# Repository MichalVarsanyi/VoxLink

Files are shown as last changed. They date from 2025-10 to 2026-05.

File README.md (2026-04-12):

# Protocol Parameters
> [!WARNING]  
> Parameters are still subject to change!

- During programming, exceeding internal clocking speeds of 100MHz on the iCE40UL1K-CM36AI FPGA proved to be virtually impossible. In the future, instantiating the hard IP I2C blocks in the FPGA silicon may increase the speed. Realistically, however, switching to a higher speed grade of FPGAs will probably be the best option.

### **Speed**: 50-100 MHz
$$
f_{\mathrm{bandwidth}} = 2 \cdot f_{\mathrm{sensor}} \cdot N_{\mathrm{devices}} \cdot (L_{\mathrm{header}} + L_{\mathrm{data}}) 
$$
$$
9.6 \mathrm{ MHz} = 2 \cdot 1000 \mathrm{ Hz} \cdot 100 \cdot (16 + 32) 
$$

It may seem that 50-100 MHz is unreasonably fast; however, just 40 sensors at 9 kHz get very close to this ballpark. It is difficult to determine what may increase the bandwidth in the future, so it's better to have an excess than to have too little bandwidth. (Resulting bandwidth is double the calculated value to keep a reasonable margin of safety)

$$
34.56 \mathrm{ MHz} = 2 \cdot 9000 \mathrm{ Hz} \cdot 40 \cdot (12 + 32) 
$$

### **Communication**: Full-Duplex 
   - Support for discovery
   - Configuration
### **Host**: 1
### **Sensor Branches from Host**: 10
### **Sensor Branch Length**: To be specified (20? 100?)

<!-- check something like profibus -->
<!-- zdielana zbernica vs serial -->
<!-- master can direct the communication -->
<!-- token approach -->

<!-- daisy chain: -->
<!-- what will be the worst case delay -->

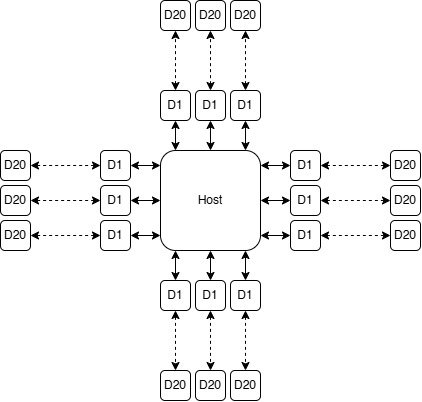
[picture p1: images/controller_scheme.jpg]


# Communication Protocol
### Circular Master-Slave (Daisy Chain)
The Circular Master-Slave protocol offers unprecedented **advantages** when it comes to **timing** and **synchronization**. The Master sends out a packet containing the RX message to the sensor. When the sensor receives the data frame, it reads the content and rewrites it with TX. Each node has a place assigned where it reads and writes data. The discovery would also be easy, as the algorithm would look at the first position, where there are all zeros, and would write its address there. The next sensor would see this as talking and would use the next packet.

The main reason why this protocol **has not been chosen** is the inefficiency when it comes to **different clock domains**. Let's say we have a fast IMU, which sends data at 1 kHz, and the rest of the sensors are tensometers sending data at 10 Hz. Because of the fast link, the tensometers would have to send 99 **empty packets for each data packet**, as the communication would have to happen at the frequency of the fastest link. This wastes the bandwidth, which is of great value when a large number of devices are connected.

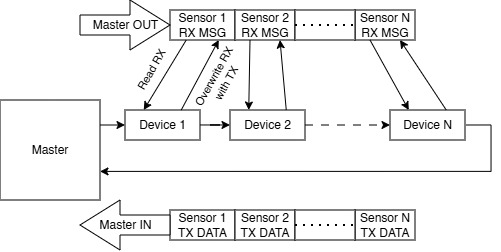
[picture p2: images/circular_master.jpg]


### Direct Master-Slave
The Direct Master-Slave is very **versatile to sampling frequency and packet size variance** between individual nodes. Furthermore, it is easier to negotiate a custom packet size with the slave device. Having the freedom to implement changes like these is invaluable in the prototyping stage. This is why **we will implement this protocol!** Moreover, we are **not wasting bandwidth**, as we are directly talking to the host device with no middleman.

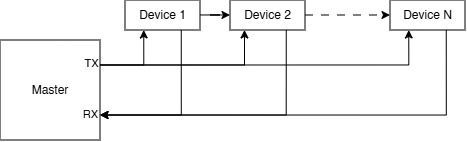
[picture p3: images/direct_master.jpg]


# Protocol Sections
 - Instance ID - Number assigned after self-discovery
 - Board ID - Unique board identifier (can be requested but is not in the header)
 - Timestamp - Identification number of the packet
 - Data

| 12 Bits | 12 Bits | 8 Bits | 64 Bits | 16 Bits |
|:---:|:---:|:---:|:---:|:---:|
| Address | Timestamp | Command | Data | CRC |

# Physical Layer
### Ethernet
Ethernet cables offer great **plug-and-play** connectivity while retaining **excellent signal integrity**. They come in a variety of sizes, however, the older cables do not feature a twisted pair configuration. Furthermore the modern CAT-5 cable is **bulky and difficult to route** inside the Voxel.

### FFC
FFC (Flexible Flat Cable) cables offer **good signal integrity** and can facilitate fast transmission speeds. Their flat profile allows for **easy integration** it the Voxel cells. A disadvantage is **difficult removal/insertion**, which is important for prototype devices. Furthermore, special, shielded cables are rather **expensive**.
## Wire Connections
### 8P8C
- 1-2 - TX
- 3-4 - RX
- 5-6 - CLK
- 7-8 - PWR

### 4P4C (Manchester Encoding)
- 1-2 - TX + Power
- 3-4 - RX

# Microcontroller options
## **Lattice FPGA (iCE40) - (Chosen Platform)**
- **Cost**: 2.22$ to 3$
- **Speed**: 185 MHz
- **Flash Memory**: Used but not needed in the final design

After careful consideration, the **Lattice FPGA** was chosen as the final platform for the sensor board over traditional MCUs. To achieve the target speed in the ballpark of 50 MHz, the microcontrollers would have to be programmed in assembler. In this regard, **Verilog**, in which the FPGA chips will be programmed, is much **easier to read**, understand, and modify. A nice feature is the **integrated NVCM** (Non-Volatile Configuration Memory) inside the FPGA, thus no external SPI Flash NVCM is needed!

Part number: **ICE40UL1K-CM36AI**

##  Rasperry Pi Pico (RP2350)
- **Cost**: 0.90$
- **Speed**: 150 MHz (Neil said 250 MHz overlocking is OK)
- **Flash Memory**: Needed
##  STM32H5
- **Cost**: 2.84$
- **Speed**: 250 MHz
- **Flash Memory**: Not needed

# Hardware Design

## High Level Overview
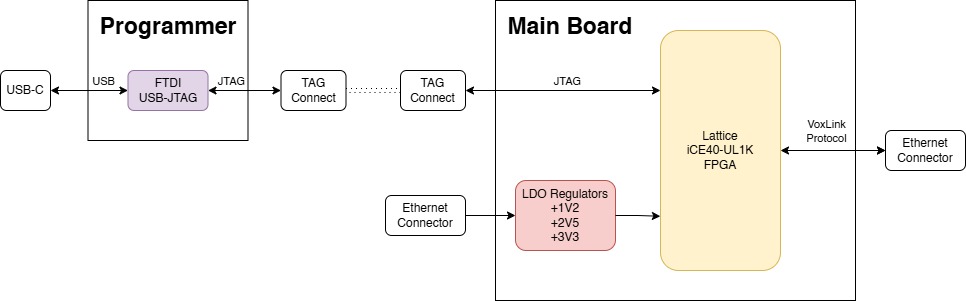
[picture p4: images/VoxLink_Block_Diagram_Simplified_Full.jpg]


### Connector selection
**Rule of thumb: $l_{\mathrm{crit}}$** is $\frac{1}{12}^{\mathrm{th}}$ of a signal wavelength in the dielectric material $\varepsilon$. The effective dielectric constant $\varepsilon$ for an outer-layer trace is approximately 3.3

$$
l_{\mathrm{crit}} \mathrm{ [m]} = \frac{c\mathrm{ [m/s]}}{f_{\mathrm{max}}\mathrm{ [Hz]}} \cdot \frac{1}{\sqrt{\varepsilon}} \cdot \frac{1}{12}
$$

**Rise & fall times rule of thumb:**

$$
f_{\mathrm{max}} \mathrm{ [GHz]} \approx \frac{0.5}{t_{r/f} \mathrm{ [ns]}}
$$

**Clock-to-rise-time rule of thumb:**

$$
t_{r/f} \mathrm{ [ns]}\approx \frac{1}{10\cdot f_{\mathrm{clk}}\mathrm{ [GHz]}}
$$

**Calculation for the maximum protocol clock:**

$$
1 \mathrm{ [ns]}\approx \frac{1}{10\cdot 0.1\mathrm{ [GHz]}}
$$

$$
500 \mathrm{ [MHz]} \approx \frac{0.5}{1 \mathrm{ [ns]}}
$$

$$
27.5 \mathrm{ [mm]} \doteq \frac{3\cdot 10^{8}}{1\cdot 10^{6} \mathrm{ Hz}} \cdot \frac{1}{\sqrt{3.3}} \cdot \frac{1}{12}
$$

This means the transmission line will appear as a **lumped element** (no impedance matching needed as the reflections are negligible) only for **traces shorter than 27.5mm**. Anything **above** this length needs to be treated as a **distributed element** and requires **impedance matching**.

> [!IMPORTANT]
> Impedance control is required for both the cable and the connector assembly!

| Ethernet | USB |
|:---:|:---:|
| 100 Ω ± 15 Ω | 90 Ω ± 5 Ω |

Differential Impedance $Z_{\mathrm{diff}}$ Comparison

$$
Z_{\mathrm{diff}} = 2\cdot (Z_{0}-Z_{\mathrm{coupling}})
$$

## Schematic Diagram - Sensor Board

### eFuse

The eFuse circuit protects the onboard LDOs from excessive overvoltages. The overvoltage protection (OVP) threshold has been set to 5.4V. This gives enough headroom for the absolute maximum voltage of the LDO at 6.5V. The undervoltage lockout (UVLO) threshold has been set to 4V.

**It is crucial for C101 and R101 to be rated at 100V!** Long enough cables can cause surges at the capacitor of over double the input voltage. The limiting resistor will aid in this issue. For further details, refer to the AN88F application note from Analog Devices.

### Power Section

FPGAs require a **specific voltage** to enable their operation. In this design, we are working with 4 different voltage levels:

| 5V | 3.3V | 2.5V | 1.2V |
|:---:|:---:|:---:|:---:|
| Supply voltage from the power cables | The I/O voltages (used by GPIO pins) | The Non-Volatile Configuratio Memory (NVCM) voltage | The FPGA core voltage | 

This version of the board features a 2.5V voltage regulator, which is usually omitted in many designs. The absolute maximum rating of the $V_{\mathrm{PP\_2V5}}$ supplying the NVCM voltage is 2.3V to 3.46V. This enables the pin to be directly connected to the 3.3V voltage regulator. To get the voltage closer to 2.5V, a diode is placed from the 3.3V to the NVCM supply, which facilitates a drop of roughly 0.7V.

There are three I/O banks on the FPGA. The Bank 0, Bank 1, and Bank 2; they all can have different voltage levels connected to them. In this board, all of the I/O banks are running at 3.3V; however, the power is sectioned into VCCIO0, VCCIO1, and VCCIO2. This is to indicate the exact I/O bank that the voltage is tied to, should any future changes be made.

Furthermore, the power supplies are brought up in the order specified in the datasheet. However, I have seen FPGA boards such as the TinyFPGA-BX not follow the correct follow-up sequence. I have also heard that an incorrect power-up sequence will trigger a protection diode on the inside of the FPGA, which can become a problem during prolonged power-up, which is a rather unusual case. Nonetheless, the correct power sequence was programmed using the enable chips. The $\mathrm{V}_{\mathrm{EN(LOW)}} = 0.3 \mathrm{V}$ and $\mathrm{V}_{\mathrm{EN(HIGH)}} = 0.9 \mathrm{V}$, so the 1.2V FPGA core voltage can be used as an enable signal of the next regulator. Below is the datasheet recommendation:

> It is recommended to bring up the power supplies in the following order. Note that there is no specified timing delay
between the power supplies; however, there is a requirement for each supply to reach a level of 0.5 V or higher.
before any subsequent power supplies in the sequence are applied.

- $\mathrm{V} _{\mathrm{CC}}$ and $\mathrm{V} _{\mathrm{CC\_PLL}}$
- $\mathrm{V_{CCIO1\_SPI}}$
- $\mathrm{V} _{\mathrm{PP\_2V5}}$
- Other Supplies

A delay block is introduced to delay the startup of the FPGA chip. This is necessary as the FPGA suggests the memory needs to be ready to accept commands after 10us of the FPGA power-up. Since the NOR flash chip is powered from 3V3, which is the same voltage powering the $\mathrm{SPI-V} _{\mathrm{CCIO1}}$, we need to consider the $t_{VTR} = 150 \mu \mathrm{S}$ which is the time from($\mathrm{V_{CC(MIN)}}$ to Read). The delay value was chosen as 20ms, as the capacitor selection for such a time is 32pF. Having a shorter time means selecting a smaller capacitor, which may become unreliable due to parasitic board capacitances.

### System

In this section, the majority of the FPGA chip is routed. One of the most important parts is the SPI Flash memory. As the Lattice iCE40 UltraLite is a low-cost device, the flash memory peripheral is not programmed by the chip directly. In order to program the FPGA, the $\overline{\mathrm{CRESET}}$ needs to be pulled LOW. This puts the FPGA in reset, and the FLASH_... signals can be used to program the memory. When done, the FPGA reset is de-asserted, and the FPGA loads the configuration from the memory upon power-up.

An external oscillator is used to provide a more stable clock than the integrated FPGA reference clocks. An oscillator needs to be used as the FPGA does not have support for crystal oscillators. The G (GBUF) marking on the pins indicates an internal G-Buf FPGA fabric connection for high-speed routing. This is a special routing layer inside the FPGA that can carry signals up to 185 MHz. The internal system clock, as well as the external clock for the PLL, needs to be connected via this layer.

The VoxLink Ethernet Connection is the physical interface of the sensor board. Currently, the board is configured to utilize the internal differential comparators of the FPGA (A and B pins). Note that the IOB_6A and IOB_7B_G5 form a one differential comparator pair. Ideally, a differential pair will be used to carry the signal to minimize interference. A no-placement (NOP) resistors are used to give the option of a single-ended signal, where the inverted rail can be connected to ground to improve the return path.

### Sensor

The sensor page is the connection of the BNO086 IMU to the FPGA. A reference design from the Adafruit breakout board was chosen.

> CEVA recommends using a crystal with tolerance
50ppm with 12.5pF capacitor loading.

A crystal with a specified load capacitance of 12.5pF and a PPM of 20 was chosen to satisfy the datasheet value. The crystal load capacitors are then calculated based on the following equation:

$$
(12.5p \mathrm{F Load Capacitance} - 5p \mathrm{F Stray Capacitance}) * 2 = 15p \mathrm{F Load Capacitors}
$$

### Connectivity

Two possible architectures were discussed in the earlier sections: the BUS topology and the DAISY chain approach. The sensor evaluation board has an integrated PCIe-Gen4 switch IC, which can rewire the connection from one architecture to another. The images below show the different connections facilitating each approach. Within both architectures, both TX and CLK differential pairs are always connected from the input to the output. This allows us to change the architecture with just one DPDT switch. Having used a dedicated IC, this will ensure better impedance control than using a mechanical switch.

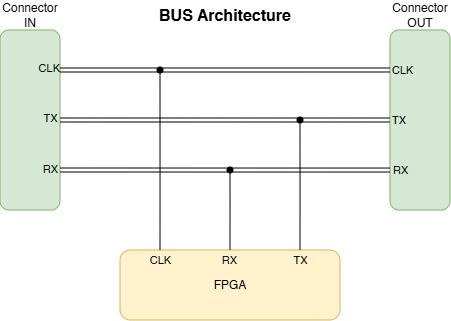
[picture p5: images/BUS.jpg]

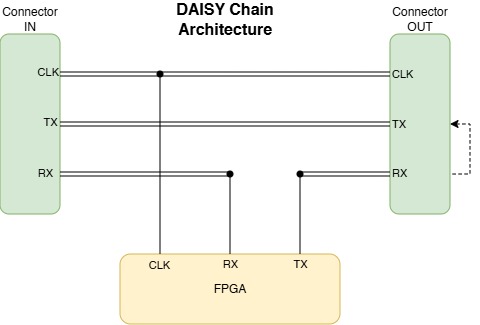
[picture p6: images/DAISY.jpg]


## Schematic Diagram - Programmer Board
An FTDI223HQ IC was used as the serial-to-USB converter. To reduce the overall cost of each sensor board, an external programmer was designed. An EEPROM is attached to the FTDI chip, which can store basic configuration such as the device name and version. This information can be configured using the [FT_Prog](https://ftdichip.com/utilities/#ft_prog) software. A 93LC56B EEPROM IC was selected based on datasheet recommendations, and the chip is merely optional. The FTDI chip does not appear to store any critical information within.

A Tag Connect TC2030-IDC programming cable will be used to program the SPI Flash memory. The pinout of the IDC connector was taken from the datasheet, and the correct pin assignment has to be tested on the hardware implementation, as its correctness is not yet confirmed. An additional 8-pin PicoBlade connector was used to have access to the $\mathrm{CDONE}$ and $\overline{\mathrm{CRESET}}$ signals (the Tag Connect only offers 6 pins), as well as try out different programming interfaces. The manufacturer's evaluation board uses all 8 signals; however, it may be possible to use only 6.

## PCB Layout

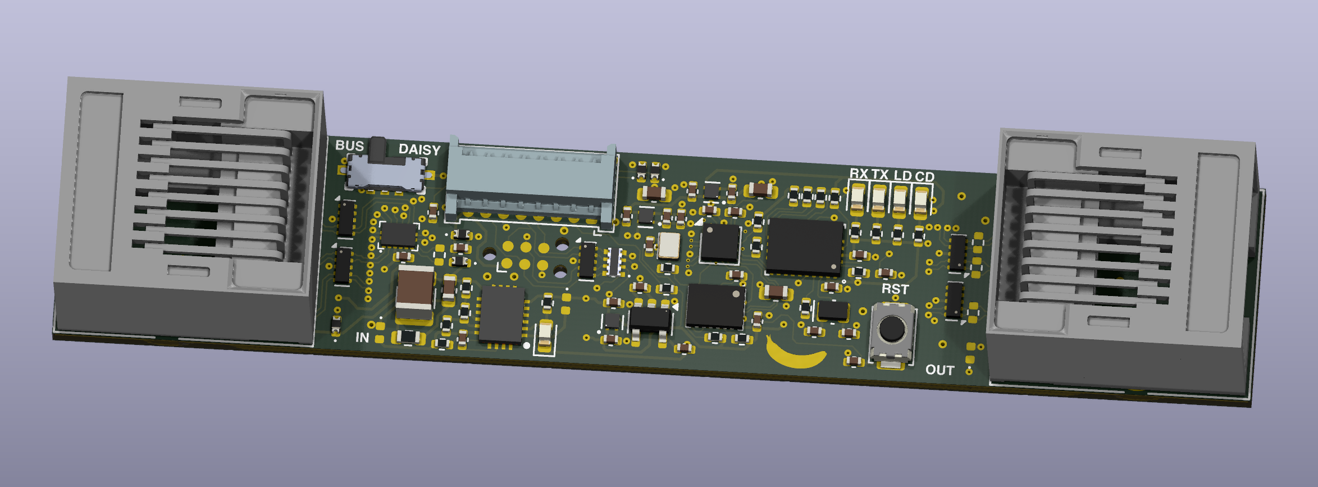
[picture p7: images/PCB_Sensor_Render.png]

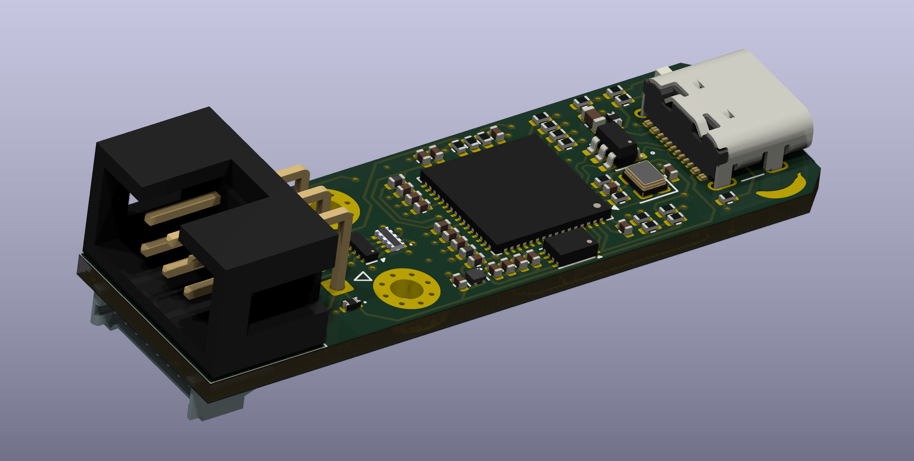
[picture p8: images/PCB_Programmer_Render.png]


### Controlled Impedance

Since Ethernet connectors were used in the design, the differential pairs were routed with a controlled differential impedance of $100 \Omega$. The stackup for both the programmer and the sensor boards can be seen below. An impedance calculator from the PCB manufacturer was used to determine the correct trace parameters. The differential pair trace width used in the design was 0.1mm, and the gap was 0.2mm. 

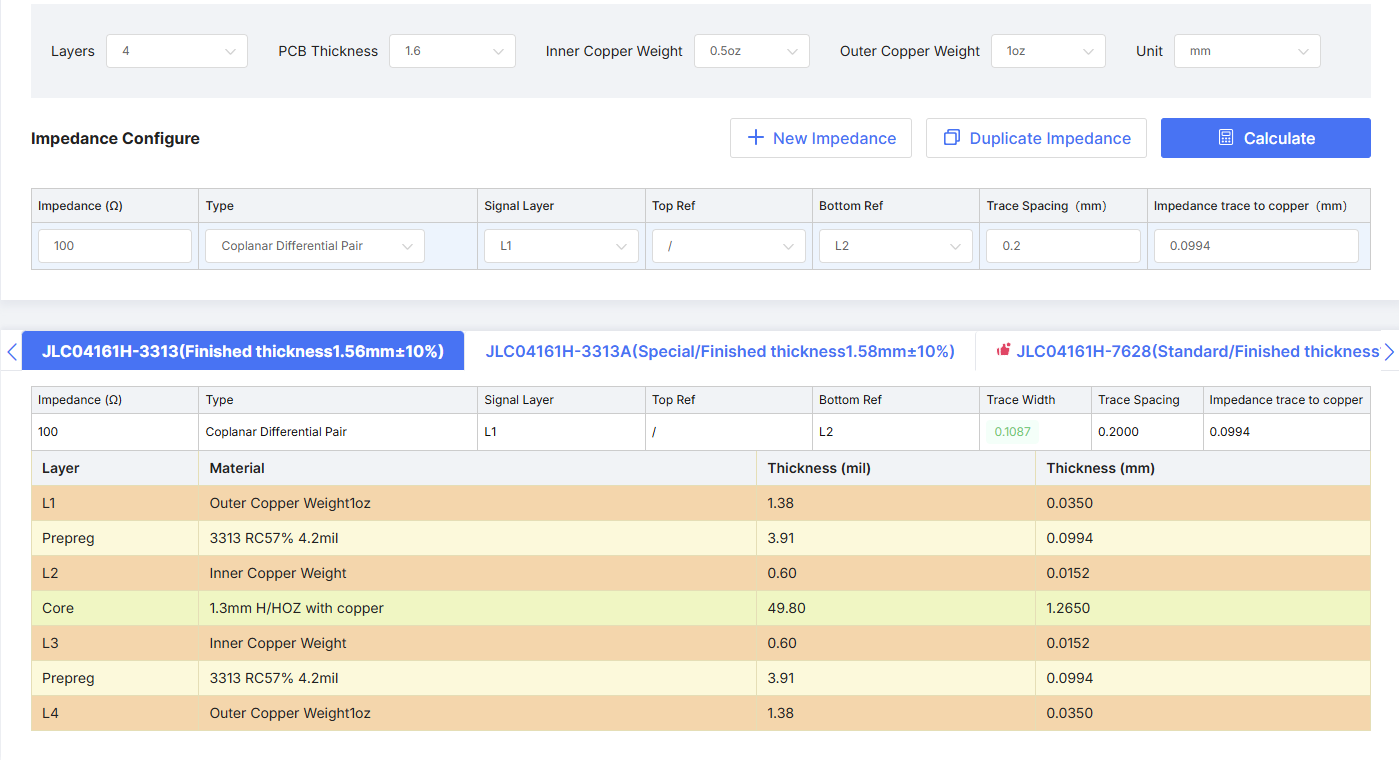
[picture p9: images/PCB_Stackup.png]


### Constraints

The constraints were taken from the manufacturer's capabilities page and copied into KiCad. The exact values can be seen below. In the further section of **PCB Rework** I had to use plugged vias. Even though the annular ring was 0.05mm, the design was still manufacturable, I believe due to the via-in-pad (VIP) being 0.25mm.

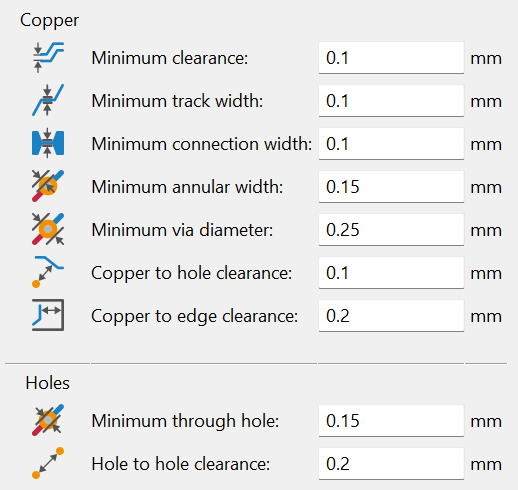
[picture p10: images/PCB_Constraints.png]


### PCB Rework

After talking to the manufacturer, I was informed that the custom BGA footprint I have designed was **not manufacturable**. The pad size I used for the fanout was 0.1mm, and the minimum was 0.25mm, which meant I had to rework my PCB design. Unfortunately, **I had to use capped in-pad vias with 0.15mm drill size** to get around this issue. This is right at the manufacturer's limits, which increases the cost by a few euros; however, I do not see this as a problem with the evaluation design I am ordering. Below is an image provided by JLCPCB engineers of my flawed footprint design.

After submitting the new design, I received another email from the manufacturer asking about the plugged vias. My requirements were **tented epoxy-filled and capped vias** (applied to all via sizes). I also decided to **keep the solder mask opening for all pads and vias**. Removing the solder mask from underneath the BGA would create a more uniform solder layer, as the minimum guaranteed solder bridge is 0.1mm, and I had areas with 0.06mm under the pad. However, I believe the residual solder mask would prevent accidental solder bridges. Nonetheless, for an experimental board, this does not pose a critical problem.

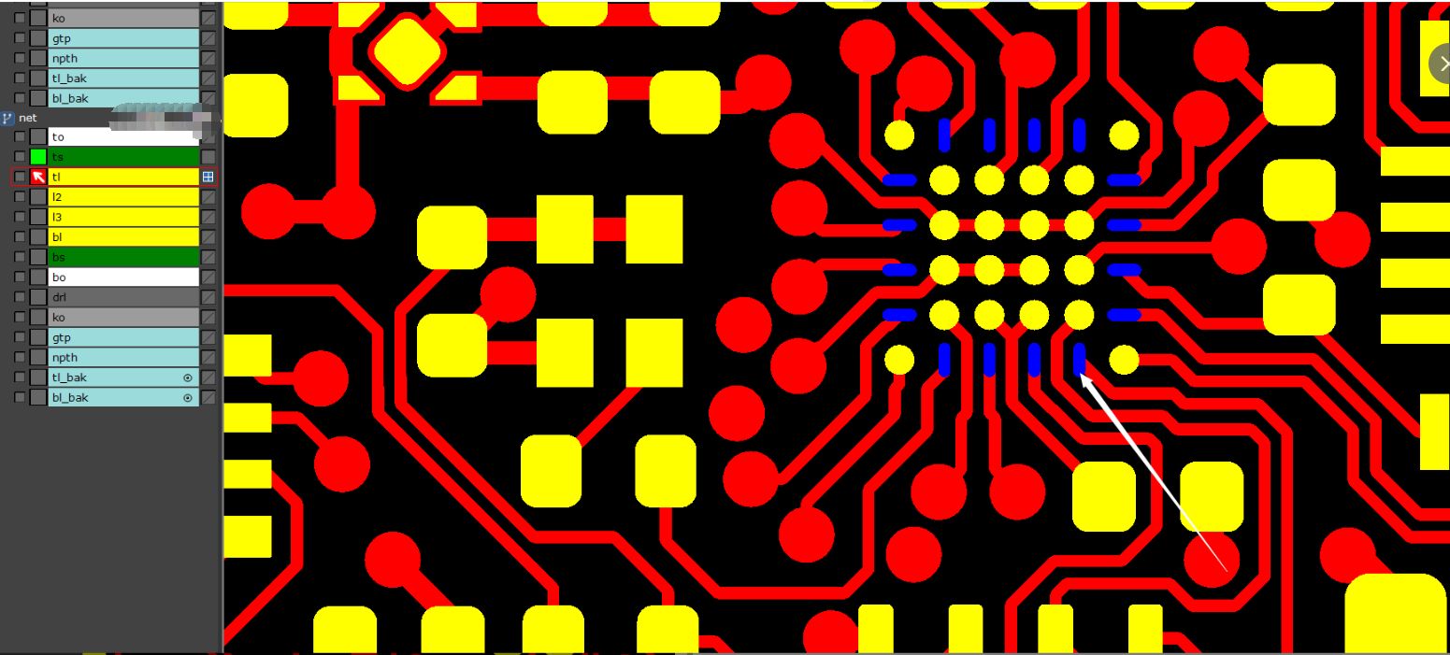
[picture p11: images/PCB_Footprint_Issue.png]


## PCB Review
### Programmer Board
During the PCB assembly, I have found minor issues with the boards. Due to the complexity of the design, this is expected, and the issues will be discussed below. In the programmer board, there is an error in the FT2232H chip connection, where the **REF (Pin 6) pin needs to be connected to GND via a 12k resistor**. Consequently, the **$\overline{\mathrm{RESET}}$ (Pin 14) needs to be connected via a 1k resistor to 3V3**. A minor touch-up would be to add more vias to the exposed pad of the FT2232H chip. Lastly, the IDC connector is a bit difficult to assemble straight, as the pins of the PicoBlade are sticking from the bottom. The final schematic can be seen [here](https://github.com/MichalVarsanyi/VoxLink/blob/main/Hardware/Programmer_Board/schematic.pdf).

### Sensor Board
The sensor board also required minor modifications. First, the D302 Schottky diode was removed, as powering the board via the USB programmer did not cause it to turn on fully. I suspect this stems from the reverse polarity protection on the board, where two Schottky diodes were used. As the ground of the TPS25942 IC is connected through the diodes to the real ground, the added voltage drop (I measured around 0.4V) may have tripped the UVLO protection. **Removing the D302 diode fixed this issue**.

Second, after powering up the board, the FPGA seemed to be in a constant state of reset. This was also indicated by the D308 (CD) LED being turned off. **After removing the U204 time delay block, the FPGA could boot properly**. Currently, the schematic uses a TLV840MADL, which is an open-drain, active-low variant of the TLV840 chip. One possible fix could be to use the TLV840MADH open-drain, active-high variant.

Furthermore, during procurement, the wrong footprint for the following components was ordered:
- C102 - wrong footprint ordered
- C103 - wrong footprint ordered
- R101 - wrong footprint ordered

To see the final schematic, click [here](https://github.com/MichalVarsanyi/VoxLink/blob/main/Hardware/Sensor_Board/schematic.pdf) (Please note that not all the pages are loaded right away. To see the complete schematic, please click the **'More Pages'** button at the bottom of the page)

## Bringup
### Programmer Board
The [FT_Prog](https://ftdichip.com/utilities/#ft_prog) software from FTDI was used to program the name of the programmer shown in the operating system. **It is very important to not to change the Vendor ID (VID) and the Product ID (PID) in the software!** Doing so will make the FTDI drivers not see the programmer, meaning even the FT_Prog software will not be able to detect the device and thus change the values back. **Only change the values in the field shown in the image!**

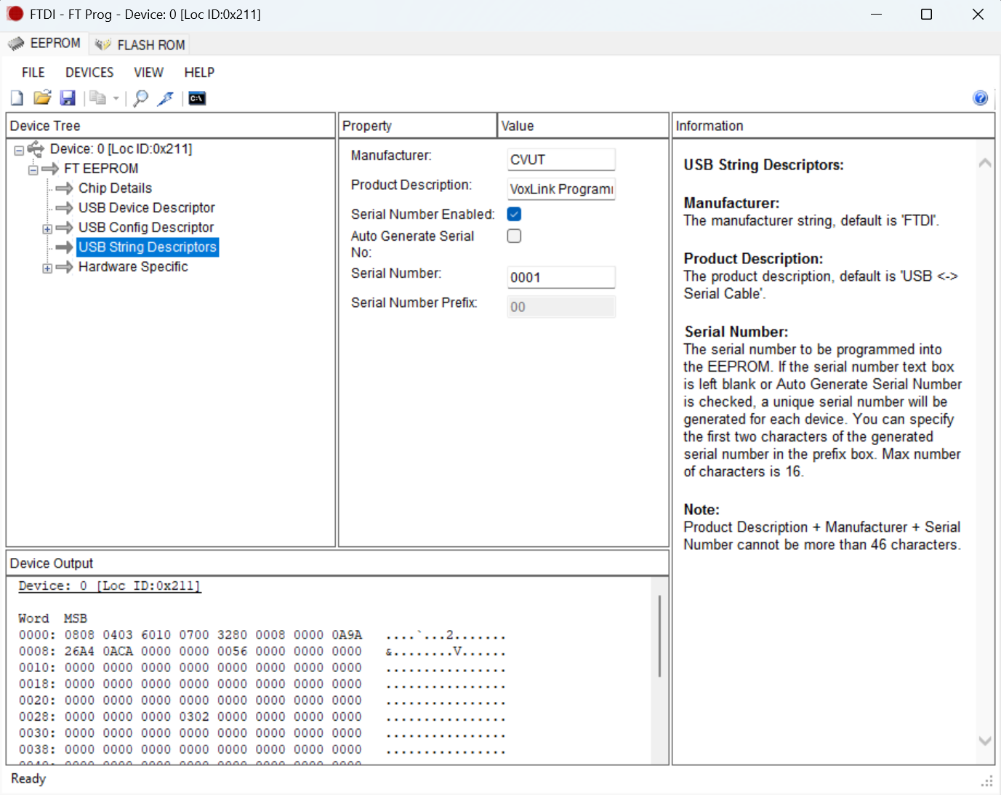
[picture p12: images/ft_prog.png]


### Rolling Back Changes
If this were to happen, there are three possible fixes:
1. Remove the EEPROM, which stores the configuration, and solder in a new one.
2. If you are using Windows, it is possible to download the D2XX drivers from FTDI and add the modified VID and PID in the ftdiport.inf and ftdibus.inf files. Navigate to the device manager and click Update Driver on the programmer device. Choose 'Browse my computer for drivers' and then 'Let me pick from a list of available drivers on my computer', last click on 'Have Disk' and navigate to the folder with the modified drivers. Modifying the files, however, will change the hash, and Windows will refuse to program the device with new drivers. To bypass this, change 'disable driver signature enforcement' during PC restart.
3. This is the option I went with. A colleague of mine using Linux could erase the EEPROM with a simple terminal command.
>sudo apt ftdi-eeprom

>lsusb

The lusb will list the connected devices with their VID and PID numbers. Then erase the EEPROM with the following command. Replace XXXX correcponds with the VID and YYYY with the PID.

>sudo ftdi_eeprom --device i:0xXXXX:0xYYYY --erase-eeprom vars_dev.conf

In the vars_dev.conf, you will set the variables of the EEPROM:

```
vendor_id=0x0403
product_id=0x6010
manufacturer="CVUT"
product="VoxLink Programmer"
serial="0001"
use_serial=true
max_power=250
self_powered=false
remote_wakeup=false
```

### Sensor Board
After creating the project in the iCEcube2 software, create a new project and set the Device Options to the following values.

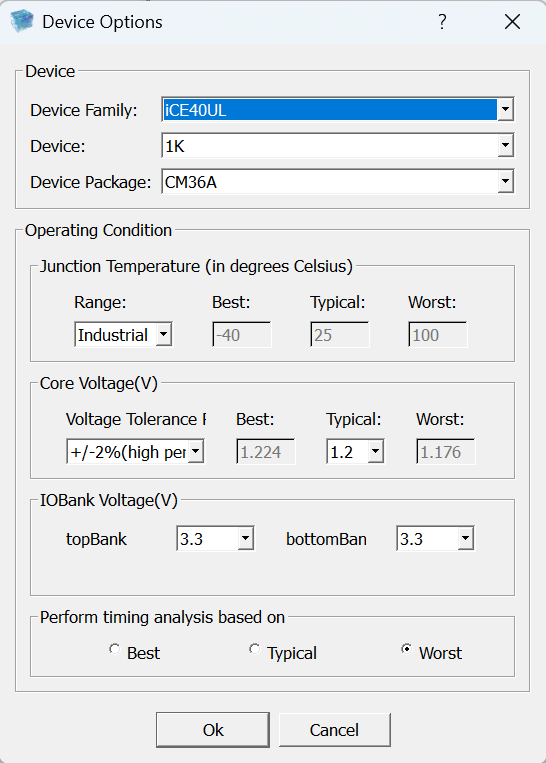
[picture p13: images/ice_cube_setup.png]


Then right-click on the 'Design Files' and then the 'Add Files' button, and add all the Verilog code. Similarly, repeat the same step for the 'Constraint Files' and add the .pfc file.

To run the synthesis, double-click the 'Run Synplify Pro Synthesis' and after it is completed, double-click on the 'Run P&R', which will run the place and router. The generated bitmap file is in the following destination:

>\VoxLink_Protocol_Implmnt\sbt\outputs\bitmap

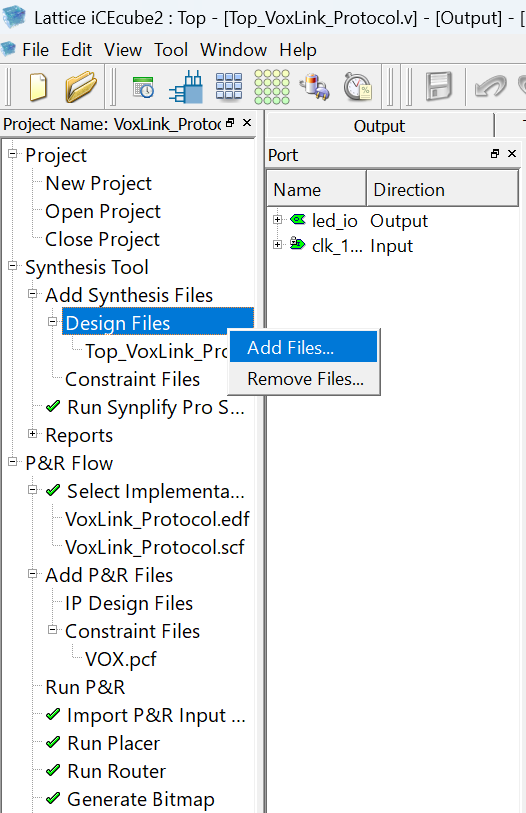
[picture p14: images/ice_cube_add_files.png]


To program the device, download the Diamond Programmer from Lattice and set the Device Family, Device, Operation, and File Name according to the image below. If using the PicoBlade programming port, set the I/O settings on the right as follows. When using the Tag Connect programming cable, the reset button on the sensor board must be held during the programming operation.

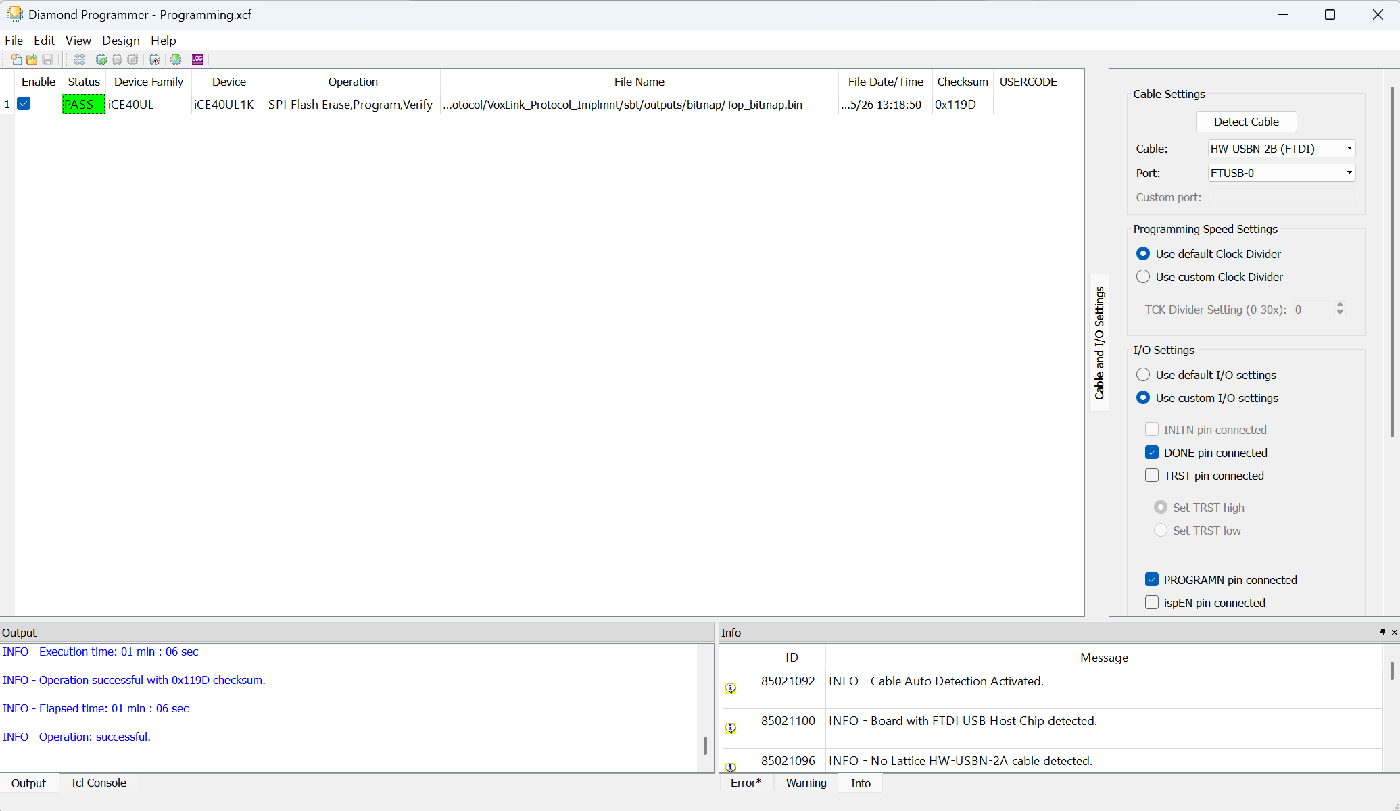
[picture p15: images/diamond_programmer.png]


Here is a video fo a blink sketch I programmed in Verilog to verify the functionality :))



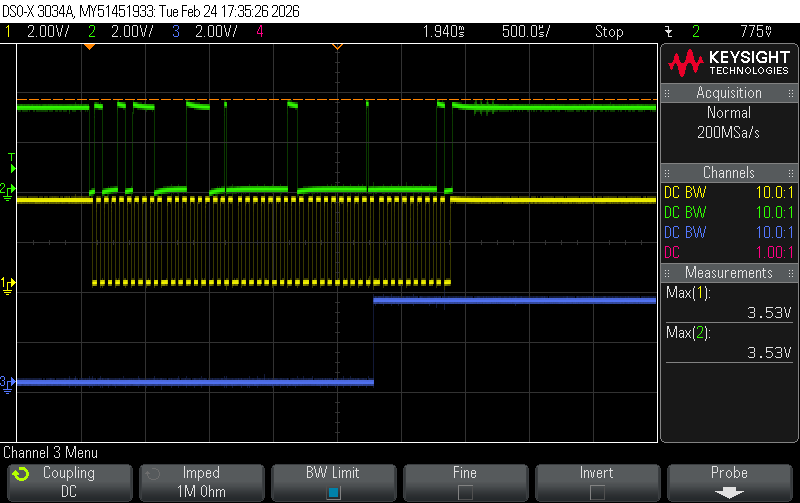
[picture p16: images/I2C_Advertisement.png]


Image of the BNO086 sensor advertisement packet. SDA line is in green, SCL in yelow, and blue indicates the last byte of interest.

## Schematic Diagram - Controller Board

The controller board consists of the following 7 schematic pages: Power, FPGA_Power, FPGA_Config, JTAG, Serial, USB, and Connectivity. In the following sections, the purpose of each page will be outlined.

To see the final schematic, click [here](https://github.com/MichalVarsanyi/VoxLink/blob/main/Hardware/Controller_Board/schematic.pdf) (Please note that not all the pages are loaded right away. To see the complete schematic, please click the **'More Pages'** button at the bottom of the page)

### Power
This section contains switching regulators generating all the necessary voltage levels for the Xilinx FPGA onboard, as well as the sensor board chains. The power can be supplied via an XT30 connector for normal operation or the USB-C for limited-programming tasks. Please note the following restrictions:
> [!CAUTION]
> The **maximum** input voltage is **48V**! The **maximum** input current is **3A**!

> [!WARNING]
> The USB-C power should not be used for operation with multiple sensor boards connected!

The snubber network is designed to handle 100V; however, the 5V switching regulator can handle only 65V. Implementing the snubber greatly reduces the inductive voltage spikes from connecting long cables; however, implementing a 53V working and 63V clamping voltage ESD diode will eliminate ESD events or possible voltage spikes in case the snubber fails to address them.

### FPGA_Power

This section houses decoupling capacitors for the Xilinx FPGA. Due to PCB assembly, the choice was 0201 footprints. The capacitor selection was roughly 1x 100nF per VDD pin. Extra filtering is used for the XADC.

### FPGA_Config

This is the configuration of the FPGA. Some of the following design choices will be explained below:
- The XADC GND was connected to the digital GND for two reasons. In the current design, the XADC is not used. The benefit of having a proper grounding outweighs the benefits of splitting groundplanes at these frequencies.
- The PUDC (FPGA pin E18) is tied HIGH to disable internal pullup resistors during booting
- The current MODE configuration makes the FPGA boot in SPI mode and read from the SPI flash
- Init_b is used to delay the booting. Please refer to the schematic for an explanation of why we don't need to delay this process.

> [!NOTE]
> The JTAG (TDI, TDO, ...) has no signal flipping like UART does

### JTAG

This is the FTDI implementation of the JTAG programming protocol. The schematic is identical to the FT2232H design of the Programming Board; the only difference is the use of FT232H, which is a single-channel version of the FT2232H. Note the different configuration of the power input/output pins. Please refer to the datasheet for VCCD operation (VREGIN = 5V -> VCCD = 3V3 output | VREGIN = 3V3 -> VCCD = 3V3 input).

### Serial

Another FT232H is used to implement a USB 2.0 High-Speed 480Mbit/s transfer link to the PC. The SYNC 245 FIFO mode was used on the FTDI chip. This configuration needs to be configured in the attached EEPROM memory. In the SYNC 245 FIFO mode, the FTDI chips consume all the resources; thus, in the case of FT2232H, the B channel cannot be used. Apart from not being able to implement JTAG on channel B of the FT2232H, the program_ftdi utility provided by Xilinx has no way of signaling that the JTAG is on channel B, restricting the JTAG to channel A. This was the main reason two FTDI chips were used in this design.

### USB

This is the integrated USB hub allowing the two FT232H chips to communicate via a single USB-C connection. It is important to check the USB +/- pairs, as reverting them results in the destruction of the components. The strapping options allow the user to configure the USB hub using just resistors. The default configuration is selected by tying CFG_SEL0 and CFG_SEL1 LOW. Then the NON_REM (non-removable) pins are set to 10, to indicate both of the FTDI chips are non-removable and permanently attached to the HUB IC.

Furthermore, the FT232H is connected in a way to allow the implementation of UART to Serial bridge, which minimizes testing time. Please note that UART  will be implemented in the first implementation of VoxLink.

### Connectivity

This is the physical interface for the sensor boards to terminate their connections. The shielded RJ45 connectors were chosen in order to provide a rugged and impedance-matched termination.

> [!NOTE]
> The Controller Board is designed to work with LVDS signaling and with transfer speeds up to 100MBit/s

> [!CAUTION]
> Two RJ45 connectors connected to Xilinx FPGA BANK 35 **DO NOT SUPPORT LVDS** signaling and are **3.3V ONLY**! Do **NOT** connect LVDS logic to these ports!

Although LVDS signaling is supported by the RJ45 twisted wire pair terminations, single-ended transmission will be implemented in the first implementation of VoxLink.

### Schedule

- **Controller Board Development Deadline** - 25rd of March
   - Finished Schematic Design - 17th of March
   - Finished PCB Design - 29th of March
- **Sensor Board Core Module Deadline**     - 30th of March
   - Finished Lattice Design - 1st of April
- **Sensor Shell Module Deadline** - 4th of April
   - Finished BNO086 Design - 2nd of April
   - Finished BUS Shell     - 2nd of April
   - Finished DAISY Shell   - 2nd of April
- **VoxLink Protocol Development**
1. CRC implementation
2. Timestamp, address, and command implementation
3. Core module flyby + data append mechanism
4. Core/Controller board receive
5. Communication with PC (structure) + miscellaneous
6. Board bringup

- **Thesis Outline**
1. Introduction
2. State of the Art
3. Engineering Requirements
4. Hardware
5. Firmware
6. Testing

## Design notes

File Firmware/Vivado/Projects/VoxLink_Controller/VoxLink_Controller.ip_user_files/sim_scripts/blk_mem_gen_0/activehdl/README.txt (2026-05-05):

################################################################################
# Vivado (TM) v2024.1 (64-bit)
#
# README.txt: Please read the sections below to understand the steps required to
#             run the exported script and how to fetch design source file details
#             from the file_info.txt file.
#
# Generated by export_simulation on Tue May 05 16:34:52 +0200 2026
#
################################################################################

1. Steps to run the generated simulation script

From the shell prompt in the current directory, issue the following command:-

./blk_mem_gen_0.sh

This command will launch the 'compile', 'elaborate' and 'simulate' functions
implemented in the script file for the 3-step flow. These functions are called
from the main 'run' function in the script file.

The 'run' function first calls the 'check_args' function, the purpose of which
is to verify the generated script arguments and print error if incorrect switch
is specified. The 'run' function then calls the 'setup' function, the purpose of
which is to specify custom or initialization commands. The function also executes
following sub-functions:-
'reset_run' if -reset_run switch is specified.
'reset_log' if -reset_log switch is specified.

The purpose of 'reset_run' function' is to delete the simulator generated design
data from the previous run and the purpose of 'reset_log' function' is to delete
the simulator generated log files.

The 'run' function then calls the 'init_lib' function, the purpose of which is to
create design library mappings and directories. This function is called before the
'compile' step. By default, if '-step' switch is specified with the script then the
script will execute that specfic step, else it will execute all steps applicable
for the target simulator.

For more information on the script, please type './blk_mem_gen_0.sh -help'

2. Design source file information

export_simulation generates a 'file_info.txt' file that contains design file information
based on the compile order when export_simulation was executed from Vivado. The file
contains information about the file name, type, library it is compiled into, whether
it is part of the IP, associated library, file path information in a comma separated
format. This file can be parsed to extract the required information for generating a
custom script or can be read from verification test infra.

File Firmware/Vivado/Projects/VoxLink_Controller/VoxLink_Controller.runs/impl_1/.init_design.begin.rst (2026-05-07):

<?xml version="1.0"?>
<ProcessHandle Version="1" Minor="0">
    <Process Command=".planAhead." Owner="varsa" Host="LAPTOP-GK6ER3TV" Pid="27616">
    </Process>
</ProcessHandle>

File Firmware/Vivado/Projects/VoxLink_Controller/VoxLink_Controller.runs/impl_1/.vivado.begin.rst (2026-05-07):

<?xml version="1.0"?>
<ProcessHandle Version="1" Minor="0">
    <Process Command="vivado.bat" Owner="varsa" Host="LAPTOP-GK6ER3TV" Pid="27040" HostCore="22" HostMemory="033736019968">
    </Process>
</ProcessHandle>

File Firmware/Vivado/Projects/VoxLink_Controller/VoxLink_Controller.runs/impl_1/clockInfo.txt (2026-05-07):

-------------------------------------
| Tool Version : Vivado v.2024.1
| Date         : Thu May  7 17:31:05 2026
| Host         : LAPTOP-GK6ER3TV
| Design       : design_1
| Device       : xc7a35t-csg324-1--
-------------------------------------

For more information on clockInfo.txt clock routing debug file see https://support.xilinx.com/s/article/000035660?language=en_US

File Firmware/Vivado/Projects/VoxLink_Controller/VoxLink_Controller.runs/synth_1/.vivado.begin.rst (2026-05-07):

<?xml version="1.0"?>
<ProcessHandle Version="1" Minor="0">
    <Process Command="vivado.bat" Owner="varsa" Host="LAPTOP-GK6ER3TV" Pid="3820" HostCore="22" HostMemory="033736019968">
    </Process>
</ProcessHandle>

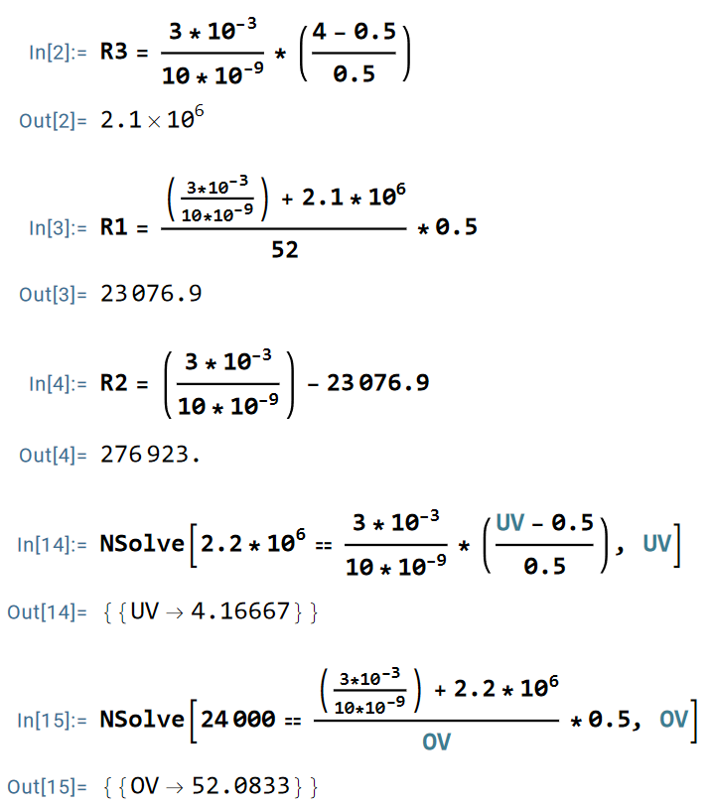
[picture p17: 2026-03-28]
Hardware/Controller_Board/images/uvov.png

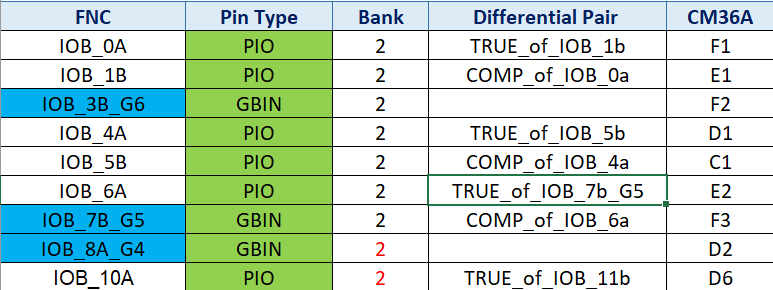
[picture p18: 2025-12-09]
Hardware/Sensor_Board/images/diff_paris.png

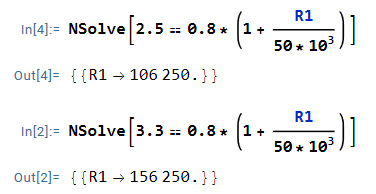
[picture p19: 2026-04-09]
Hardware/Controller_Board/images/fb_res2.png

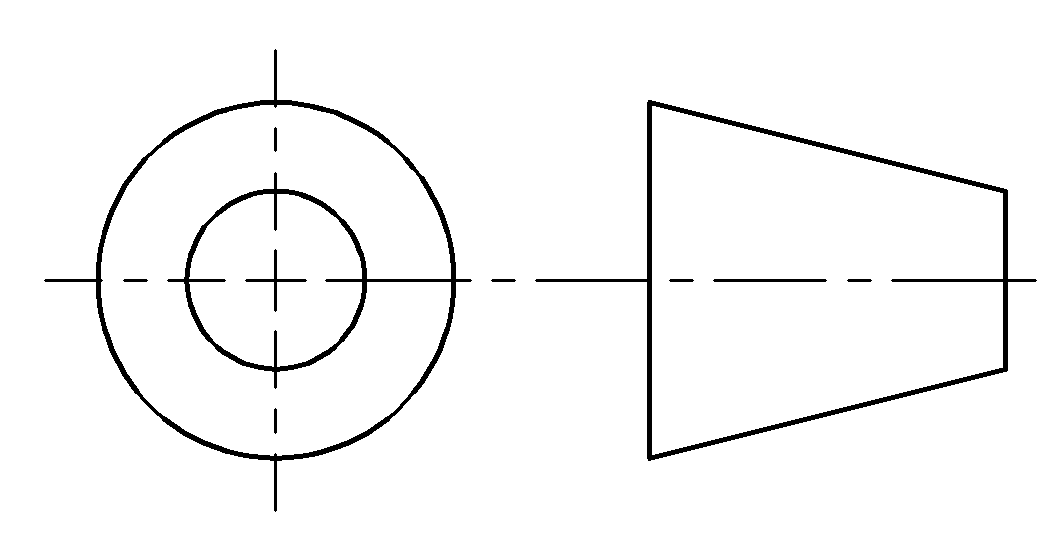
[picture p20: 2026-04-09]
Mechanical/images/first_angle.png

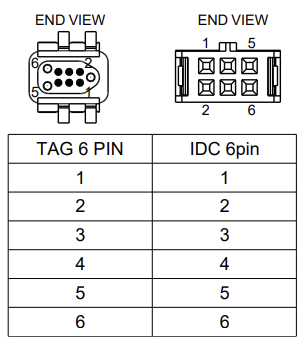
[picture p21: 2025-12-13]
Hardware/Programmer_Board/images/idc.png

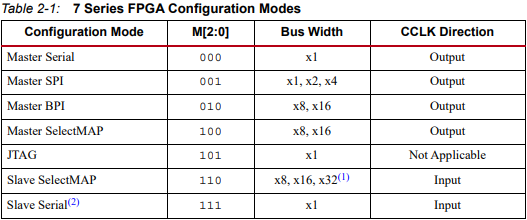
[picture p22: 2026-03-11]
Hardware/Controller_Board/images/mode.png

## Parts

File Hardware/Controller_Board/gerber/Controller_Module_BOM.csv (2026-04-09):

Designator | Qty | Comment | LCSC | Footprint | Datasheet | Manufacturer | DNP | Exclude from BOM | Exclude from Board
C101,C220 | 2 | 4.7u | C2997285 | Capacitor_SMD:C_1206_3216Metric | https://www.lcsc.com/product-detail/C2997285.html | Murata
C102,C221,C222 | 3 | 100n | C85866 | Capacitor_SMD:C_0805_2012Metric | https://www.lcsc.com/product-detail/C85866.html | Murata
C103,C224,C709,C711 | 4 | 10n | C77019 | Capacitor_SMD:C_0402_1005Metric | https://www.lcsc.com/product-detail/C77019.html | Murata
C104,C402,C403,C502,C503,C504,C505,C506,C507,C509,C510,C512,C513,C602,C603,C604,C605,C606,C607,C609,C610,C612,C613,C702,C703,C704,C705,C706,C707,C708,C710,C712 | 32 | 100n | C77020 | Capacitor_SMD:C_0402_1005Metric | https://www.lcsc.com/product-detail/C77020.html | Murata
C201,C202,C213,C214,C225,C226,C229,C230 | 8 | 22u | C5116073 | Capacitor_SMD:C_0603_1608Metric | https://www.lcsc.com/product-detail/C5116073.html | Murata
C203,C204,C205,C206,C207,C208,C209,C210,C211,C212,C215,C216,C218,C219,C227,C228,C231,C232 | 18 | 100u | C883598 | Capacitor_SMD:C_1206_3216Metric | https://www.lcsc.com/product-detail/C883598.html | Murata
C217 | 1 | 22u | C86816 | Capacitor_SMD:C_0805_2012Metric | https://www.lcsc.com/product-detail/C86816.html | Murata
C223 | 1 | 2.2p | C88886 | Capacitor_SMD:C_0402_1005Metric | https://www.lcsc.com/product-detail/C88886.html | Murata
C301,C302,C305,C306,C307,C308,C309,C310,C311,C312,C313,C314,C315,C316,C318,C319,C320,C321,C322,C323,C324,C325,C326,C327,C328,C329,C330,C332,C335,C336,C337,C338,C339,C340,C341,C342,C343,C344,C347,C348,C349,C350,C351,C352,C353,C354 | 46 | 100n | C668346 | Capacitor_SMD:C_0201_0603Metric | https://www.lcsc.com/product-detail/C668346.html | Murata
C303,C304,C317,C331,C333,C334,C345,C346,C355,C508,C511,C608,C611 | 13 | 10u | C194427 | Capacitor_SMD:C_0603_1608Metric | https://www.lcsc.com/product-detail/C194427.html | Murata
C401 | 1 | 1u | C528974 | Capacitor_SMD:C_0402_1005Metric | https://www.lcsc.com/product-detail/C528974.html | Murata
C501,C601,C701 | 3 | 10u | C237493 | Capacitor_SMD:C_0805_2012Metric | https://www.lcsc.com/product-detail/C237493.html | Murata
C514,C515,C614,C615,C713,C714 | 6 | 10p | C76946 | Capacitor_SMD:C_0402_1005Metric | https://www.lcsc.com/product-detail/C76946.html | Murata
D201,D401,D704 | 3 | LED | C18198801 | LED_SMD:LED_0603_1608Metric | https://www.lcsc.com/product-detail/C18198801.html | Broadcom
D701 | 1 | Schottky | C5636538 | Diode_SMD:D_SOD-323F | https://www.lcsc.com/product-detail/C5636538.html?s_z=n_CUHS20S30%252CH3F | Toshiba
D702,D703,D801,D802,D803,D804,D805,D806,D807,D808,D809 | 11 | TVS | C1973340 | Diode_SMD:D_0402_1005Metric | https://www.lcsc.com/product-detail/C1973340.html?s_z=n_SESD0402X1UN-0020-090 | Littelfuse
FB301 | 1 | 600R/100MHz | C237542 | Inductor_SMD:L_0201_0603Metric | https://www.lcsc.com/product-detail/C237542.html | Murata
FB501,FB502,FB601,FB602 | 4 | 600R | C160977 | Inductor_SMD:L_0402_1005Metric | https://www.lcsc.com/product-detail/C160977.html | Murata
J701 | 1 | USB-C | C5184243 | Connector_USB:USB_C_Receptacle_GCT_USB4105-xx-A_16P_TopMnt_Horizontal | https://www.lcsc.com/product-detail/C5184243.html?s_z=n_USB4105-GF-A | GCT
L201 | 1 | 2u2 | C3911448 | Inductor_SMD:L_Coilcraft_XAL6030-XXX | https://www.lcsc.com/product-detail/C3911448.html?s_z=n_C3911448 | Coilcraft
Q101 | 1 | Si7252ADP | C3289528 | Package_SO:PowerPAK_SO-8_Dual | https://www.lcsc.com/product-detail/C3289528.html?s_z=n_Si7252ADP | Vishay
Q201 | 1 | DMN2400UFB-7 | C154757 | Package_DFN_QFN:Diodes_DFN1006-3 | https://www.mouser.sk/ProductDetail/Diodes-Incorporated/DMN2400UFB-7?qs=gfe7vQ8txpX552mKXpqKow%3D%3D
R101 | 1 | 17mOhm 1/2W | C201283 | Resistor_SMD:R_1206_3216Metric_Pad1.30x1.75mm_HandSolder | https://www.lcsc.com/product-detail/C201283.html | Walter
R102 | 1 | 1R | C445774 | Resistor_SMD:R_0603_1608Metric | https://www.lcsc.com/product-detail/C445774.html | Panasonic
R103 | 1 | 22k | C482105 | Resistor_SMD:R_0402_1005Metric | https://www.lcsc.com/product-detail/C482105.html | Vishay
R104,R105 | 2 | 1.1Meg | C2076674 | Resistor_SMD:R_0402_1005Metric | https://www.lcsc.com/product-detail/C2076674.html | Vishay
R106 | 1 | 280k | C4198226 | Resistor_SMD:R_0402_1005Metric | https://www.lcsc.com/product-detail/C4198226.html | Vishay
R107 | 1 | 23.2k | C2076557 | Resistor_SMD:R_0402_1005Metric | https://www.lcsc.com/product-detail/C2076557.html | Vishay
R201,R204,R210,R214 | 4 | 499k | C482187 | Resistor_SMD:R_0402_1005Metric | https://www.lcsc.com/product-detail/C482187.html | Vishay
R202 | 1 | 12.4k | C1730790 | Resistor_SMD:R_0402_1005Metric | https://www.lcsc.com/product-detail/C1730790.html | Vishay
R203,R207,R212,R216 | 4 | 49.9k | C350874 | Resistor_SMD:R_0402_1005Metric | https://www.lcsc.com/product-detail/C350874.html | Vishay
R205 | 1 | 61.9k | C4023393 | Resistor_SMD:R_0402_1005Metric | https://www.lcsc.com/product-detail/C4023393.html | Vishay
R206 | 1 | 1Meg | C4334825 | Resistor_SMD:R_0402_1005Metric | https://www.lcsc.com/product-detail/C4334825.html | Vishay
R208 | 1 | 243k | C2092035 | Resistor_SMD:R_0402_1005Metric | https://www.lcsc.com/product-detail/C2092035.html | Vishay
R209 | 1 | 41.2k | C844310 | Resistor_SMD:R_0402_1005Metric | https://www.lcsc.com/product-detail/C844310.html | Vishay
R211,R215 | 2 | 154k | C2085327 | Resistor_SMD:R_0402_1005Metric | https://www.lcsc.com/product-detail/C2085327.html | Vishay
R213 | 1 | 280R | C4193696 | Resistor_SMD:R_0402_1005Metric | https://www.lcsc.com/product-detail/C4193696.html | Vishay
R401 | 1 | 200R | C482094 | Resistor_SMD:R_0402_1005Metric | https://www.lcsc.com/product-detail/C482094.html | Vishay
R402 | 1 | 100R | C844502 | Resistor_SMD:R_0402_1005Metric | https://www.lcsc.com/product-detail/C844502.html | Vishay
R403,R404,R405,R406,Re401,Re402 | 6 | 4.7k | C3000902 | Resistor_SMD:R_0201_0603Metric | https://www.lcsc.com/product-detail/C3000902.html | Vishay
R407,R408,R409,R410 | 4 | 4.7k | C482193 | Resistor_SMD:R_0402_1005Metric | https://www.lcsc.com/product-detail/C482193.html | Vishay
R411,R507,R607,R711 | 4 | 22R | C482106 | Resistor_SMD:R_0402_1005Metric | https://www.lcsc.com/product-detail/C482106.html | Vishay
R501,R601,R701,R704,R801,R802,R803,R804,R805,R806,R807,R808,R809,R810,R811,R812,R813,R814,R815,R816,R817,R818 | 22 | 1k | C71623 | Resistor_SMD:R_0402_1005Metric | https://www.lcsc.com/product-detail/C71623.html | Vishay
R502,R503,R504,R505,R602,R603,R604,R605,R705 | 9 | 12k | C481938 | Resistor_SMD:R_0402_1005Metric | https://www.lcsc.com/product-detail/C481938.html | Vishay
R506,R606 | 2 | 2k2 | C82680 | Resistor_SMD:R_0402_1005Metric | https://www.lcsc.com/product-detail/C82680.html | Vishay
R702,R703 | 2 | 5k1 | C482289 | Resistor_SMD:R_0402_1005Metric | https://www.lcsc.com/product-detail/C482289.html | Vishay
R706,R707,R708,R709,R710,R712 | 6 | 100k | C481918 | Resistor_SMD:R_0402_1005Metric | https://www.lcsc.com/product-detail/C481918.html | Vishay
SW401 | 1 | Reset | C202388 | Button_Switch_SMD:SW_Push_SPST_NO_Alps_SKRK | https://www.lcsc.com/product-detail/C202388.html?s_z=n_SKRKAHE020 | Alps
U101 | 1 | TDS5311P | C9900267203 | Package_DFN_QFN:DFN-6-1EP_2x2mm_P0.65mm_EP1x1.6mm | https://www.mouser.sk/ProductDetail/Semtech/TDS5311P.C?qs=vcFyY%252BOcAyj8qKAYi7WPvA%3D%3D | Semtech
U102 | 1 | LTC4368 | C688380 | Package_DFN_QFN:DFN-10-1EP_3x3mm_P0.5mm_EP1.65x2.38mm | https://www.mouser.sk/ProductDetail/Analog-Devices/LTC4368CDD-1PBF?qs=5aG0NVq1C4zMmIHFyUxB3A%3D%3D | ADI
U103 | 1 | XT30 | C431092 | Connector_AMASS:AMASS_XT30PW-M_1x02_P2.50mm_Horizontal | https://www.lcsc.com/product-detail/C431092.html?s_z=n_xt30 | Amass
U201,U202,U204,U205 | 4 | TPS82084 | C468248 | Package_LGA:Texas_SIL0008C_MicroSiP-8-1EP_2.8x3mm_P0.65mm_EP1.1x1.9mm | https://www.mouser.sk/ProductDetail/Texas-Instruments/TPS82084SILR?qs=B%252B1bdHOmWBNXeIIho8%2F7ng%3D%3D | TI
U203 | 1 | LT8645S | C674140 | Custom_VoxLink_Footprints:LQFN-32-6EP_6x4mm_P0.5mm_EP1.355x1.125mm | https://www.mouser.sk/ProductDetail/Analog-Devices/LT8645SIVPBF?qs=5aG0NVq1C4x%2FSi81lib%2FvQ%3D%3D | ADI
U301 | 1 | XC7A35T-CSG324 | C1521726 | Package_BGA:Xilinx_CSG324 | https://www.mouser.sk/ProductDetail/AMD-Xilinx/XC7A35T-1CSG324I?qs=rrS6PyfT74dF9W6kMEMeIQ%3D%3D | Xilinx
U401 | 1 | IS25LP256D | C1350139 | Custom_VoxLink_Footprints:WSON-8-1EP_8.0x6.0mm_P1.27mm_EP4.7x4.6mm | https://www.mouser.sk/ProductDetail/ISSI/IS25LP256D-JLLE?qs=o7k0yqUNuKBtHG3%252BsElLAA%3D%3D | ISSI
U501 | 1 | SN74AXC4T774 | C1849454 | Package_DFN_QFN:UQFN-16_1.8x2.6mm_P0.4mm | https://www.mouser.sk/ProductDetail/Texas-Instruments/SN74AXC4T774RSVR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 | TI
U502,U601 | 2 | FT232H | C82158 | Package_DFN_QFN:QFN-48-1EP_8x8mm_P0.5mm_EP6.2x6.2mm | https://ftdichip.com/wp-content/uploads/2025/11/DS_FT232H.pdf | FTDI
U503,U602 | 2 | 93LC56B | C616589 | Package_DFN_QFN:TDFN-8-1EP_3x2mm_P0.5mm_EP1.3x1.4mm | https://www.lcsc.com/product-detail/C616589.html?s_z=n_C616589 | Microchip
U701 | 1 | ESD122 | C544474 | Custom_VoxLink_Footprints:X2SON-3 | https://www.mouser.sk/ProductDetail/Texas-Instruments/ESD122DMXR?qs=gt1LBUVyoHlO%2FS8I%252Bb9aFA%3D%3D | TI
U702 | 1 | USB2512B | C144303 | Package_DFN_QFN:QFN-36-1EP_6x6mm_P0.5mm_EP3.7x3.7mm | https://www.mouser.sk/ProductDetail/Microchip-Technology/USB2512B-I-M2?qs=uus7iwvxYD8%2FmTpAijPQAQ%3D%3D | Microchip
U801,U802,U803,U810,U811,U812,U819,U820,U821 | 9 | RJ45 | C125068 | Custom_VoxLink_Footprints:TE_RJ45 | https://www.lcsc.com/product-detail/C125068.html?s_z=n_C125068 | TE
U804,U805,U806,U807,U808,U809,U813,U814,U815,U816,U817,U818,U822,U823,U824,U825,U826,U827 | 18 | TPD4E02B04 | C106794 | Package_SON:USON-10_2.5x1.0mm_P0.5mm | https://www.lcsc.com/product-detail/C106794.html?s_z=n_C106794 | TI
Y401,Y501,Y601 | 3 | 12MHz | C17361989,C6372529 | Crystal:Crystal_SMD_2520-4Pin_2.5x2.0mm | https://www.lcsc.com/product-detail/C17361989.html,https://www.lcsc.com/product-detail/C6372529.html | ECS
Y701 | 1 | 24MHz | C6941895 | Crystal:Crystal_SMD_2520-4Pin_2.5x2.0mm | https://www.lcsc.com/product-detail/C6941895.html | ECS

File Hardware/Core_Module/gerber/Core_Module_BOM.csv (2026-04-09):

Designator | Qty | Comment | DNP | Exclude from BOM | Exclude from Board | LCSC | Footprint | Datasheet | Manufacturer
C101,C103,C107,C112,C113,C116 | 6 | 100n |  |  |  | C668346 | Capacitor_SMD:C_0201_0603Metric | https://www.lcsc.com/product-detail/C668346.html | Murata
C104,C105,C108,C109,C114,C115 | 6 | 1u |  |  |  | C335102 | Capacitor_SMD:C_0201_0603Metric | https://www.lcsc.com/product-detail/C335102.html | Murata
C110 | 1 | 2.2u |  |  |  | C335106 | Capacitor_SMD:C_0201_0603Metric | https://www.lcsc.com/product-detail/C335106.html | Murata
D101,D102 | 2 | LED |  |  |  | C4153580,C5846955 | LED_SMD:LED_0201_0603Metric | https://www.lcsc.com/product-detail/C4153580.html,https://www.lcsc.com/product-detail/C5846955.html | Kingbright
D201,D202,D203,D204,D205,D206,D207,D209,D210,D211,D212,D213,D214,D215,D216,D217,D218,D219,D220,D221,D222,D223,D224,D225,D226 | 25 | TVS |  |  |  | C2939949 | Custom_VoxLink_Footprints:WLL-2-3 | https://www.lcsc.com/product-detail/C2939949.html | Infineon
D208 | 1 | TSV |  |  |  | C2939949 | Custom_VoxLink_Footprints:WLL-2-3 | https://www.lcsc.com/product-detail/C2939949.html | Infineon
R101 | 1 | 22R |  |  |  | C3009113 | Resistor_SMD:R_0201_0603Metric | https://www.lcsc.com/product-detail/C3009113.html | Vishay
R103,R106 | 2 | 499R |  |  |  | C2094902 | Resistor_SMD:R_0201_0603Metric | https://www.lcsc.com/product-detail/C2094902.html | Vishay
R104,R105 | 2 | 10k |  |  |  | C844303 | Resistor_SMD:R_0201_0603Metric | https://www.lcsc.com/product-detail/C844303.html | Vishay
U101 | 1 | TPS7A20L_1V2 |  |  |  | C30875939 | Package_SON:Texas_X2SON-4_1x1mm_P0.65mm | https://www.lcsc.com/product-detail/C30875939.html?s_z=n_C30875939 | TI
U102 | 1 | ICE40UL1K-CM36AI |  |  |  | C1519040 | Package_BGA:UCBGA-36_2.5x2.5mm_Layout6x6_P0.4mm | https://www.lcsc.com/product-detail/C1519040.html?s_z=n_C1519040 | Lattice
U103 | 1 | TPS7A20L_2V5 |  |  |  | C41487851 | Package_SON:Texas_X2SON-4_1x1mm_P0.65mm | https://www.lcsc.com/product-detail/C41487851.html?s_z=n_TPS7A20225PDQNR%2520 | TI
U104 | 1 | TPS7A20L_3V3 |  |  |  | C22445532 | Package_SON:Texas_X2SON-4_1x1mm_P0.65mm | https://www.lcsc.com/product-detail/C22445532.html?s_z=n_TPS7A20L33PDQNR | TI
U105 | 1 | W25Q32JV |  |  |  | C2999380 | Custom_VoxLink_Footprints:U-PDFN-8 | https://www.lcsc.com/product-detail/C2999380.html?s_z=n_W25Q32JVUUIQ | Winbond
Y101 | 1 | 12MHz |  |  |  | SMD1612-4P | Oscillator:Oscillator_SMD_Abracon_ASCO-4Pin_1.6x1.2mm | https://www.lcsc.com/product-detail/C2032475.html | Abracon

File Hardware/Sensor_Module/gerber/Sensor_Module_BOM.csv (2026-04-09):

Designator | Qty | Comment | DNP | Exclude from BOM | Exclude from Board | LCSC | Footprint | Datasheet | Manufacturer
C1,C2,C5 | 3 | 100n |  |  |  | C77020 | Capacitor_SMD:C_0402_1005Metric | https://www.lcsc.com/product-detail/C77020.html | Murata
C3,C4 | 2 | 4.7u |  |  |  | C2858031 | Capacitor_SMD:C_0402_1005Metric | https://www.lcsc.com/product-detail/C2858031.html | Murata
C6,C7 | 2 | 15pF |  |  |  | C2169087 | Capacitor_SMD:C_0402_1005Metric | https://www.lcsc.com/product-detail/C2169087.html | Murata
D1 | 1 | LED |  |  |  | C7466700 | LED_SMD:LED_0402_1005Metric | https://www.lcsc.com/product-detail/C7466700.html | Broadcom
D2,D3,D4,D5,D6,D7,D8,D9,D10,D11,D12,D13 | 12 | TVS |  |  |  | C2939949 | Custom_VoxLink_Footprints:WLL-2-3 | https://www.lcsc.com/product-detail/C2939949.html | Infineon
R1,R2,R5,R6 | 4 | 4k7 |  |  |  | C482193 | Resistor_SMD:R_0402_1005Metric | https://www.lcsc.com/product-detail/C482193.html | Vishay
R3,R4,R8 | 3 | 10k |  |  |  | C71617 | Resistor_SMD:R_0402_1005Metric | https://www.lcsc.com/product-detail/C71617.html | Vishay
R7 | 1 | 510R |  |  |  | C482201 | Resistor_SMD:R_0402_1005Metric | https://www.lcsc.com/product-detail/C482201.html | Vishay
R9 | 1 | 22R |  |  |  | C482106 | Resistor_SMD:R_0402_1005Metric | https://www.lcsc.com/product-detail/C482106.html | Vishay
U1 | 1 | BNO086 |  |  |  | C5264422 | Package_LGA:LGA-28_5.2x3.8mm_P0.5mm | https://eu.mouser.com/ProductDetail/CEVA/BNO086?qs=ulEaXIWI0c%2FqTo1scjodAw%3D%3D | CEVA
U2 | 1 | TPS7A20L_3V3 |  |  |  | C22445532 | Package_SON:Texas_X2SON-4_1x1mm_P0.65mm | https://www.mouser.sk/ProductDetail/Texas-Instruments/TPS7A20L33PDQNR?qs=dbcCsuKDzFXsu6ygYTlhWw%3D%3D | TI
Y1 | 1 | 32.768 kHz |  |  |  | C5154201 | Crystal:Crystal_SMD_MicroCrystal_CM9V-T1A-2Pin_1.6x1.0mm | https://www.lcsc.com/product-detail/C5154201.html | Epson

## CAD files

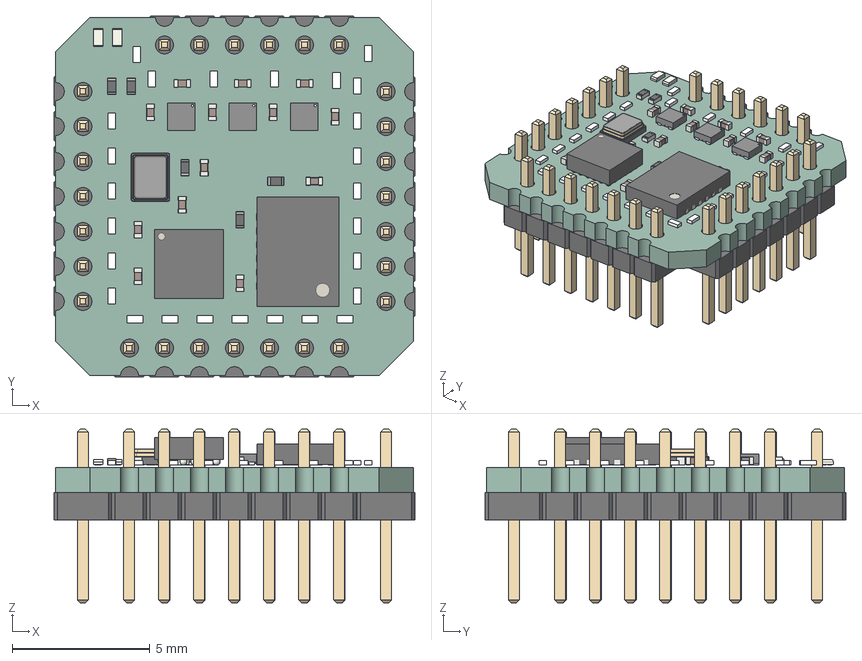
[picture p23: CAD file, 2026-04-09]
Hardware/Core_Module/core_module.step
13.1 x 13.1 x 6.30 mm
C_0201_0603Metric x 13
temp_import.STEP x 26
TPS7A20L33PDQNR x 3
PinHeader_1x07_P1.27mm_Vertical x 3
R_0201_0603Metric x 5
DFN-12-1EP_3x4mm_P0.5mm_EP1.7x3.3mm
PinHeader_1x06_P1.27mm_Vertical
LED_0201_0603Metric x 2
Crystal_SMD_2520-4Pin_2.5x2.0mm
UCBGA-36_2.5x2.5mm_Layout6x6_P0.4mm
Core_Module_PCB

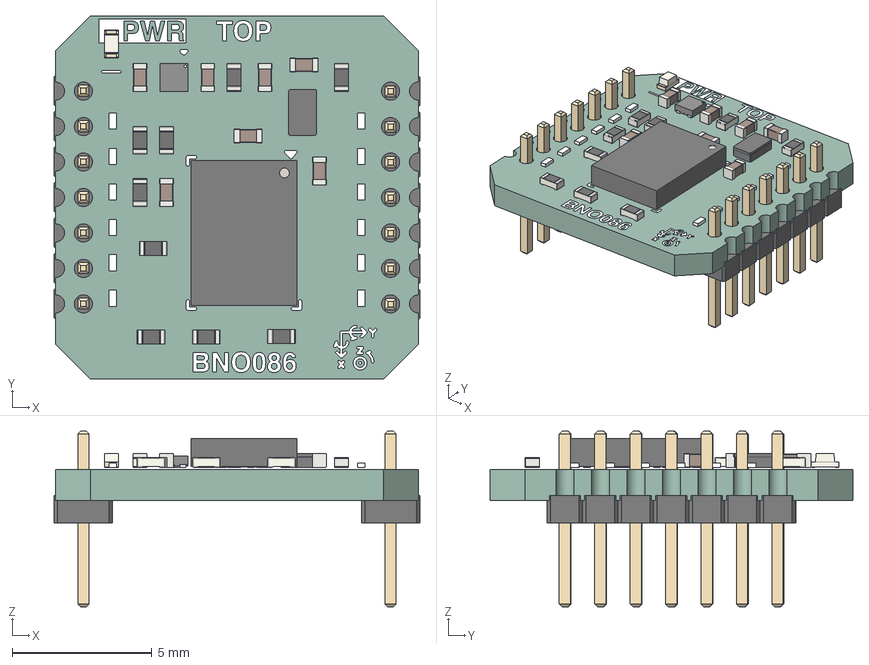
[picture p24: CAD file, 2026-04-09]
Hardware/Sensor_Module/sensor_board.step
13.1 x 13.0 x 6.30 mm
C_0402_1005Metric x 7
R_0402_1005Metric x 9
TPS7A20L33PDQNR
PinHeader_1x07_P1.27mm_Vertical x 2
temp_import.STEP x 12
Crystal_SMD_MicroCrystal_CM9V-T1A-2Pin_1.6x1.0mm
LGA-28_5.2x3.8mm_P0.5mm
LED_0402_1005Metric
Sensor_Module_silkscreen
Sensor_Module_PCB

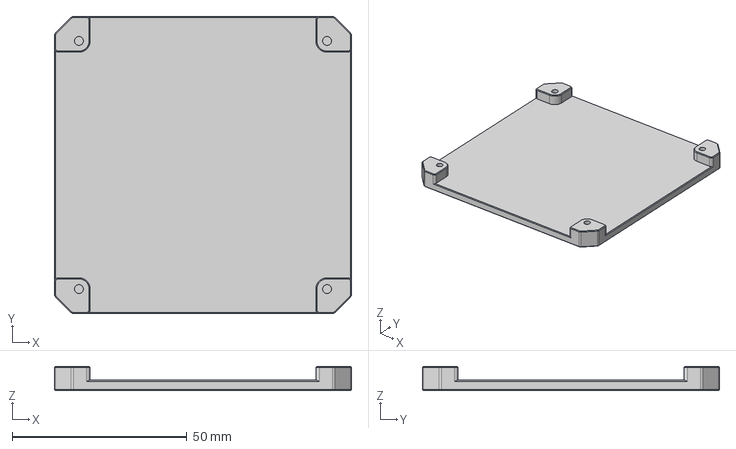
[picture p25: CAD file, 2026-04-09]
Mechanical/Bottom_Tray.step
85.0 x 85.0 x 7.00 mm

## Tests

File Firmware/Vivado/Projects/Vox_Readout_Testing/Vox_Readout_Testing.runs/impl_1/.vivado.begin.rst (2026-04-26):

<?xml version="1.0"?>
<ProcessHandle Version="1" Minor="0">
    <Process Command="vivado.bat" Owner="varsa" Host="LAPTOP-GK6ER3TV" Pid="5716" HostCore="22" HostMemory="033736019968">
    </Process>
</ProcessHandle>
<?xml version="1.0"?>
<ProcessHandle Version="1" Minor="0">
    <Process Command="vivado.bat" Owner="varsa" Host="LAPTOP-GK6ER3TV" Pid="7548" HostCore="22" HostMemory="033736019968">
    </Process>
</ProcessHandle>
<?xml version="1.0"?>
<ProcessHandle Version="1" Minor="0">
    <Process Command="vivado.bat" Owner="varsa" Host="LAPTOP-GK6ER3TV" Pid="24360" HostCore="22" HostMemory="033736019968">
    </Process>
</ProcessHandle>
<?xml version="1.0"?>
<ProcessHandle Version="1" Minor="0">
    <Process Command="vivado.bat" Owner="varsa" Host="LAPTOP-GK6ER3TV" Pid="27952" HostCore="22" HostMemory="033736019968">
    </Process>
</ProcessHandle>
<?xml version="1.0"?>
<ProcessHandle Version="1" Minor="0">
    <Process Command="vivado.bat" Owner="varsa" Host="LAPTOP-GK6ER3TV" Pid="33636" HostCore="22" HostMemory="033736019968">
    </Process>
</ProcessHandle>
<?xml version="1.0"?>
<ProcessHandle Version="1" Minor="0">
    <Process Command="vivado.bat" Owner="varsa" Host="LAPTOP-GK6ER3TV" Pid="1180" HostCore="22" HostMemory="033736019968">
    </Process>
</ProcessHandle>
<?xml version="1.0"?>
<ProcessHandle Version="1" Minor="0">
    <Process Command="vivado.bat" Owner="varsa" Host="LAPTOP-GK6ER3TV" Pid="9696" HostCore="22" HostMemory="033736019968">
    </Process>
</ProcessHandle>
<?xml version="1.0"?>
<ProcessHandle Version="1" Minor="0">
    <Process Command="vivado.bat" Owner="varsa" Host="LAPTOP-GK6ER3TV" Pid="22056" HostCore="22" HostMemory="033736019968">
    </Process>
</ProcessHandle>
<?xml version="1.0"?>
<ProcessHandle Version="1" Minor="0">
    <Process Command="vivado.bat" Owner="varsa" Host="LAPTOP-GK6ER3TV" Pid="19860" HostCore="22" HostMemory="033736019968">
    </Process>
</ProcessHandle>
<?xml version="1.0"?>
<ProcessHandle Version="1" Minor="0">
    <Process Command="vivado.bat" Owner="varsa" Host="LAPTOP-GK6ER3TV" Pid="17724" HostCore="22" HostMemory="033736019968">
    </Process>
</ProcessHandle>
<?xml version="1.0"?>
<ProcessHandle Version="1" Minor="0">
    <Process Command="vivado.bat" Owner="varsa" Host="LAPTOP-GK6ER3TV" Pid="34100" HostCore="22" HostMemory="033736019968">
    </Process>
</ProcessHandle>
<?xml version="1.0"?>
<ProcessHandle Version="1" Minor="0">
    <Process Command="vivado.bat" Owner="varsa" Host="LAPTOP-GK6ER3TV" Pid="25808" HostCore="22" HostMemory="033736019968">
    </Process>
</ProcessHandle>
<?xml version="1.0"?>
<ProcessHandle Version="1" Minor="0">
    <Process Command="vivado.bat" Owner="varsa" Host="LAPTOP-GK6ER3TV" Pid="21324" HostCore="22" HostMemory="033736019968">
    </Process>
</ProcessHandle>
<?xml version="1.0"?>
<ProcessHandle Version="1" Minor="0">
    <Process Command="vivado.bat" Owner="varsa" Host="LAPTOP-GK6ER3TV" Pid="15060" HostCore="22" HostMemory="033736019968">
    </Process>
</ProcessHandle>
<?xml version="1.0"?>
<ProcessHandle Version="1" Minor="0">
    <Process Command="vivado.bat" Owner="varsa" Host="LAPTOP-GK6ER3TV" Pid="27568" HostCore="22" HostMemory="033736019968">
    </Process>
</ProcessHandle>

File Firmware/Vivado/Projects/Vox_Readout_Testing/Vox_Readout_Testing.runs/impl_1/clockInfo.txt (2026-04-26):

-------------------------------------
| Tool Version : Vivado v.2024.1
| Date         : Wed Apr 22 19:37:58 2026
| Host         : LAPTOP-GK6ER3TV
| Design       : design_1
| Device       : xc7a15t-cpg236-1--
-------------------------------------

For more information on clockInfo.txt clock routing debug file see https://support.xilinx.com/s/article/000035660?language=en_US

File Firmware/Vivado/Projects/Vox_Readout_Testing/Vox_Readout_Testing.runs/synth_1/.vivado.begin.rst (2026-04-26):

<?xml version="1.0"?>
<ProcessHandle Version="1" Minor="0">
    <Process Command="vivado.bat" Owner="varsa" Host="LAPTOP-GK6ER3TV" Pid="35024" HostCore="22" HostMemory="033736019968">
    </Process>
</ProcessHandle>

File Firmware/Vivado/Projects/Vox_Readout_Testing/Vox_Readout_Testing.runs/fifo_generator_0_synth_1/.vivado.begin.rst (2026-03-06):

<?xml version="1.0"?>
<ProcessHandle Version="1" Minor="0">
    <Process Command="vivado.bat" Owner="varsa" Host="LAPTOP-GK6ER3TV" Pid="3972" HostCore="22" HostMemory="033736019968">
    </Process>
</ProcessHandle>

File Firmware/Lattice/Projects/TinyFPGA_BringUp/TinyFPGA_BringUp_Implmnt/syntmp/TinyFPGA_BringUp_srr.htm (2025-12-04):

#Build: Synplify Pro L-2016.09L+ice40, Build 077R, Dec  2 2016
#install: C:\lscc\iCEcube2.2020.12\synpbase
#OS: Windows 8 6.2
#Hostname: LAPTOP-GK6ER3TV

# Fri Nov 21 17:37:12 2025

#Implementation: TinyFPGA_BringUp_Implmnt

Synopsys HDL Compiler, version comp2016q3p1, Build 141R, built Dec  5 2016
@N: :  | Running in 64-bit mode 
Copyright (C) 1994-2016 Synopsys, Inc. All rights reserved. This Synopsys software and all associated documentation are proprietary to Synopsys, Inc. and may only be used pursuant to the terms and conditions of a written license agreement with Synopsys, Inc. All other use, reproduction, modification, or distribution of the Synopsys software or the associated documentation is strictly prohibited.

Synopsys Verilog Compiler, version comp2016q3p1, Build 141R, built Dec  5 2016
@N: :  | Running in 64-bit mode 
Copyright (C) 1994-2016 Synopsys, Inc. All rights reserved. This Synopsys software and all associated documentation are proprietary to Synopsys, Inc. and may only be used pursuant to the terms and conditions of a written license agreement with Synopsys, Inc. All other use, reproduction, modification, or distribution of the Synopsys software or the associated documentation is strictly prohibited.

@I::"C:\lscc\iCEcube2.2020.12\synpbase\lib\generic\sb_ice40.v" (library work)
@I::"C:\lscc\iCEcube2.2020.12\synpbase\lib\vlog\hypermods.v" (library __hyper__lib__)
@I::"C:\lscc\iCEcube2.2020.12\synpbase\lib\vlog\umr_capim.v" (library snps_haps)
@I::"C:\lscc\iCEcube2.2020.12\synpbase\lib\vlog\scemi_objects.v" (library snps_haps)
@I::"C:\lscc\iCEcube2.2020.12\synpbase\lib\vlog\scemi_pipes.svh" (library snps_haps)
@I::"C:\Users\varsa\Desktop\School\5_semester\BachelorProject\VoxLink\Firmware\Lattice\TinyFPGA_BringUp\sources\Top_TFPGA.v" (library work)
@I::"C:\Users\varsa\Desktop\School\5_semester\BachelorProject\VoxLink\Firmware\Lattice\TinyFPGA_BringUp\sources\TFPGA_LED_Blink.v" (library work)
@I::"C:\Users\varsa\Desktop\School\5_semester\BachelorProject\VoxLink\Firmware\Lattice\TinyFPGA_BringUp\sources\TFPGA_PLL.v" (library work)
Verilog syntax check successful!
File C:\Users\varsa\Desktop\School\5_semester\BachelorProject\VoxLink\Firmware\Lattice\TinyFPGA_BringUp\sources\Top_TFPGA.v changed - recompiling
Selecting top level module MV_ADC_UART
@N:CG364 : TFPGA_LED_Blink.v(22) | Synthesizing module MV_ADC_UART in library work.

@N:CL159 : TFPGA_LED_Blink.v(25) | Input sys_clk is unused.
@N:CL159 : TFPGA_LED_Blink.v(26) | Input sys_rst is unused.

At c_ver Exit (Real Time elapsed 0h:00m:00s; CPU Time elapsed 0h:00m:00s; Memory used current: 70MB peak: 71MB)

Process took 0h:00m:01s realtime, 0h:00m:01s cputime

Process completed successfully.
# Fri Nov 21 17:37:12 2025

###########################################################]
Synopsys Netlist Linker, version comp2016q3p1, Build 141R, built Dec  5 2016
@N: :  | Running in 64-bit mode 
@N:NF107 : TFPGA_LED_Blink.v(22) | Selected library: work cell: MV_ADC_UART view verilog as top level
@N:NF107 : TFPGA_LED_Blink.v(22) | Selected library: work cell: MV_ADC_UART view verilog as top level

At syn_nfilter Exit (Real Time elapsed 0h:00m:00s; CPU Time elapsed 0h:00m:00s; Memory used current: 67MB peak: 68MB)

Process took 0h:00m:01s realtime, 0h:00m:01s cputime

Process completed successfully.
# Fri Nov 21 17:37:12 2025

###########################################################]
@END

At c_hdl Exit (Real Time elapsed 0h:00m:00s; CPU Time elapsed 0h:00m:00s; Memory used current: 4MB peak: 4MB)

Process took 0h:00m:01s realtime, 0h:00m:01s cputime

Process completed successfully.
# Fri Nov 21 17:37:12 2025

###########################################################]
Synopsys Netlist Linker, version comp2016q3p1, Build 141R, built Dec  5 2016
@N: :  | Running in 64-bit mode 
File C:\Users\varsa\Desktop\School\5_semester\BachelorProject\VoxLink\Firmware\Lattice\TinyFPGA_BringUp\TinyFPGA_BringUp_Implmnt\synwork\TinyFPGA_BringUp_comp.srs changed - recompiling
@N:NF107 : TFPGA_LED_Blink.v(22) | Selected library: work cell: MV_ADC_UART view verilog as top level
@N:NF107 : TFPGA_LED_Blink.v(22) | Selected library: work cell: MV_ADC_UART view verilog as top level

At syn_nfilter Exit (Real Time elapsed 0h:00m:00s; CPU Time elapsed 0h:00m:00s; Memory used current: 67MB peak: 68MB)

Process took 0h:00m:01s realtime, 0h:00m:01s cputime

Process completed successfully.
# Fri Nov 21 17:37:13 2025

###########################################################]
Pre-mapping Report

# Fri Nov 21 17:37:13 2025

Synopsys Lattice Technology Pre-mapping, Version maplat, Build 1612R, Built Dec  5 2016 10:31:39
Copyright (C) 1994-2016 Synopsys, Inc. All rights reserved. This Synopsys software and all associated documentation are proprietary to Synopsys, Inc. and may only be used pursuant to the terms and conditions of a written license agreement with Synopsys, Inc. All other use, reproduction, modification, or distribution of the Synopsys software or the associated documentation is strictly prohibited.
Product Version L-2016.09L+ice40

Mapper Startup Complete (Real Time elapsed 0h:00m:00s; CPU Time elapsed 0h:00m:00s; Memory used current: 100MB peak: 100MB)

@A:MF827 :  | No constraint file specified. 
Linked File: TinyFPGA_BringUp_scck.rpt
Printing clock  summary report in "C:\Users\varsa\Desktop\School\5_semester\BachelorProject\VoxLink\Firmware\Lattice\TinyFPGA_BringUp\TinyFPGA_BringUp_Implmnt\TinyFPGA_BringUp_scck.rpt" file 
@N:MF248 :  | Running in 64-bit mode. 
@N:MF666 :  | Clock conversion enabled. (Command "set_option -fix_gated_and_generated_clocks 1" in the project file.) 

Design Input Complete (Real Time elapsed 0h:00m:00s; CPU Time elapsed 0h:00m:00s; Memory used current: 100MB peak: 102MB)

Mapper Initialization Complete (Real Time elapsed 0h:00m:00s; CPU Time elapsed 0h:00m:00s; Memory used current: 100MB peak: 102MB)

Start loading timing files (Real Time elapsed 0h:00m:00s; CPU Time elapsed 0h:00m:00s; Memory used current: 101MB peak: 102MB)

Finished loading timing files (Real Time elapsed 0h:00m:00s; CPU Time elapsed 0h:00m:00s; Memory used current: 101MB peak: 103MB)

ICG Latch Removal Summary:
Number of ICG latches removed:	0
Number of ICG latches not removed:	0
syn_allowed_resources : blockrams=32  set on top level netlist MV_ADC_UART

Finished netlist restructuring (Real Time elapsed 0h:00m:00s; CPU Time elapsed 0h:00m:00s; Memory used current: 132MB peak: 134MB)

Clock Summary
*****************

Start     Requested     Requested     Clock     Clock     Clock
Clock     Frequency     Period        Type      Group     Load 
---------------------------------------------------------------
===============================================================

Finished Pre Mapping Phase.
@N:BN225 :  | Writing default property annotation file C:\Users\varsa\Desktop\School\5_semester\BachelorProject\VoxLink\Firmware\Lattice\TinyFPGA_BringUp\TinyFPGA_BringUp_Implmnt\TinyFPGA_BringUp.sap. 

Starting constraint checker (Real Time elapsed 0h:00m:00s; CPU Time elapsed 0h:00m:00s; Memory used current: 132MB peak: 134MB)

None
None

Finished constraint checker (Real Time elapsed 0h:00m:00s; CPU Time elapsed 0h:00m:00s; Memory used current: 132MB peak: 134MB)

Pre-mapping successful!

At Mapper Exit (Real Time elapsed 0h:00m:00s; CPU Time elapsed 0h:00m:00s; Memory used current: 47MB peak: 134MB)

Process took 0h:00m:01s realtime, 0h:00m:01s cputime
# Fri Nov 21 17:37:13 2025

###########################################################]
Map & Optimize Report

# Fri Nov 21 17:37:14 2025

Synopsys Lattice Technology Mapper, Version maplat, Build 1612R, Built Dec  5 2016 10:31:39
Copyright (C) 1994-2016 Synopsys, Inc. All rights reserved. This Synopsys software and all associated documentation are proprietary to Synopsys, Inc. and may only be used pursuant to the terms and conditions of a written license agreement with Synopsys, Inc. All other use, reproduction, modification, or distribution of the Synopsys software or the associated documentation is strictly prohibited.
Product Version L-2016.09L+ice40

Mapper Startup Complete (Real Time elapsed 0h:00m:00s; CPU Time elapsed 0h:00m:00s; Memory used current: 100MB peak: 100MB)

@N:MF248 :  | Running in 64-bit mode. 
@N:MF666 :  | Clock conversion enabled. (Command "set_option -fix_gated_and_generated_clocks 1" in the project file.) 

Design Input Complete (Real Time elapsed 0h:00m:00s; CPU Time elapsed 0h:00m:00s; Memory used current: 99MB peak: 101MB)

Mapper Initialization Complete (Real Time elapsed 0h:00m:00s; CPU Time elapsed 0h:00m:00s; Memory used current: 99MB peak: 101MB)

Start loading timing files (Real Time elapsed 0h:00m:00s; CPU Time elapsed 0h:00m:00s; Memory used current: 101MB peak: 101MB)

Finished loading timing files (Real Time elapsed 0h:00m:00s; CPU Time elapsed 0h:00m:00s; Memory used current: 101MB peak: 103MB)

Starting Optimization and Mapping (Real Time elapsed 0h:00m:00s; CPU Time elapsed 0h:00m:00s; Memory used current: 132MB peak: 134MB)

Available hyper_sources - for debug and ip models
	None Found

@N:MT206 :  | Auto Constrain mode is enabled 

Finished RTL optimizations (Real Time elapsed 0h:00m:00s; CPU Time elapsed 0h:00m:00s; Memory used current: 132MB peak: 134MB)

Starting factoring (Real Time elapsed 0h:00m:00s; CPU Time elapsed 0h:00m:00s; Memory used current: 132MB peak: 134MB)

Finished factoring (Real Time elapsed 0h:00m:00s; CPU Time elapsed 0h:00m:00s; Memory used current: 132MB peak: 134MB)

Finished gated-clock and generated-clock conversion (Real Time elapsed 0h:00m:00s; CPU Time elapsed 0h:00m:00s; Memory used current: 132MB peak: 134MB)

Finished generic timing optimizations - Pass 1 (Real Time elapsed 0h:00m:00s; CPU Time elapsed 0h:00m:00s; Memory used current: 132MB peak: 134MB)

Starting Early Timing Optimization (Real Time elapsed 0h:00m:00s; CPU Time elapsed 0h:00m:00s; Memory used current: 132MB peak: 134MB)

Finished Early Timing Optimization (Real Time elapsed 0h:00m:00s; CPU Time elapsed 0h:00m:00s; Memory used current: 132MB peak: 134MB)

Finished generic timing optimizations - Pass 2 (Real Time elapsed 0h:00m:00s; CPU Time elapsed 0h:00m:00s; Memory used current: 132MB peak: 134MB)

Finished preparing to map (Real Time elapsed 0h:00m:00s; CPU Time elapsed 0h:00m:00s; Memory used current: 132MB peak: 134MB)

Finished technology mapping (Real Time elapsed 0h:00m:00s; CPU Time elapsed 0h:00m:00s; Memory used current: 132MB peak: 134MB)

Pass		 CPU time		Worst Slack		Luts / Registers
------------------------------------------------------------

Finished technology timing optimizations and critical path resynthesis (Real Time elapsed 0h:00m:00s; CPU Time elapsed 0h:00m:00s; Memory used current: 132MB peak: 134MB)

Finished restoring hierarchy (Real Time elapsed 0h:00m:00s; CPU Time elapsed 0h:00m:00s; Memory used current: 132MB peak: 134MB)

@S |Clock Optimization Summary

#### START OF CLOCK OPTIMIZATION REPORT #####[

0 non-gated/non-generated clock tree(s) driving 0 clock pin(s) of sequential element(s)
0 gated/generated clock tree(s) driving 0 clock pin(s) of sequential element(s)
0 instances converted, 0 sequential instances remain driven by gated/generated clocks

##### END OF CLOCK OPTIMIZATION REPORT ######]

Start Writing Netlists (Real Time elapsed 0h:00m:00s; CPU Time elapsed 0h:00m:00s; Memory used current: 106MB peak: 134MB)

Writing Analyst data base C:\Users\varsa\Desktop\School\5_semester\BachelorProject\VoxLink\Firmware\Lattice\TinyFPGA_BringUp\TinyFPGA_BringUp_Implmnt\synwork\TinyFPGA_BringUp_m.srm

Finished Writing Netlist Databases (Real Time elapsed 0h:00m:00s; CPU Time elapsed 0h:00m:00s; Memory used current: 131MB peak: 134MB)

Writing EDIF Netlist and constraint files
@N:BW103 :  | The default time unit for the Synopsys Constraint File (SDC or FDC) is 1ns. 
@N:BW107 :  | Synopsys Constraint File capacitance units using default value of 1pF  
@N:FX1056 :  | Writing EDF file: C:\Users\varsa\Desktop\School\5_semester\BachelorProject\VoxLink\Firmware\Lattice\TinyFPGA_BringUp\TinyFPGA_BringUp_Implmnt\TinyFPGA_BringUp.edf 
L-2016.09L+ice40

Finished Writing EDIF Netlist and constraint files (Real Time elapsed 0h:00m:00s; CPU Time elapsed 0h:00m:00s; Memory used current: 132MB peak: 134MB)

Start final timing analysis (Real Time elapsed 0h:00m:00s; CPU Time elapsed 0h:00m:00s; Memory used current: 132MB peak: 134MB)

##### START OF TIMING REPORT #####[
# Timing Report written on Fri Nov 21 17:37:14 2025
#

Top view:               MV_ADC_UART
Requested Frequency:    1.0 MHz
Wire load mode:         top
Paths requested:        5
Constraint File(s):    
@N:MT320 :  | This timing report is an estimate of place and route data. For final timing results, use the FPGA vendor place and route report. 

@N:MT322 :  | Clock constraints include only register-to-register paths associated with each individual clock. 

Performance Summary
*******************

Worst slack in design: NA

Clock Relationships
*******************

Clocks            |    rise  to  rise   |    fall  to  fall   |    rise  to  fall   |    fall  to  rise 
--------------------------------------------------------------------------------------------------------
Starting  Ending  |  constraint  slack  |  constraint  slack  |  constraint  slack  |  constraint  slack
--------------------------------------------------------------------------------------------------------
========================================================================================================
 Note: 'No paths' indicates there are no paths in the design for that pair of clock edges.
       'Diff grp' indicates that paths exist but the starting clock and ending clock are in different clock groups.

Interface Information 
*********************

No IO constraint found

##### END OF TIMING REPORT #####]

Timing exceptions that could not be applied
None

Finished final timing analysis (Real Time elapsed 0h:00m:00s; CPU Time elapsed 0h:00m:00s; Memory used current: 132MB peak: 134MB)

Finished timing report (Real Time elapsed 0h:00m:00s; CPU Time elapsed 0h:00m:00s; Memory used current: 132MB peak: 134MB)

---------------------------------------
Resource Usage Report for MV_ADC_UART 

Mapping to part: ice40lp8kcm81
I/O Register bits:                  0
Register bits not including I/Os:   0 (0%)
Total load per clock:

@S |Mapping Summary:
Total  LUTs: 0 (0%)

Mapper successful!

At Mapper Exit (Real Time elapsed 0h:00m:00s; CPU Time elapsed 0h:00m:00s; Memory used current: 26MB peak: 134MB)

Process took 0h:00m:01s realtime, 0h:00m:01s cputime
# Fri Nov 21 17:37:14 2025

###########################################################]

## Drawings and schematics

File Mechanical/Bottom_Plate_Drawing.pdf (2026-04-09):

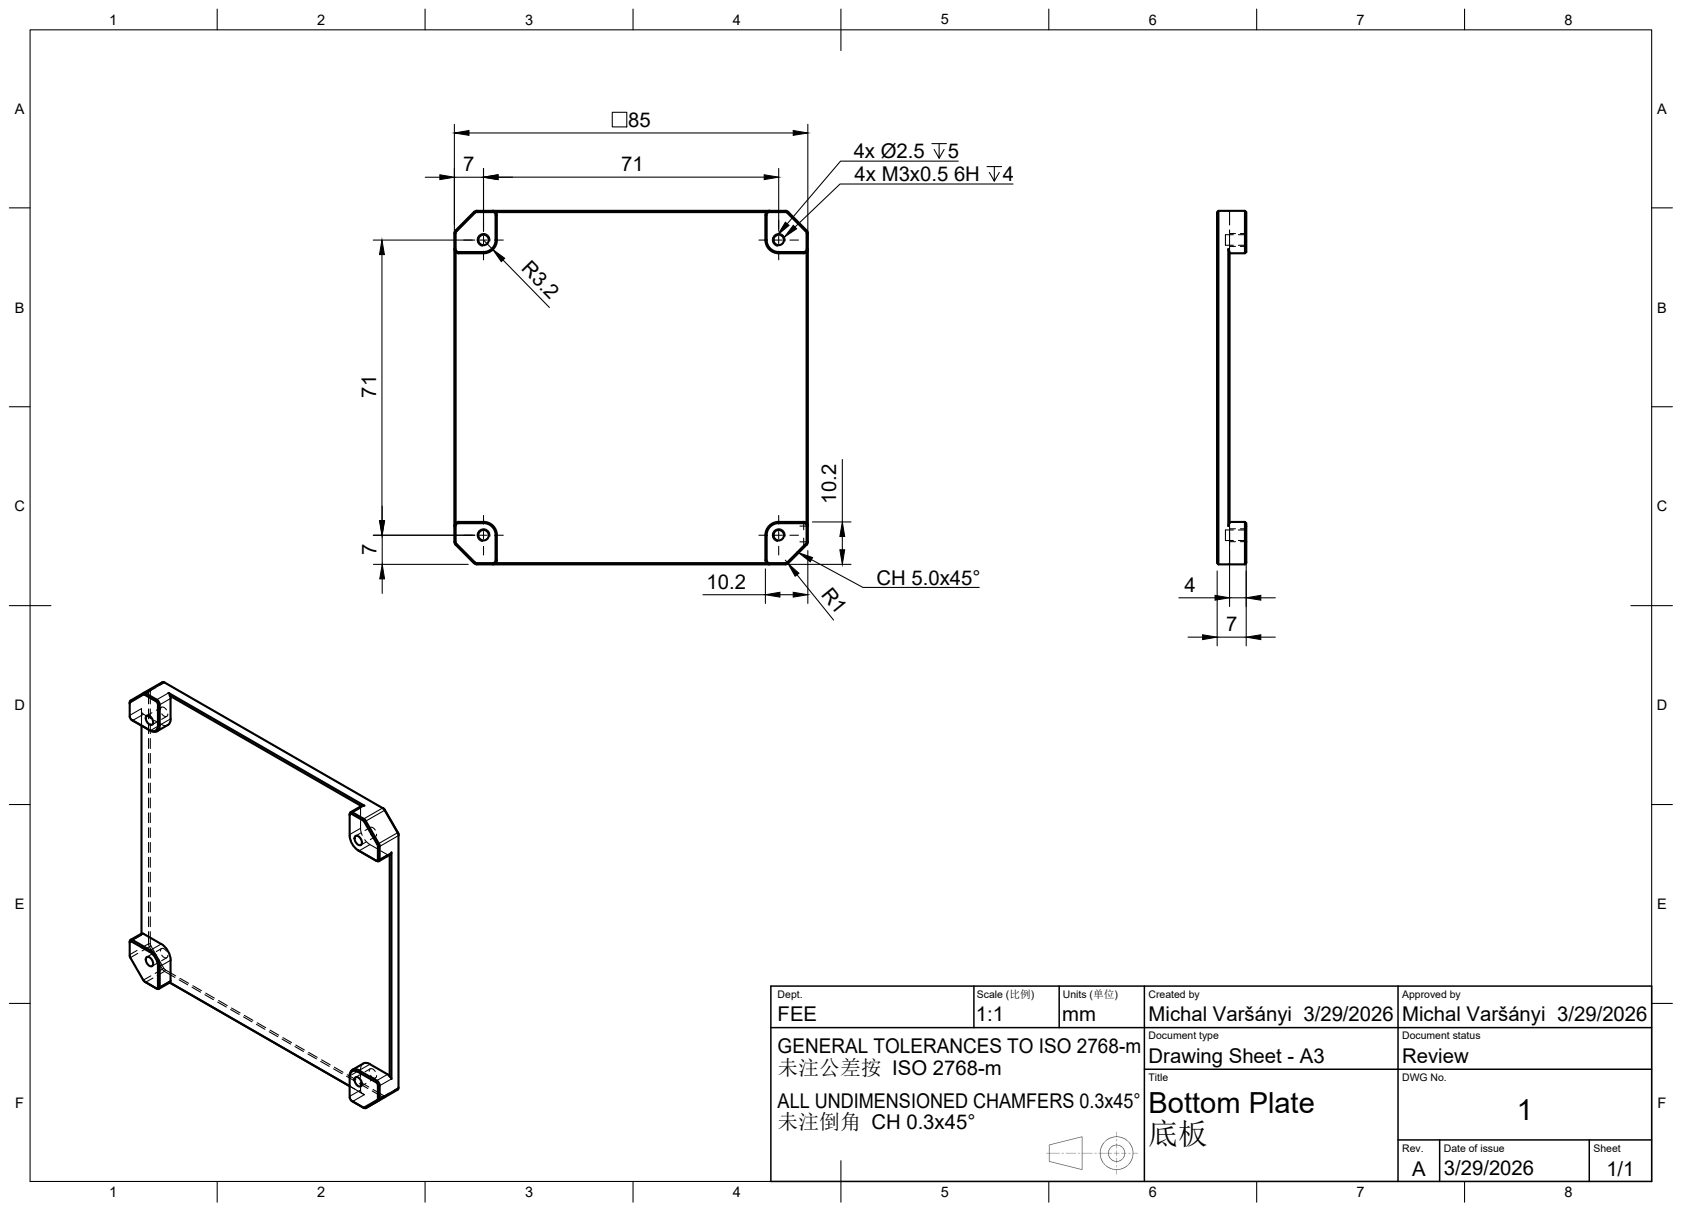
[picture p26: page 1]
Title; DWG No.; Rev.; Date of issue; Sheet; Bottom Plate

Dept. FEE | Scale (比例) | Units (单位) mm | Created by Michal Varšányi 3/29/2026 | Approved by Michal Varšányi 3/29/2026

Document type Drawing Sheet - A3 | Document status Review

GENERAL TOLERANCES TO ISO 2768-m
未注公差按 ISO 2768-m
ALL UNDIMENSIONED CHAMFERS 0.3x45°
未注倒角 CH 0.3x45°

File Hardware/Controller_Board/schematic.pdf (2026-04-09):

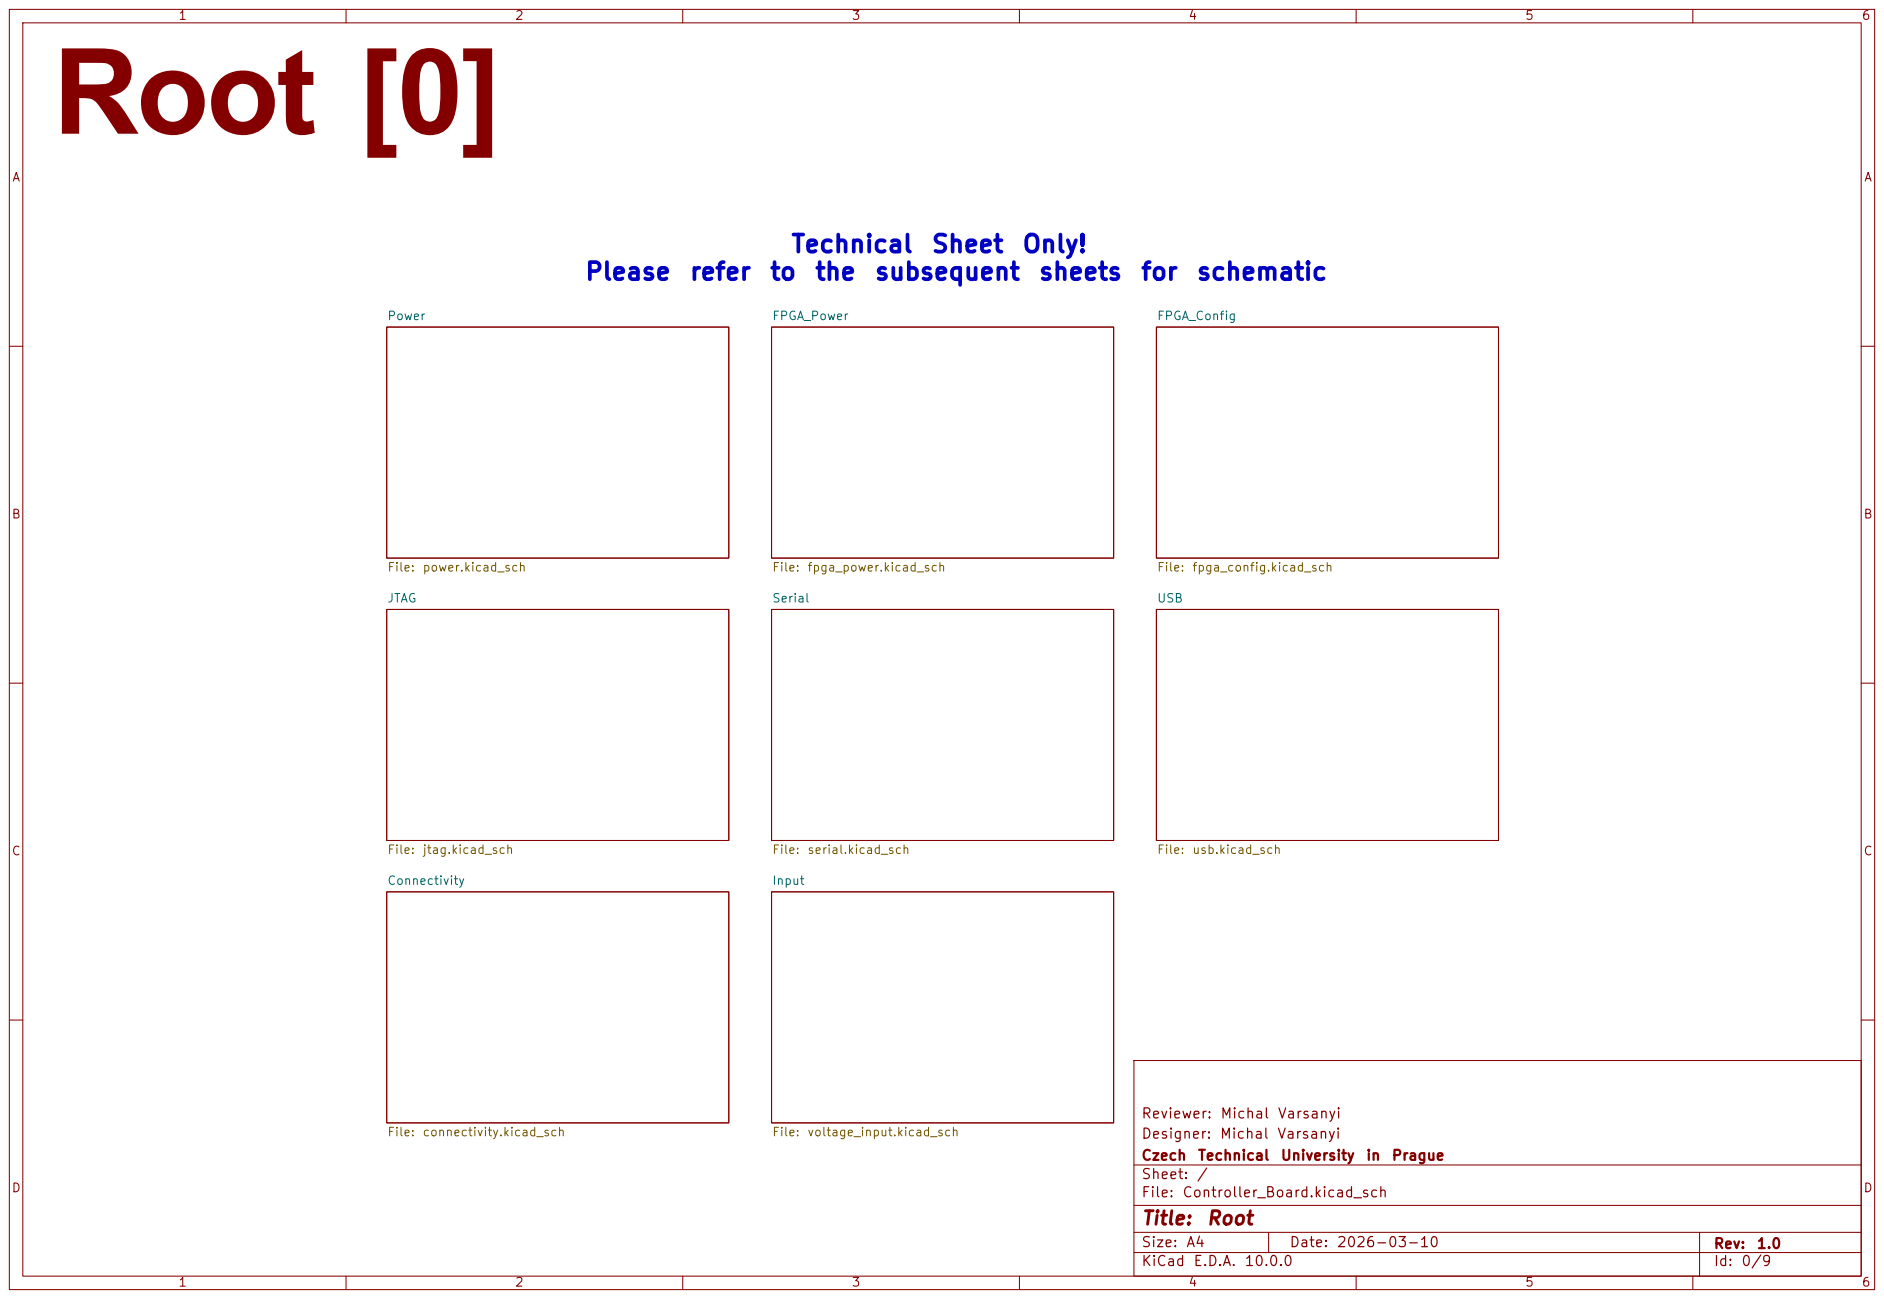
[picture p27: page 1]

File: jtag.kicad_sch Power File: power.kicad_sch

Technical Sheet Only!
FPGA_Power File: fpga_power.kicad_sch Serial File: serial.kicad_sch

Please refer to the subsequent sheets for schematic

Reviewer: Michal Varsanyi
Designer: Michal Varsanyi
Czech Technical University in Prague
Sheet: /
D Date: 2026-03-10 KiCad E.D.A. 10.0.0
File: Controller_Board.kicad_sch
Title: Root

Size: A4 | Rev: 1.0

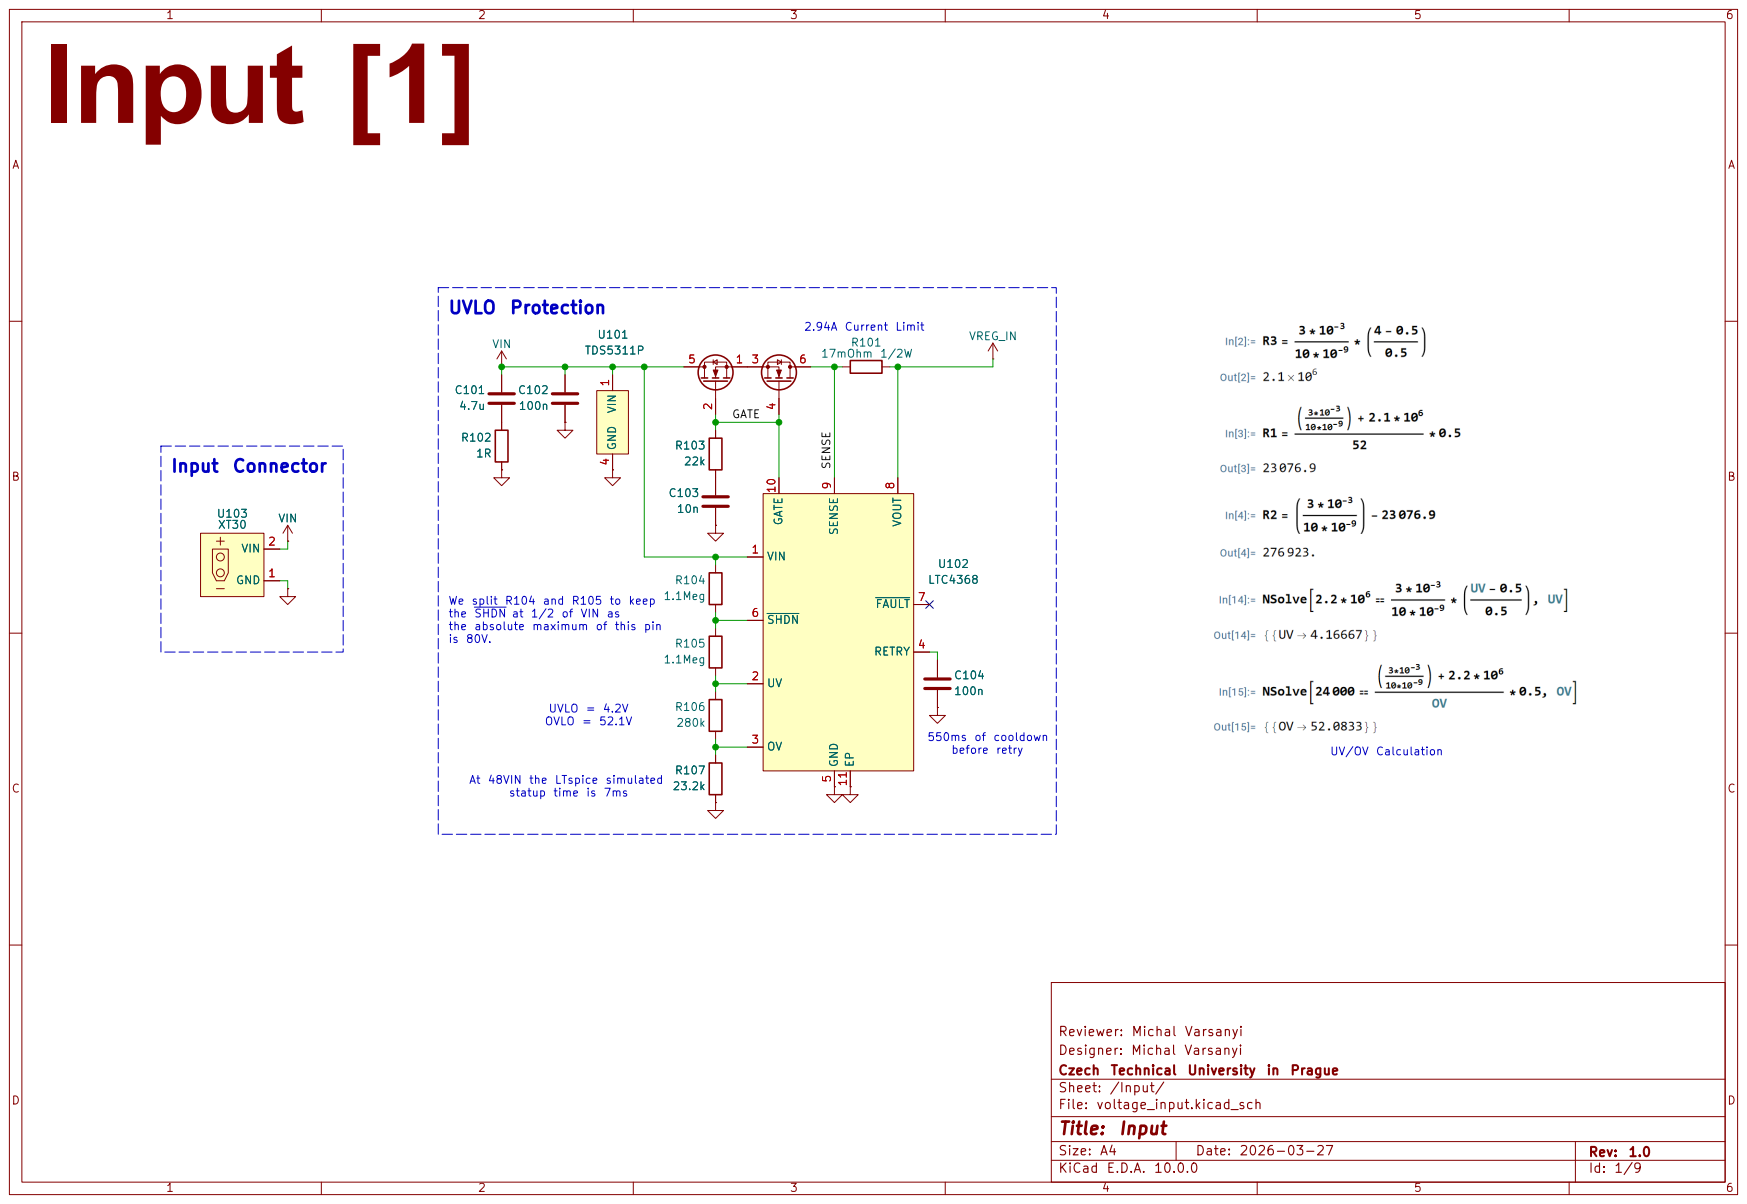
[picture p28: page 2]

statup time is 7ms Input [1]

the SHDN at 1/2 of VIN as
the absolute maximum of this pin
is 80V. At 48VIN the LTspice simulated

Designer: Michal Varsanyi
Czech Technical University in Prague
Sheet: /Input/
D Date: 2026-03-27 KiCad E.D.A. 10.0.0
File: voltage_input.kicad_sch
Title: Input

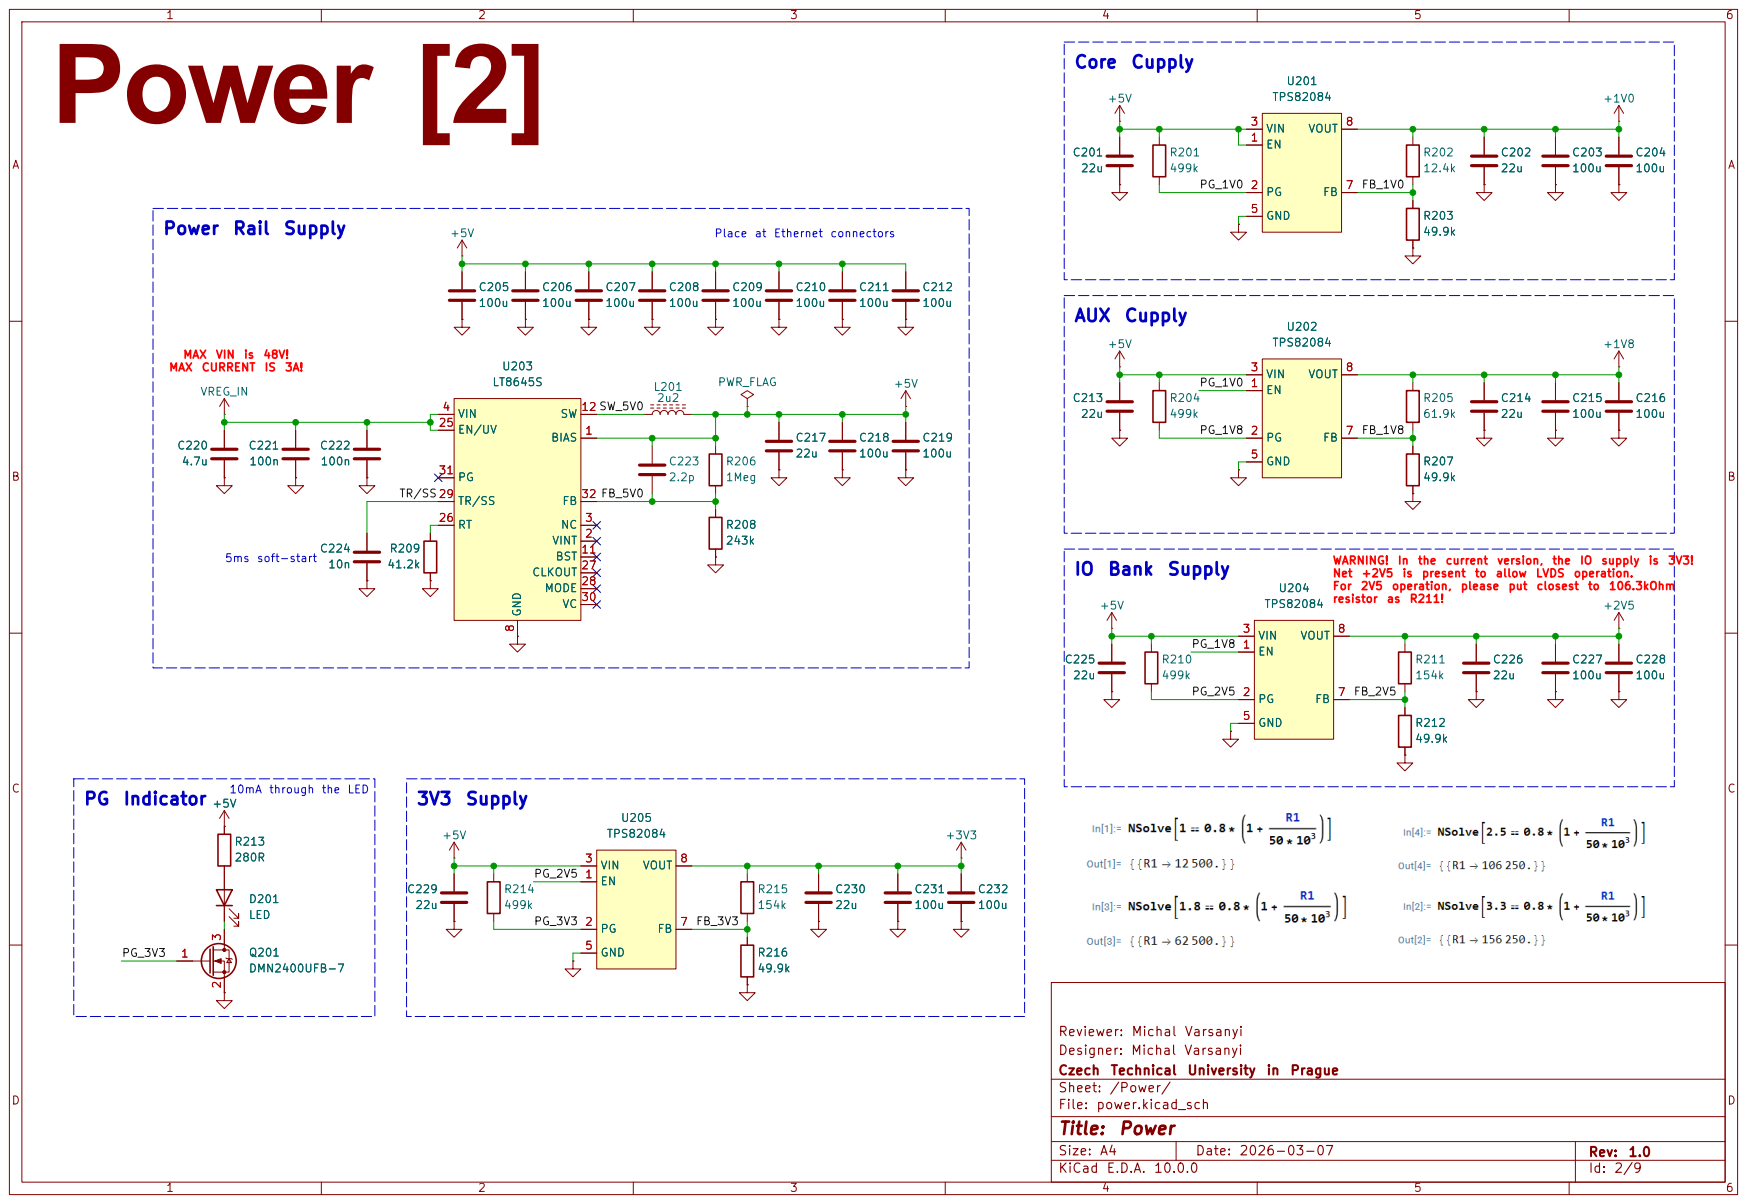
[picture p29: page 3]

Place at Ethernet connectors Power [2]

For 2V5 operation, please put closest to 106.3kOhm

resistor as R211! 10mA through the LED

Reviewer: Michal Varsanyi
Designer: Michal Varsanyi
Czech Technical University in Prague
Sheet: /Power/
D Date: 2026-03-07 KiCad E.D.A. 10.0.0
File: power.kicad_sch
Title: Power

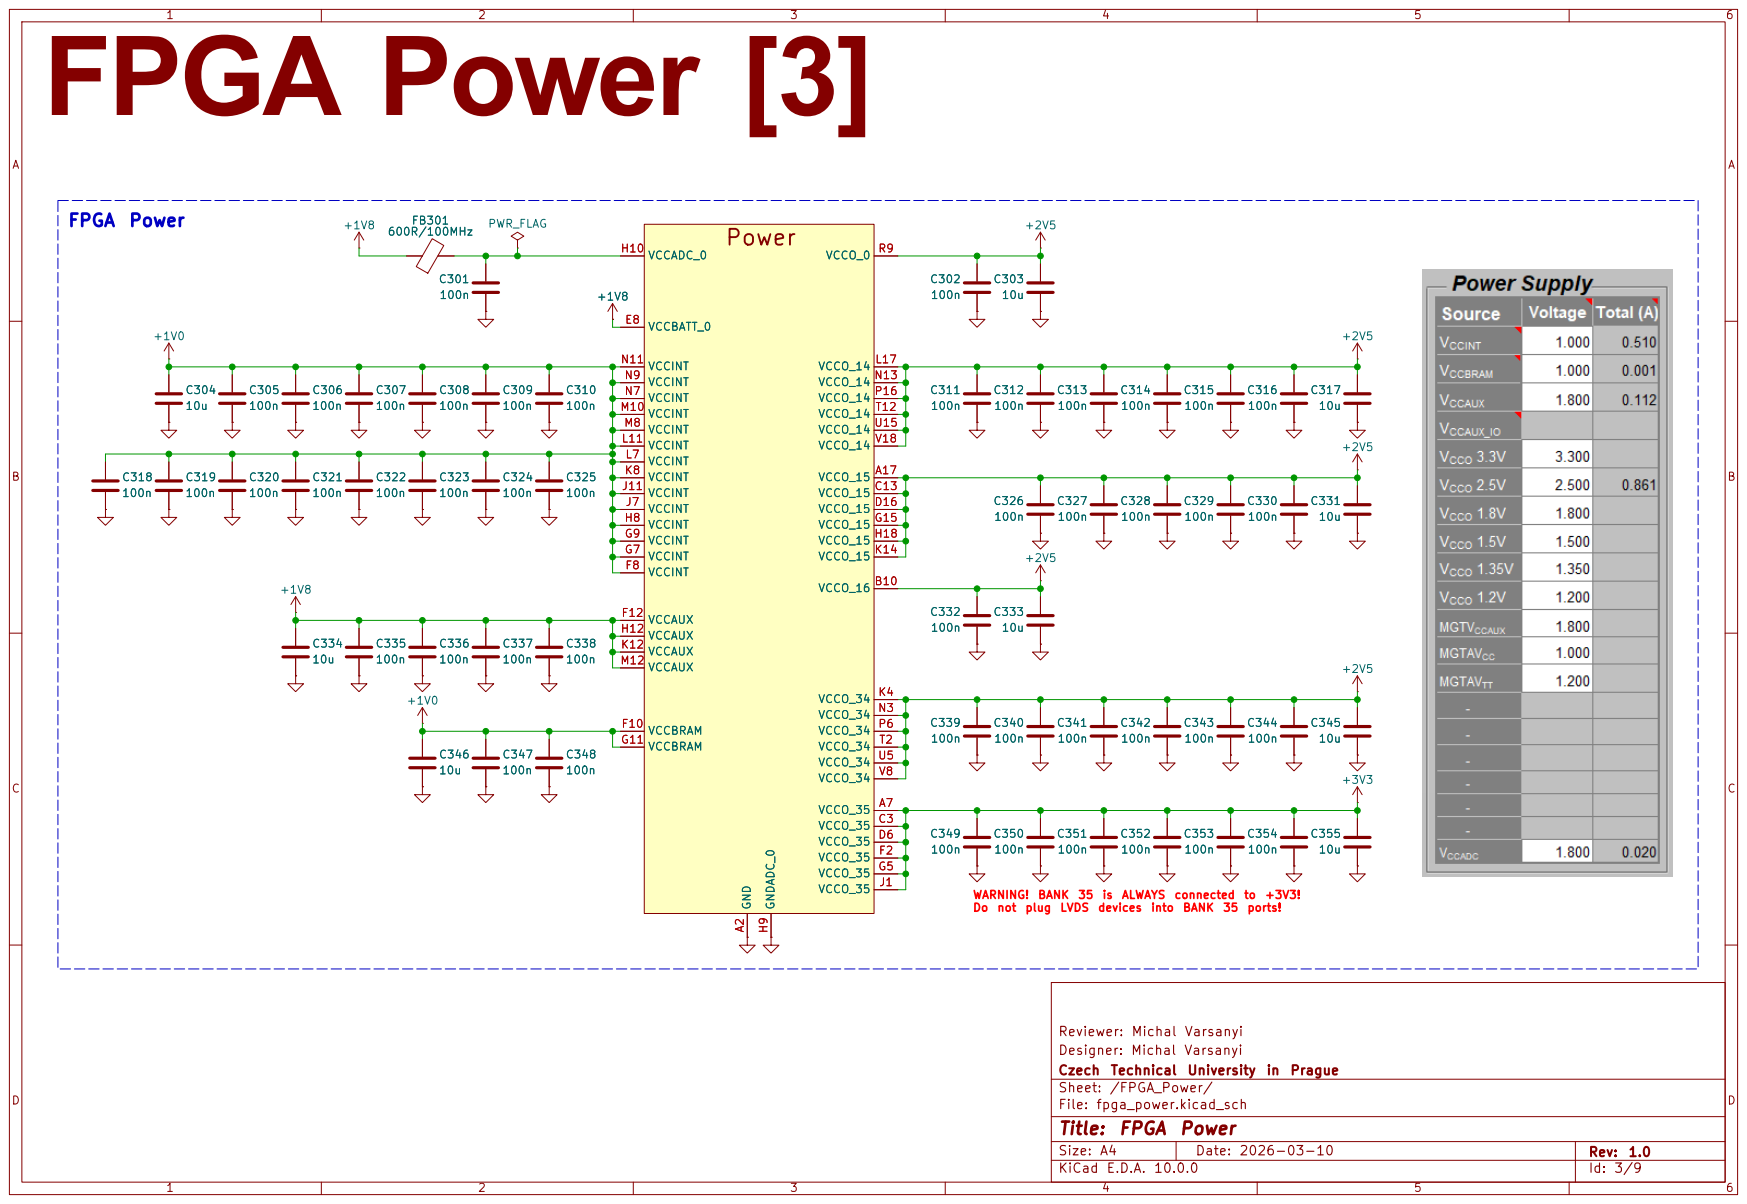
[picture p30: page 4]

WARNING! BANK 35 is ALWAYS connected to +3V3! Do not plug LVDS devices into BANK 35 ports!

Reviewer: Michal Varsanyi
Designer: Michal Varsanyi
Czech Technical University in Prague
Sheet: /FPGA_Power/
D Date: 2026-03-10 KiCad E.D.A. 10.0.0
File: fpga_power.kicad_sch
Title: FPGA Power

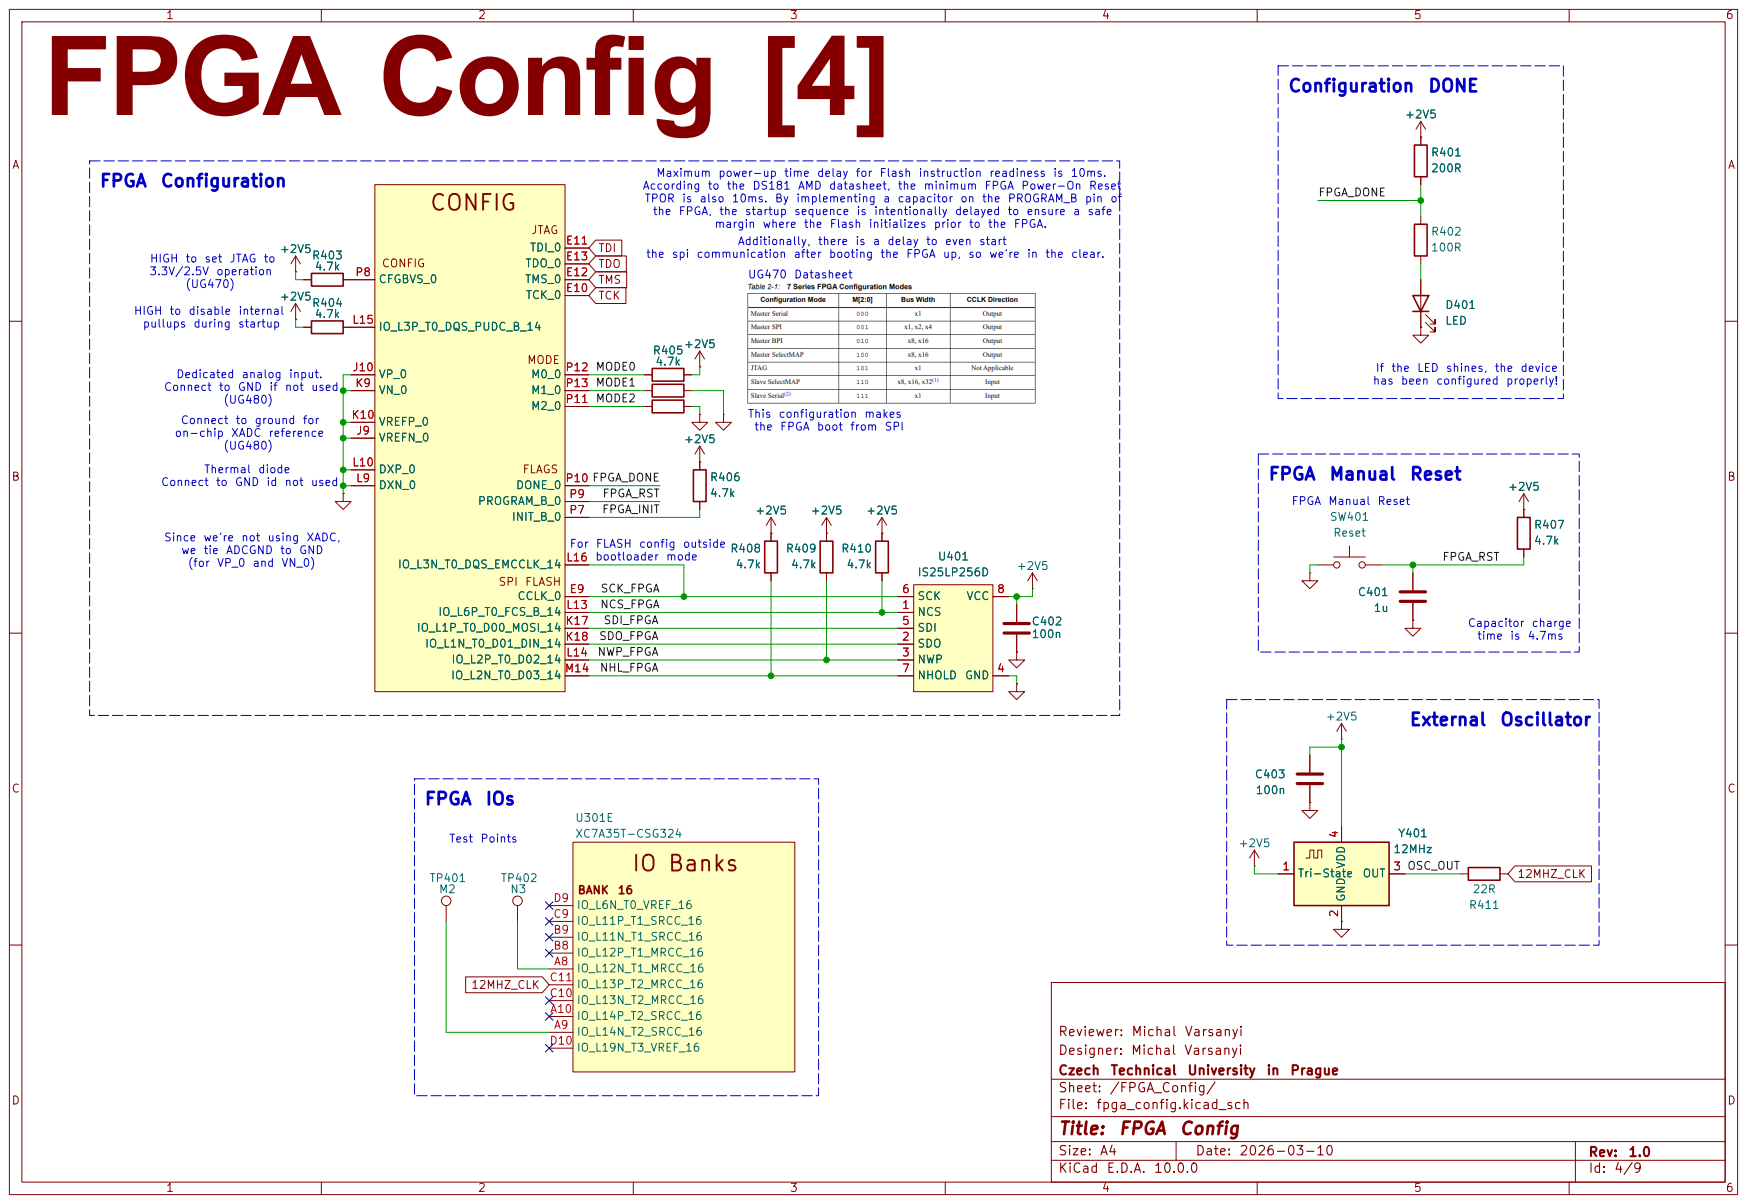
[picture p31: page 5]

the spi communication after booting the FPGA up, so we're in the clear. FPGA Config [4]
TDI 12MHZ_CLK

Maximum power-up time delay for Flash instruction readiness is 10ms. According to the DS181 AMD datasheet, the minimum FPGA Power-On Reset TPOR is also 10ms. By implementing a capacitor on the PROGRAM_B pin of

the FPGA, the startup sequence is intentionally delayed to ensure a safe margin where the Flash initializes prior to the FPGA. UG470 Datasheet

Additionally, there is a delay to even start

HIGH to set JTAG to 3.3V/2.5V operation

HIGH to disable internal
pullups during startup

Dedicated analog input.
Connect to GND if not used

If the LED shines, the device has been configured properly!

Connect to ground for on-chip XADC reference
the FPGA boot from SPI Since we're not using XADC, we tie ADCGND to GND

Thermal diode Connect to GND id not used

For FLASH config outside bootloader mode

Designer: Michal Varsanyi
Czech Technical University in Prague
Sheet: /FPGA_Config/
D Date: 2026-03-10 KiCad E.D.A. 10.0.0
File: fpga_config.kicad_sch
Title: FPGA Config

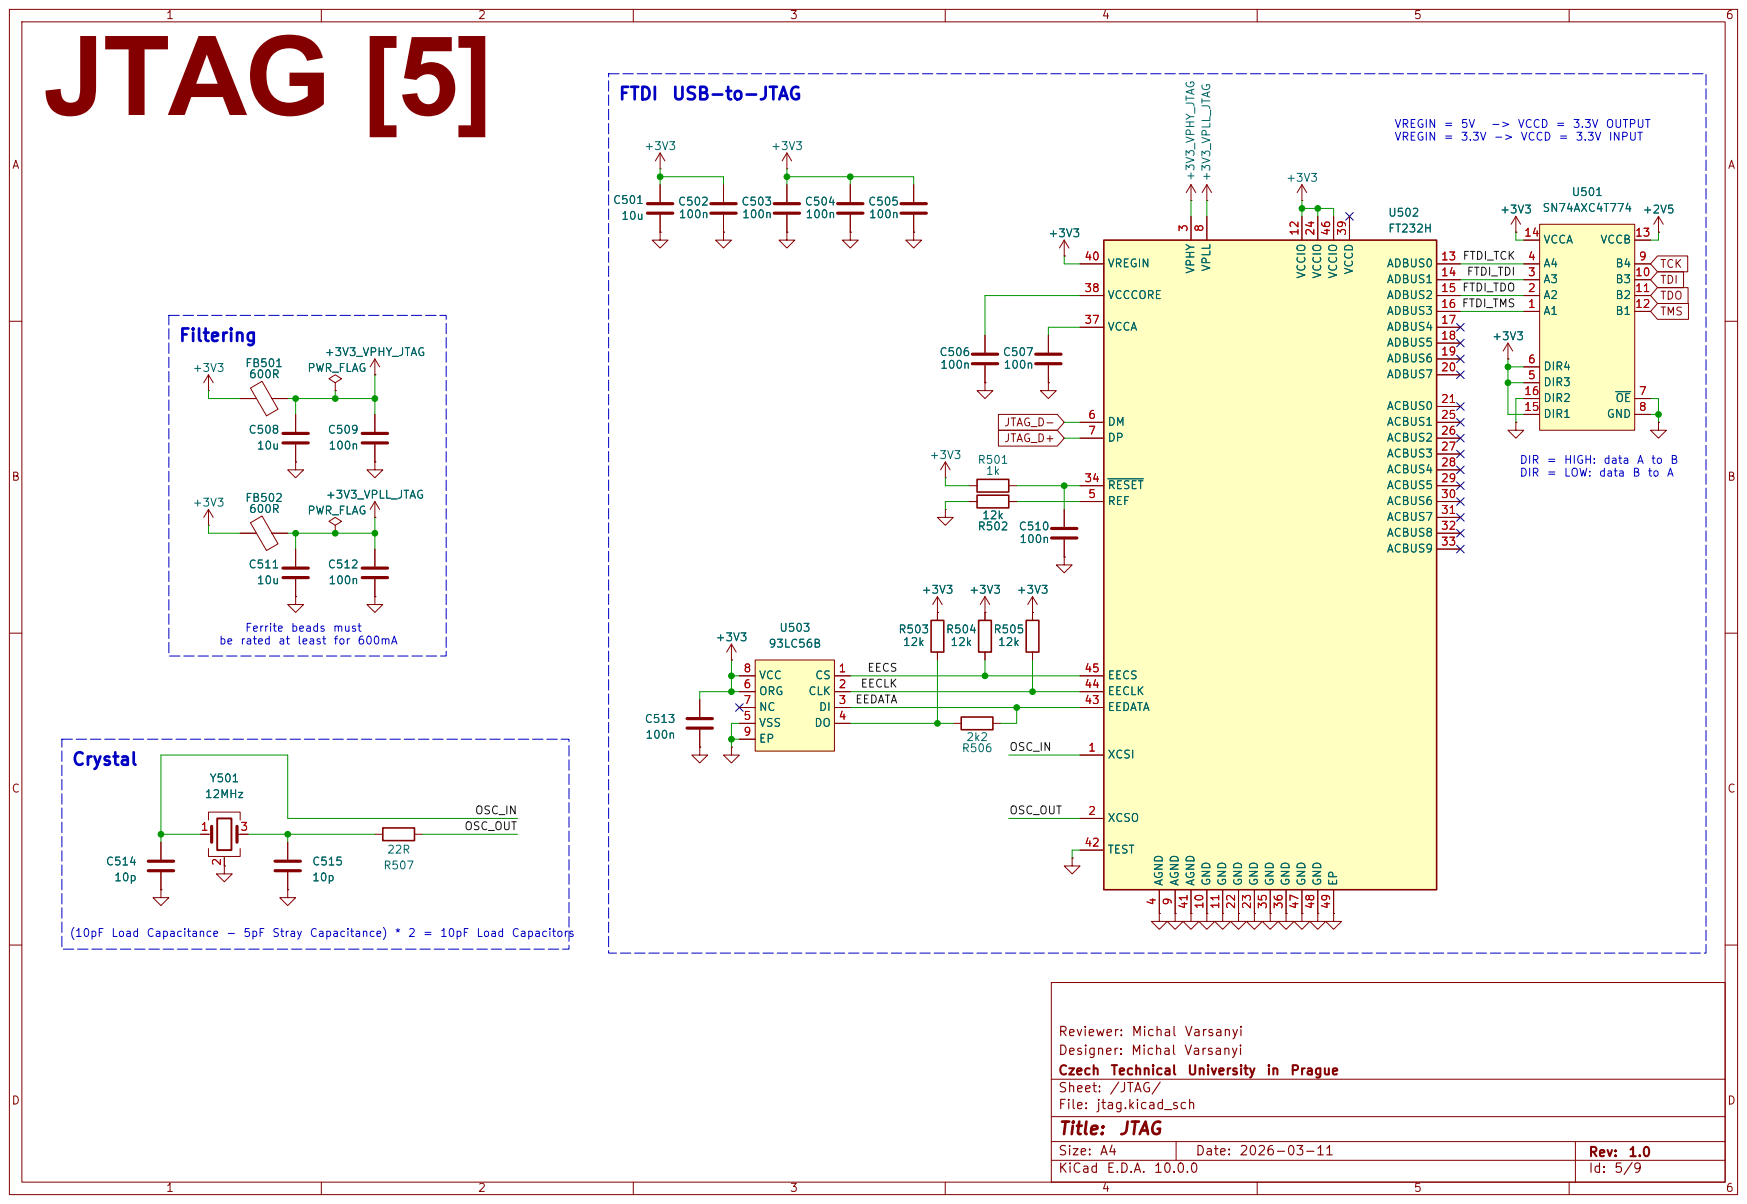
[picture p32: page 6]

DIR = LOW: data B to A JTAG [5]

FTDI USB-to-JTAG

4 REF 5 DM 6 DP 7 VPLL 8 AGND

(10pF Load Capacitance - 5pF Stray Capacitance) * 2 = 10pF Load Capacitors

Designer: Michal Varsanyi
Czech Technical University in Prague
Sheet: /JTAG/
D Date: 2026-03-11 KiCad E.D.A. 10.0.0
File: jtag.kicad_sch
Title: JTAG

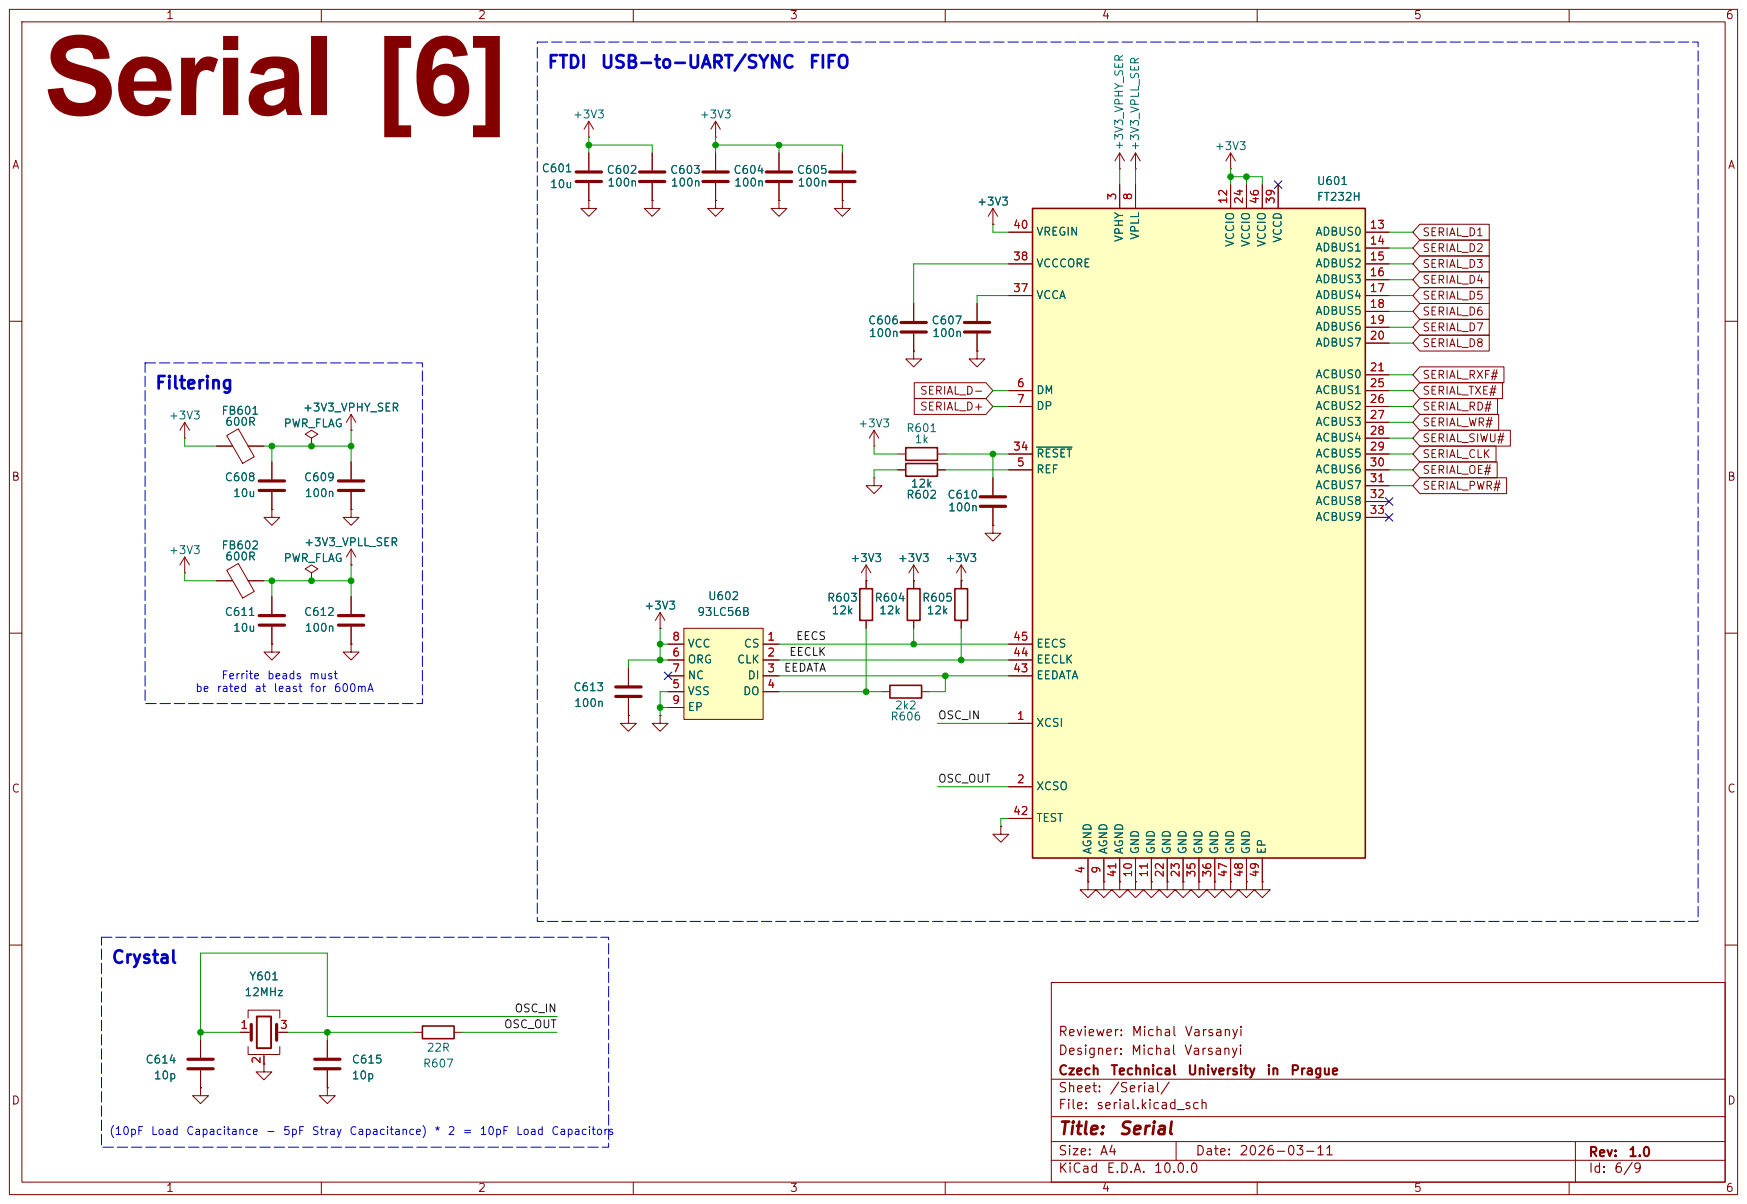
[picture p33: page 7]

FTDI USB-to-UART/SYNC FIFO

4 REF 5 DM 6 DP 7 VPLL 8 AGND

be rated at least for 600mA C608

Designer: Michal Varsanyi
Czech Technical University in Prague
Sheet: /Serial/
D Date: 2026-03-11 KiCad E.D.A. 10.0.0
File: serial.kicad_sch
Title: Serial

(10pF Load Capacitance - 5pF Stray Capacitance) * 2 = 10pF Load Capacitors

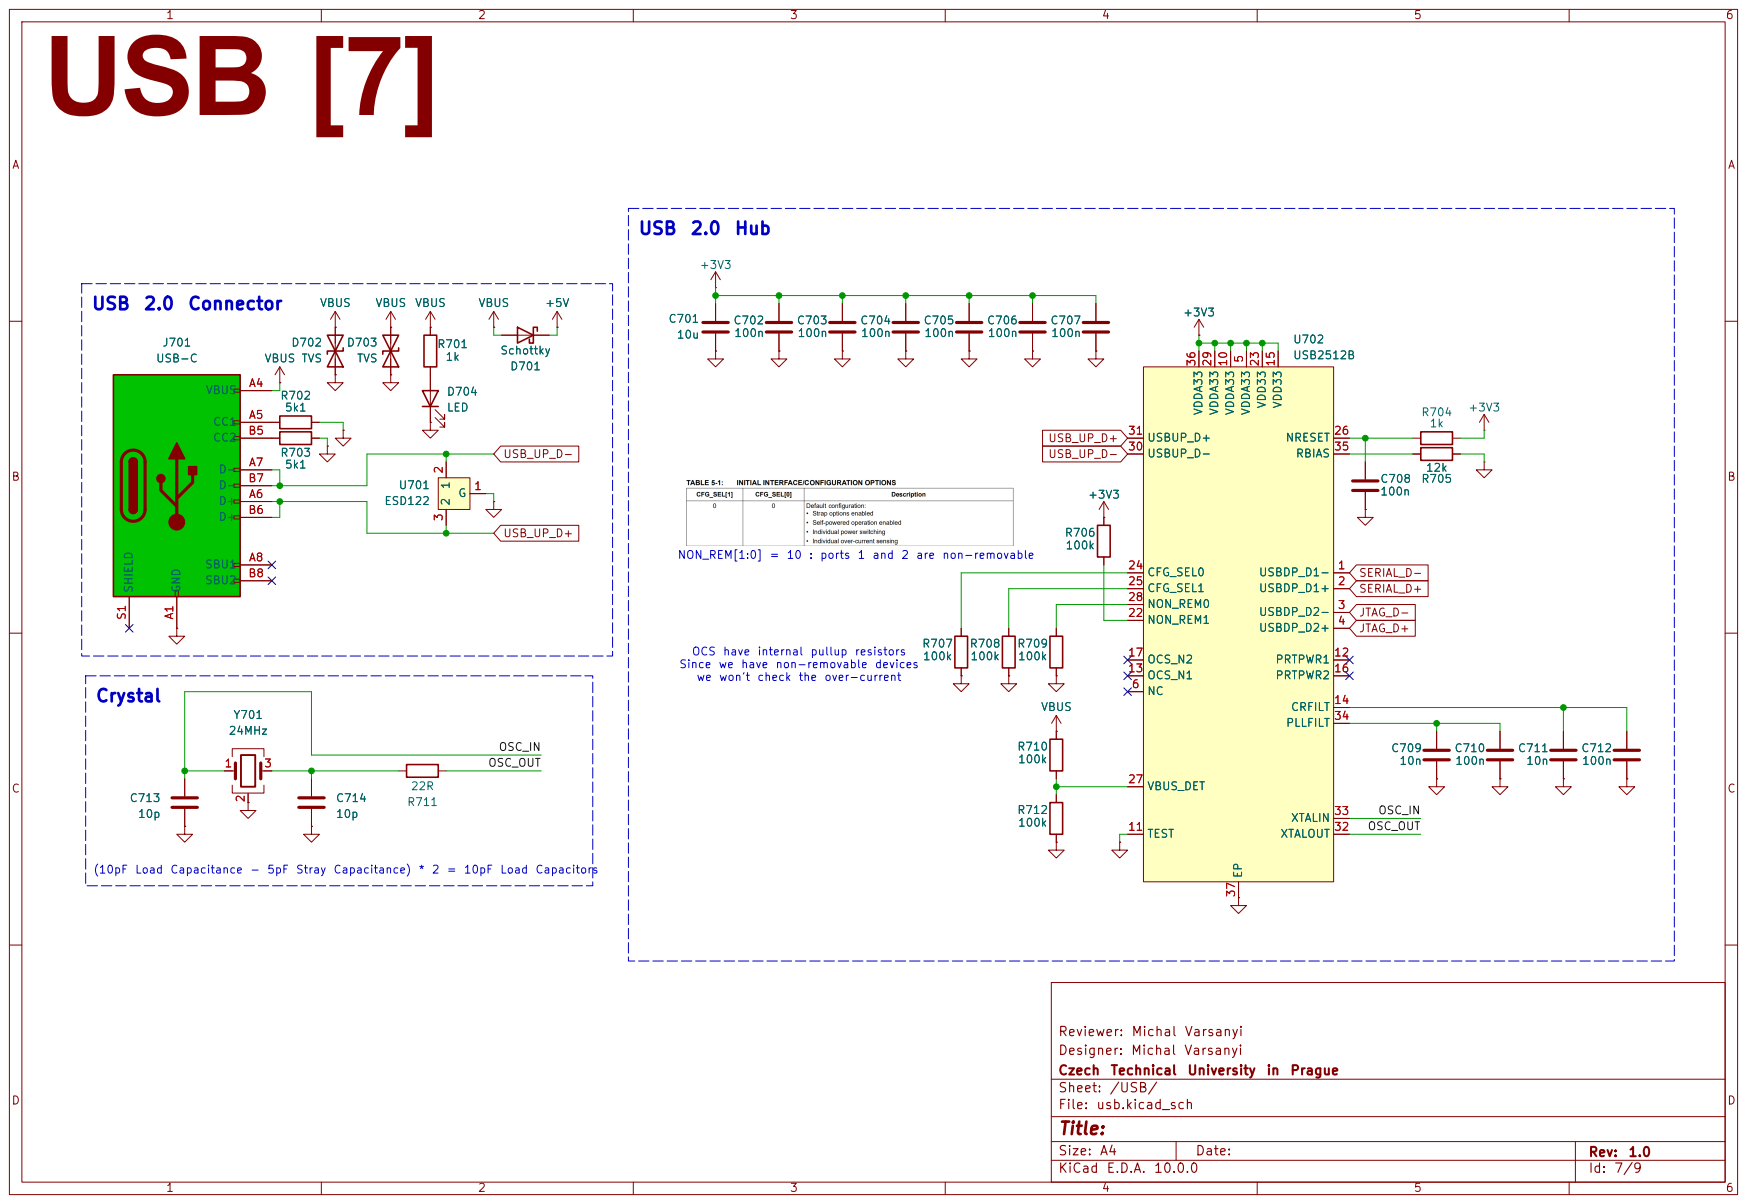
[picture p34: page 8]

OCS have internal pullup resistors Since we have non-removable devices we won't check the over-current NON_REM[1:0] = 10 : ports 1 and 2 are non-removable

Reviewer: Michal Varsanyi GND A1

Designer: Michal Varsanyi
Czech Technical University in Prague
Sheet: /USB/
File: usb.kicad_sch
Title:

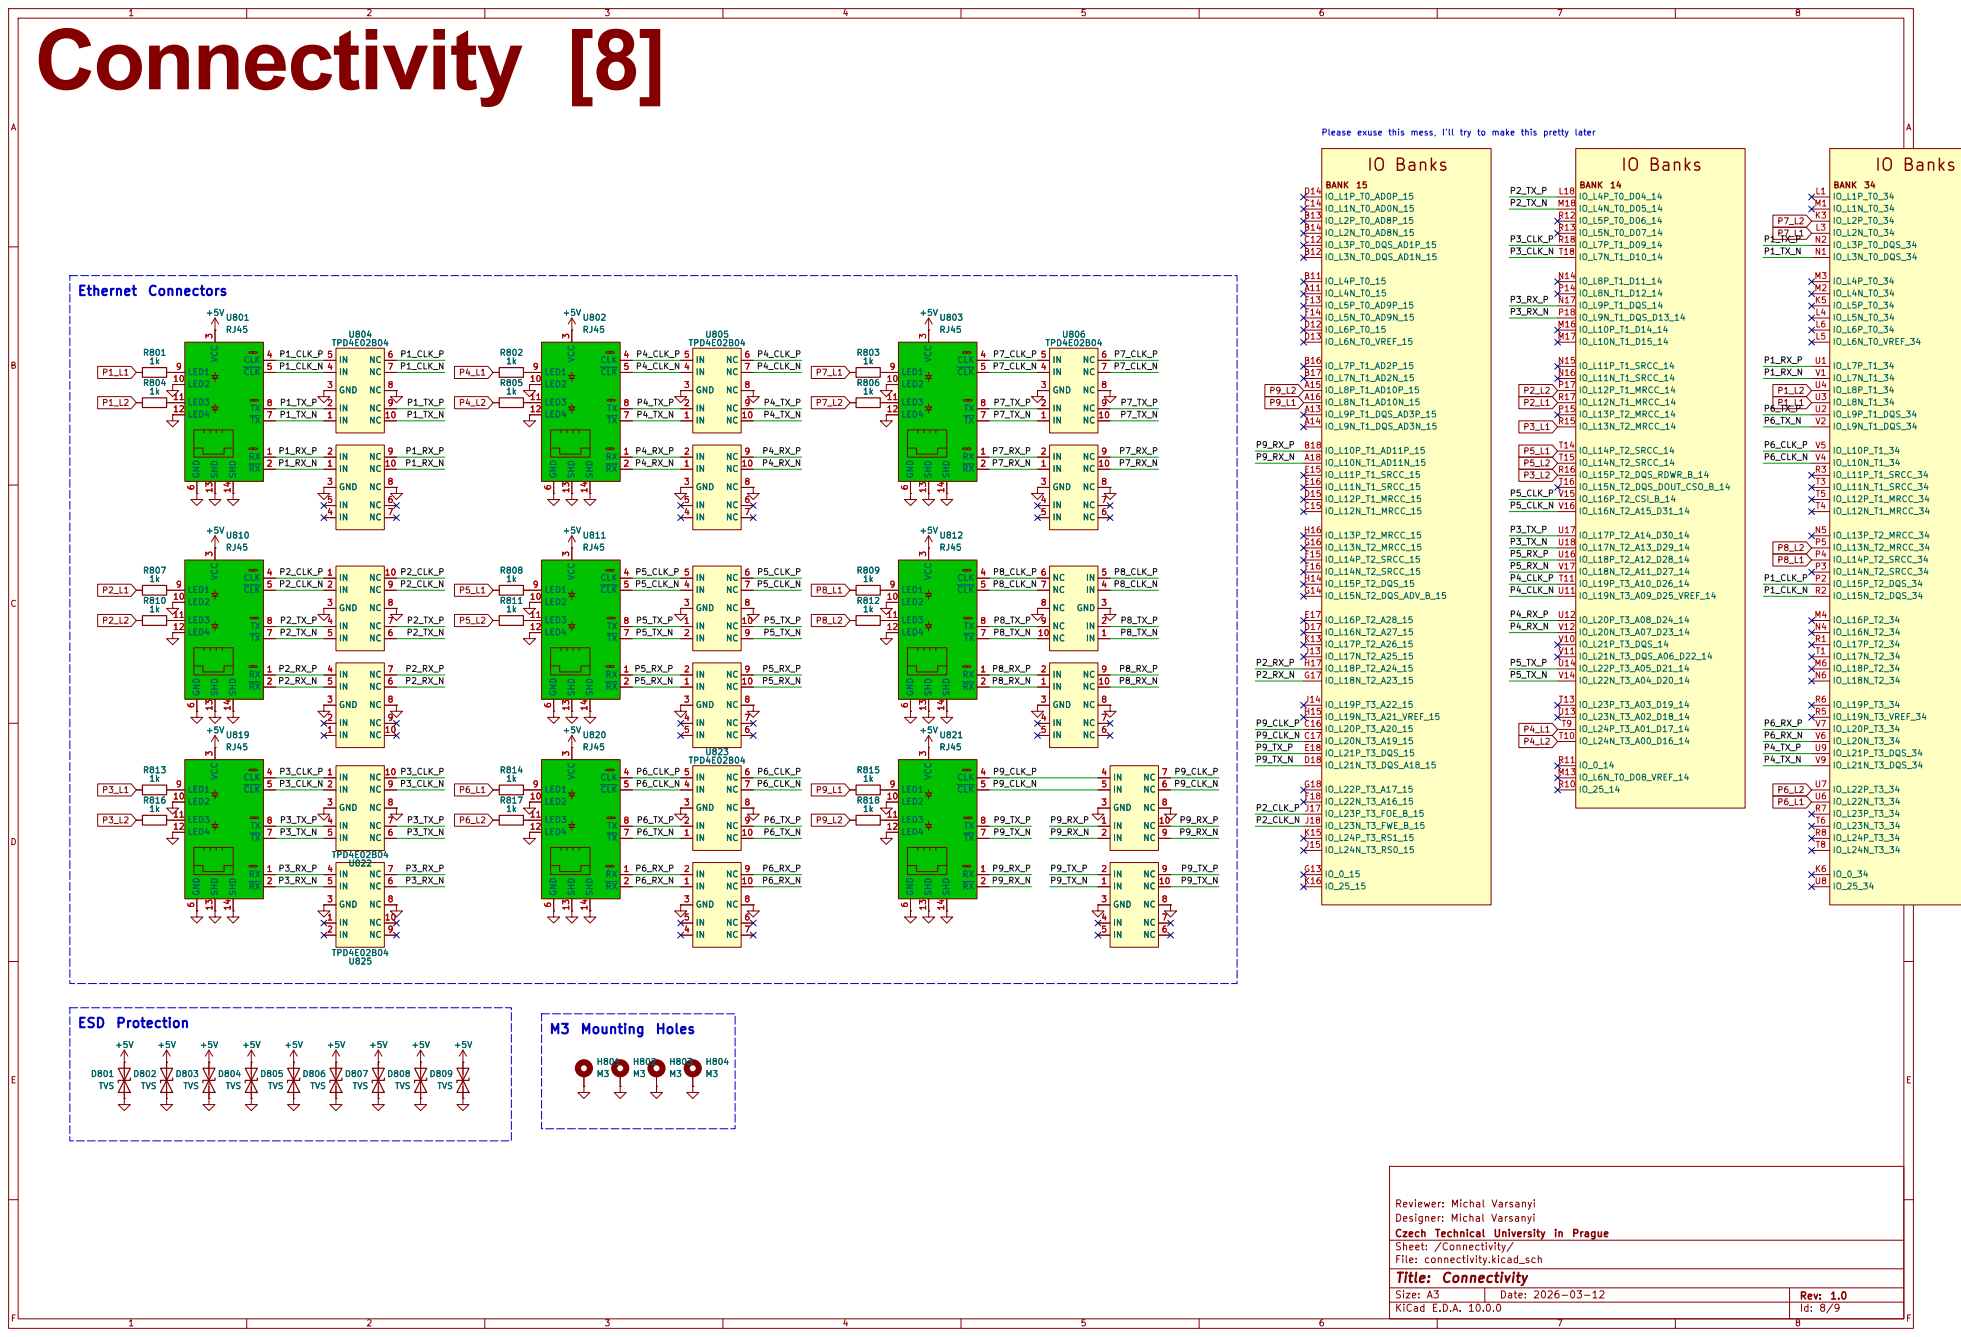
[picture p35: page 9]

Please exuse this mess, I'll try to make this pretty later Connectivity [8]

Reviewer: Michal Varsanyi
Designer: Michal Varsanyi
Czech Technical University in Prague
Sheet: /Connectivity/
File: connectivity.kicad_sch
Title: Connectivity
F Date: 2026-03-12 KiCad E.D.A. 10.0.0

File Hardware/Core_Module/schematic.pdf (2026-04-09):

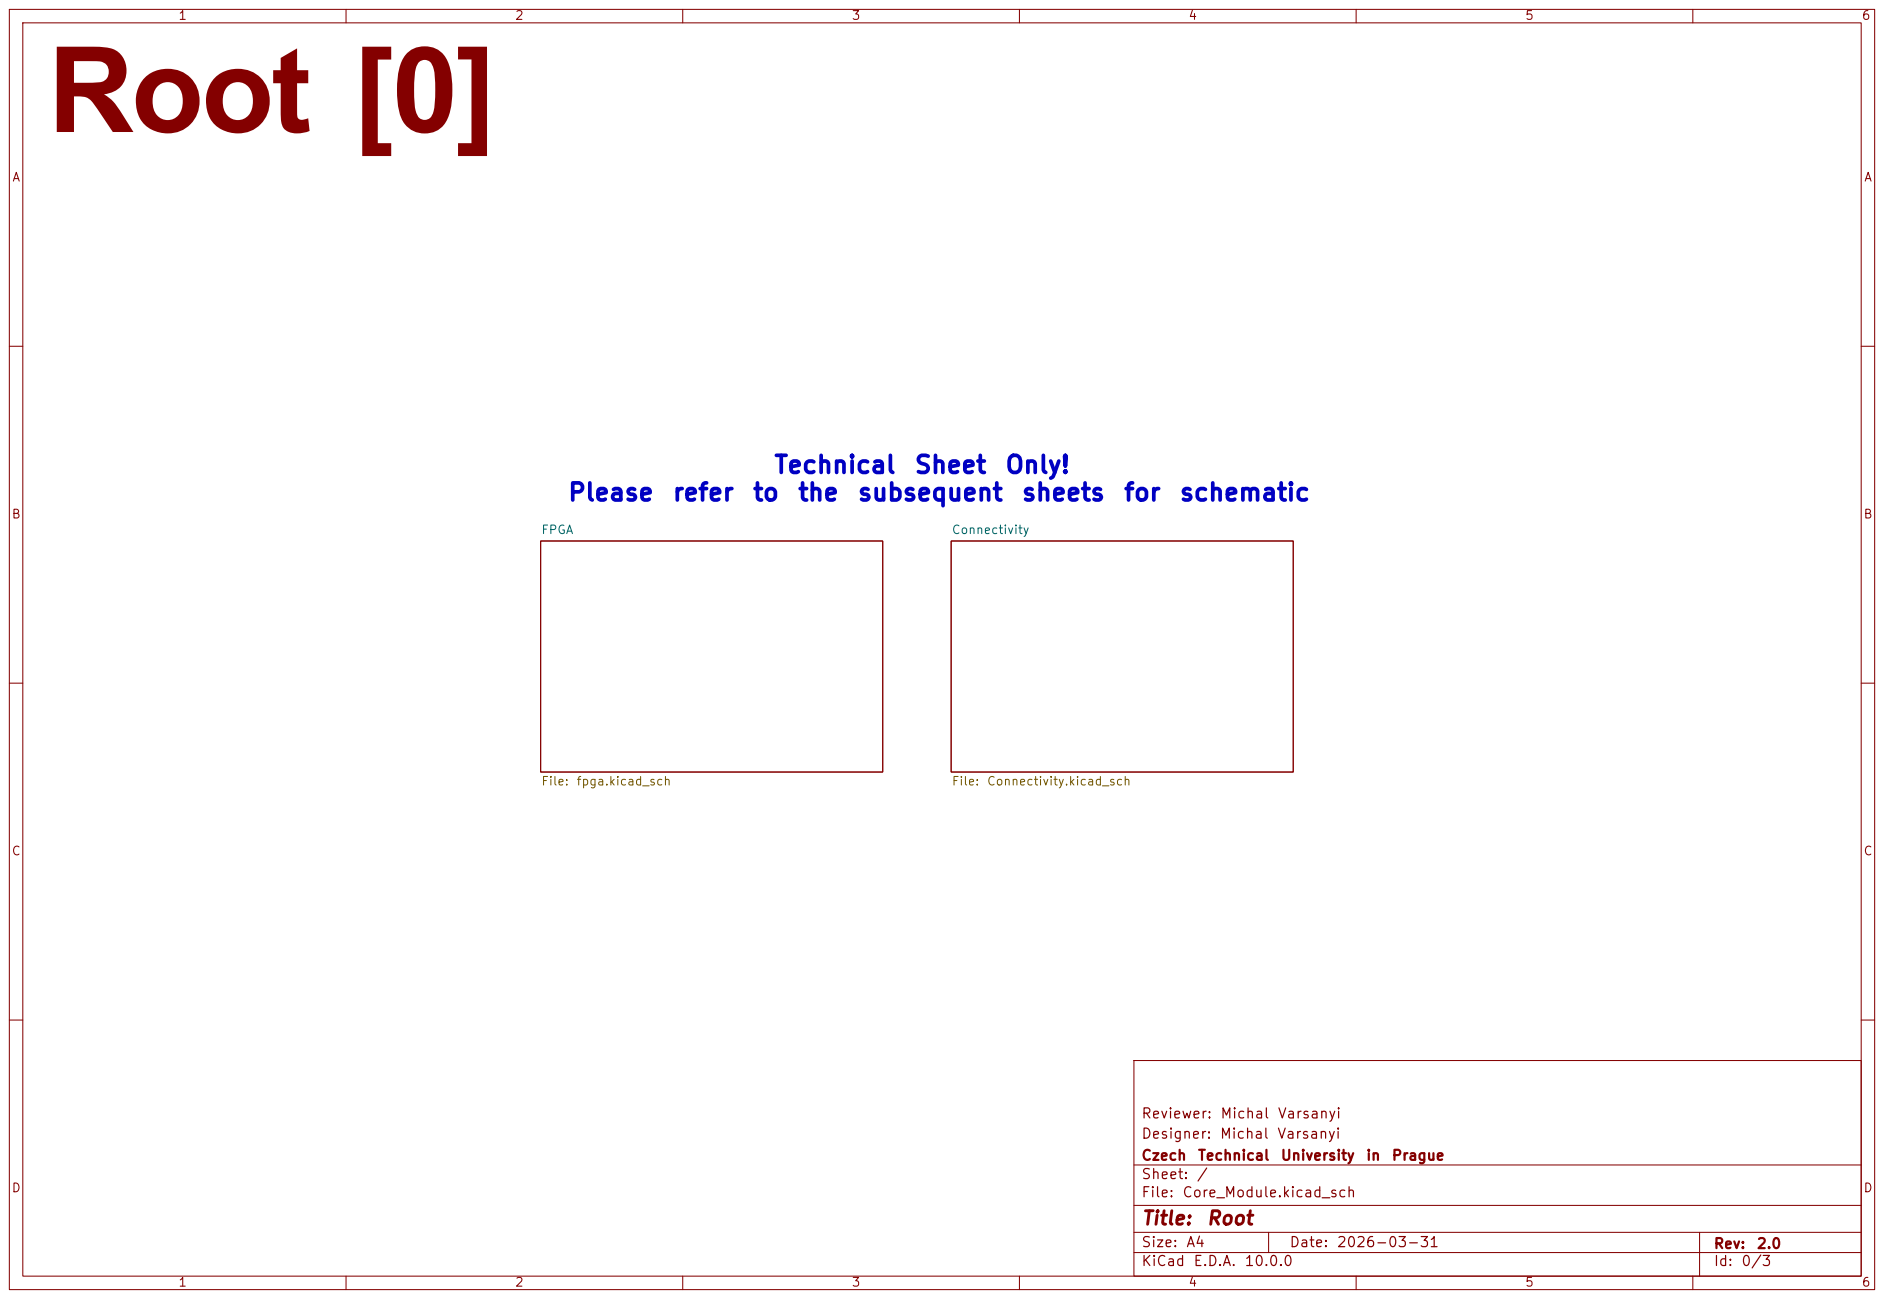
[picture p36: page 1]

Please refer to the subsequent sheets for schematic

Designer: Michal Varsanyi
Czech Technical University in Prague
Sheet: /
D Date: 2026-03-31 KiCad E.D.A. 10.0.0
File: Core_Module.kicad_sch
Title: Root

Size: A4 | Rev: 2.0

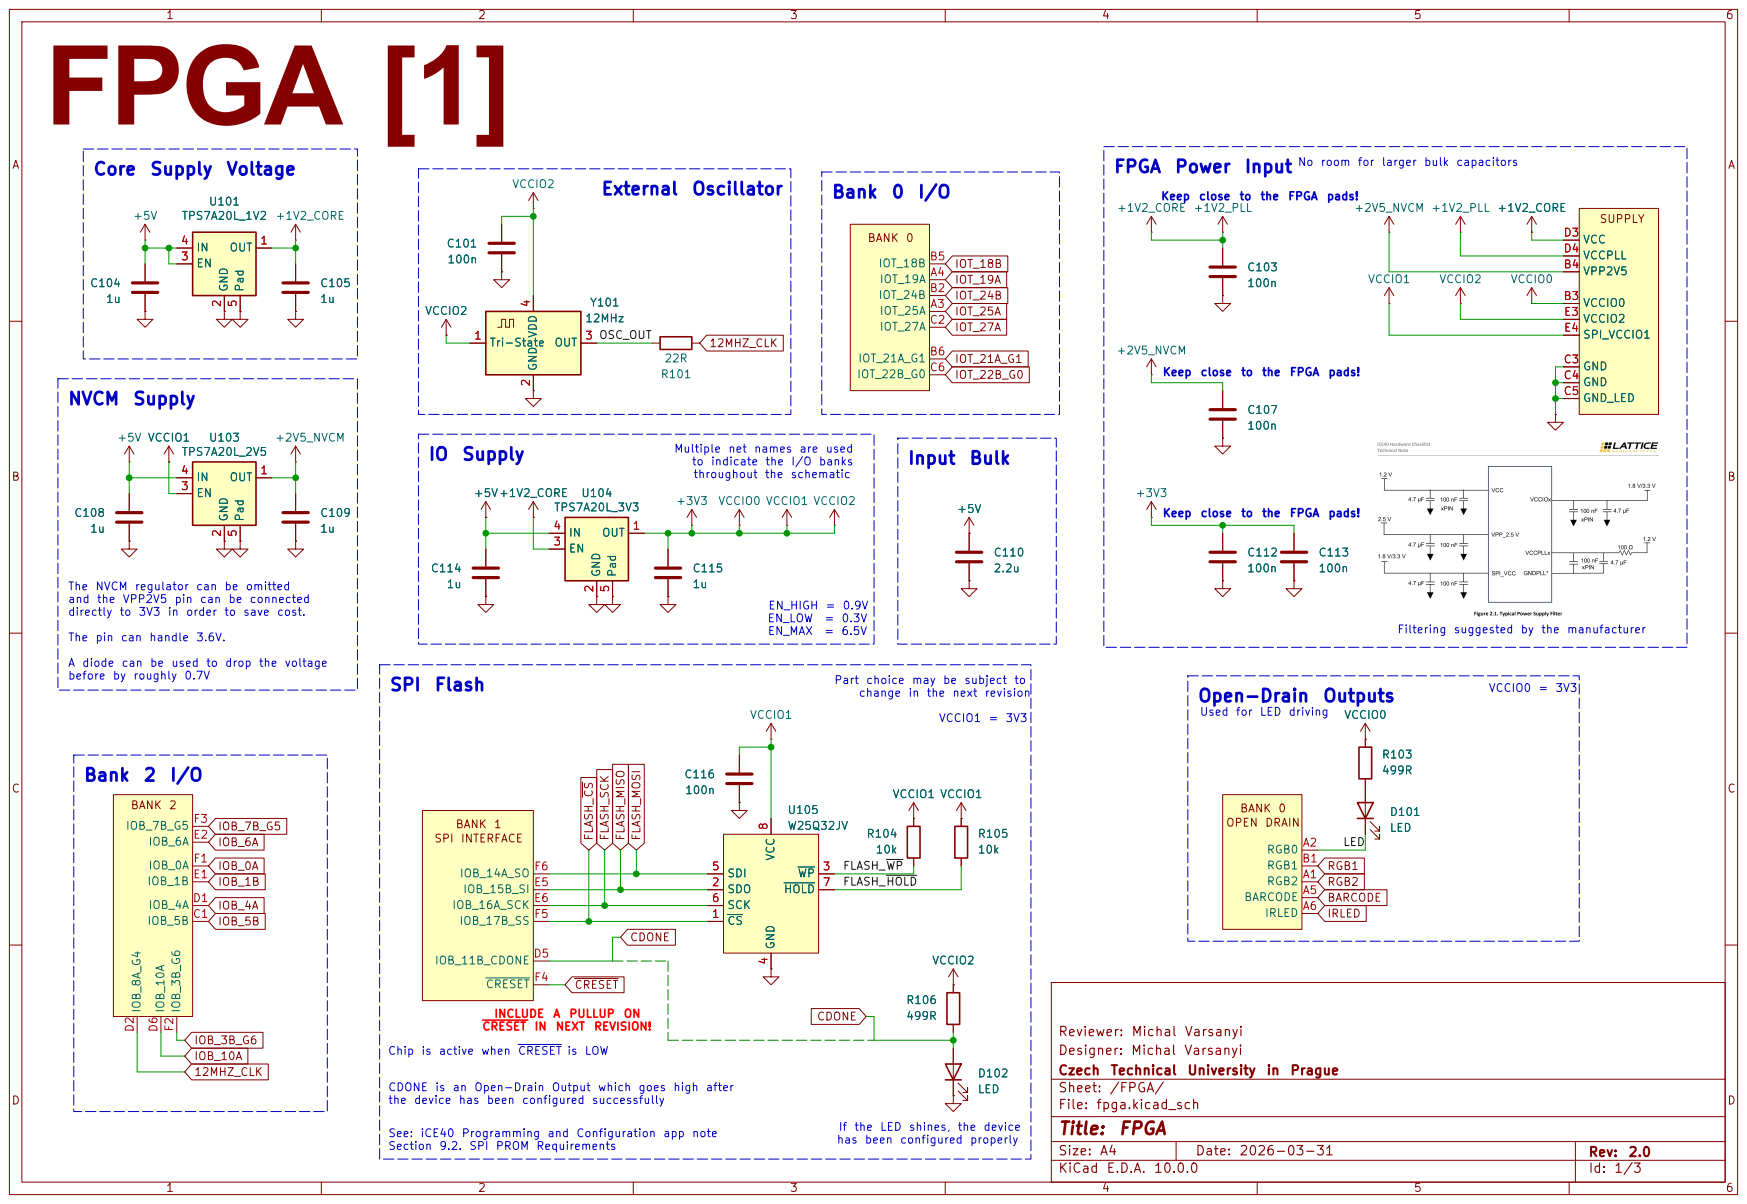
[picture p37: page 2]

change in the next revision FPGA [1]

Keep close to the FPGA pads!

VCCIO0 = 3V3 Keep close to the FPGA pads!

Multiple net names are used
to indicate the I/O banks

throughout the schematic Chip is active when CRESET is LOW

CRESET IN NEXT REVISION! C108

The NVCM regulator can be omitted
and the VPP2V5 pin can be connected
directly to 3V3 in order to save cost. The pin can handle 3.6V. A diode can be used to drop the voltage

Filtering suggested by the manufacturer CDONE is an Open-Drain Output which goes high after

VCCIO1 = 3V3 Part choice may be subject to

Open-Drain Outputs
Used for LED driving

Designer: Michal Varsanyi
Czech Technical University in Prague
Sheet: /FPGA/
D Date: 2026-03-31 KiCad E.D.A. 10.0.0
File: fpga.kicad_sch
Title: FPGA

the device has been configured successfully

See: iCE40 Programming and Configuration app note Section 9.2. SPI PROM Requirements

If the LED shines, the device has been configured properly


Designer: Michal Varsanyi
Czech Technical University in Prague

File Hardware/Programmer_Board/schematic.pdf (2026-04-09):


Please refer to the subsequent sheets for schematic

Czech Technical University in Prague
Sheet: /
D Date: 2025-12-09 KiCad E.D.A. 10.0.0
File: Programmer_Board.kicad_sch
Title: VoxSense Sensor Board Programmer - Root

Size: A4 | Rev: 1.0


Tag Connect Programming Interface

Surge Protection Resistor See Analog Devices AN88F


5 REF 6 DM 7 DP 8 VPLL 9 AGND 10 GND 11 VCORE 12

1 OSCI 2 OSCO 3 VPHY 4 GND

Ref through 12k to GND! RESET through 1k to 3V3! (10pF Load Capacitance - 5pF Stray Capacitance) * 2 = 10pF Load Capacitors

Czech Technical University in Prague GND

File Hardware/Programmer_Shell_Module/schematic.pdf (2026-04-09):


Programmer color coding
conversion to VoxLink with

Designer: Michal Varsanyi
Czech Technical University in Prague
Sheet: /
D Date: 2026-04-08 KiCad E.D.A. 10.0.0
File: Programmer_Shell_Module.kicad_sch
Title: Programmer Shell Module

Size: A4 | Rev: 1.0

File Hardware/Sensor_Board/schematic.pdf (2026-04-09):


Please refer to the subsequent sheets for schematic

Czech Technical University in Prague
Sheet: /
D Date: 2025-11-17 KiCad E.D.A. 10.0.0
File: VoxSense.kicad_sch
Title: VoxSense Sensor Board - Root

Size: A4 | Rev: 1.0


Surge Protection Resistor See Analog Devices AN88F

for reverse polarity protection R1=420k R2=25.5k R3=100k UVLO_Rising = 4.3V UVLO_Falling = 4V OVP_Rising = 5.4V OVP_Falling = 5.01V 0.99*(R1+R2+R3)=5.4*R3

ILIM sets the current imit of the eFuse. Datasheet specifies 450mA if I_lim is left open. The largest tested value of ILIM is 150kOhm (580mA)

I_mon is only used for external sensing

Czech Technical University in Prague
Sheet: /eFuse/
D Date: 2025-12-04 KiCad E.D.A. 10.0.0
File: efuse.kicad_sch
Title: eFuse


4u7 +1V2_CORE CRESET CT Core Supply Voltage

Note that CRESET is active LOW, meaning the FPGA is active when CRESET is HIGH. This requires a RESET variant of the TLV840 chip

which active LOW, meaning it is the

the 1V2_CORE and 1V2_PLL have to be connected together.

U204 is removed in the

Keep close to the FPGA pads!

The NVCM regulator can be omitted
and the VPP2V5 pin can be connected
directly to 3V3 in order to save cost. The pin can handle 3.6V. A diode can be used to drop the voltage

The FPGA wakes up after rougly 10us, however, the memory
takes 150us to boot. We need to delay the FPGA startup, so
that the flash memory is ready.

to indicate the I/O banks
throughout the schematic

Czech Technical University in Prague
Sheet: /Power/
D Date: 2025-11-09 KiCad E.D.A. 10.0.0
File: power.kicad_sch
Title: Power


Open-Drain Outputs
change in the next revision Used for LED driving

Tag Connect Programming Interface

D302 is removed in the
prototype version

VCCIO1 = 3V3 Part choice may be subject to

Chip is active when CRESET is LOW

CDONE is an Open-Drain Output which goes high after
the device has been configured successfully

If the LED shines, the device has been configured properly

Czech Technical University in Prague
Sheet: /System/
D Date: 2025-11-17 KiCad E.D.A. 10.0.0
File: System.kicad_sch
Title: System


Interrupt to host device Only for SPI Keep close to IC pads!

3 BOOT 4 PS1 5 PS0/WAKE 6 CAP 9 CLKSEL0 10 RST 11 H_INT 14 ENV_SCL 15 ENV_SDA 16

NEXT REVISION: Connect H_INT to FPGA! C404

For daisy-chaining temperatre/humidity sensors. Even unused needs to be teminated with

pullup resistors as per the I2C standard! (12.5pF Load Capacitance - 5pF Stray Capacitance) * 2 = 15pF Load Capacitors

Czech Technical University in Prague
Sheet: /Sensor/
D Date: 2025-11-18 KiCad E.D.A. 10.0.0
File: Sensor.kicad_sch
Title: Sensor


RJ45 is One-to-One meaning we don't flip the connector SEL = LOW -> A and B are conencted SEL = HIGH -> A and C are conencted Connectivity [5]

VOX_RX_N VoxLink Ethernet Connection + Bus / Daisy Chain Switch

No Placement (NOP) - Used for the possibility of terminating the differential pairs to prevent reflections U502

Table of differential comparator pin pairs

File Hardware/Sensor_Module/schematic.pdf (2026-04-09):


Please refer to the subsequent sheets for schematic

Reviewer: Michal Varsanyi
Designer: Michal Varsanyi
Czech Technical University in Prague
Sheet: /
D Date: 2026-04-02 KiCad E.D.A. 10.0.0
File: Sensor_Module.kicad_sch
Title: Root

Size: A4 | Rev: 2.0


pullup resistors as per the I2C standard! Sensor [1]

3 BOOT 4 PS1 5 PS0/WAKE 6 CAP 9 CLKSEL0 10 RST 11 H_INT 14 ENV_SCL 15 ENV_SDA 16

IO Supply I2C Address Selection HIGH = 0x4B

For daisy-chaining temperatre/humidity sensors. Even unused needs to be teminated with

for external clock CEVA recommends using a crystal with tolerance 50ppm with 12.5pF capacitor loading.

Reviewer: Michal Varsanyi
Designer: Michal Varsanyi
Czech Technical University in Prague
Sheet: /Sensor/
D Date: 2026-04-02 KiCad E.D.A. 10.0.0
File: sensor.kicad_sch
Title: Sensor

(12.5pF Load Capacitance - 5pF Stray Capacitance) * 2 = 15pF Load Capacitors


Designer: Michal Varsanyi
Czech Technical University in Prague
Sheet: /Connectivity/
D Date: 2026-04-02 KiCad E.D.A. 10.0.0
File: connectivity.kicad_sch
Title: Connectivity

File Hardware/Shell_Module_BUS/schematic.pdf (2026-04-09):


the BotBlox 8-way cable Shell Module Bus

VoxLink color coding with

Designer: Michal Varsanyi
Czech Technical University in Prague
Sheet: /
D Date: 2026-04-02 KiCad E.D.A. 10.0.0
File: Shell_Module_BUS.kicad_sch
Title: VoxLink - Shell Module Bus

Size: A4 | Rev: 1.0

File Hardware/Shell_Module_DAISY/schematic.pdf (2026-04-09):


FPGA Manual Reset Shell Module Daisy

the BotBlox 8-way cable U2

Designer: Michal Varsanyi
Czech Technical University in Prague
Sheet: /
D Date: 2026-04-02 KiCad E.D.A. 10.0.0
File: Shell_Module_DAISY.kicad_sch
Title: VoxLink - Shell Module Daisy

Size: A4 | Rev: 1.0

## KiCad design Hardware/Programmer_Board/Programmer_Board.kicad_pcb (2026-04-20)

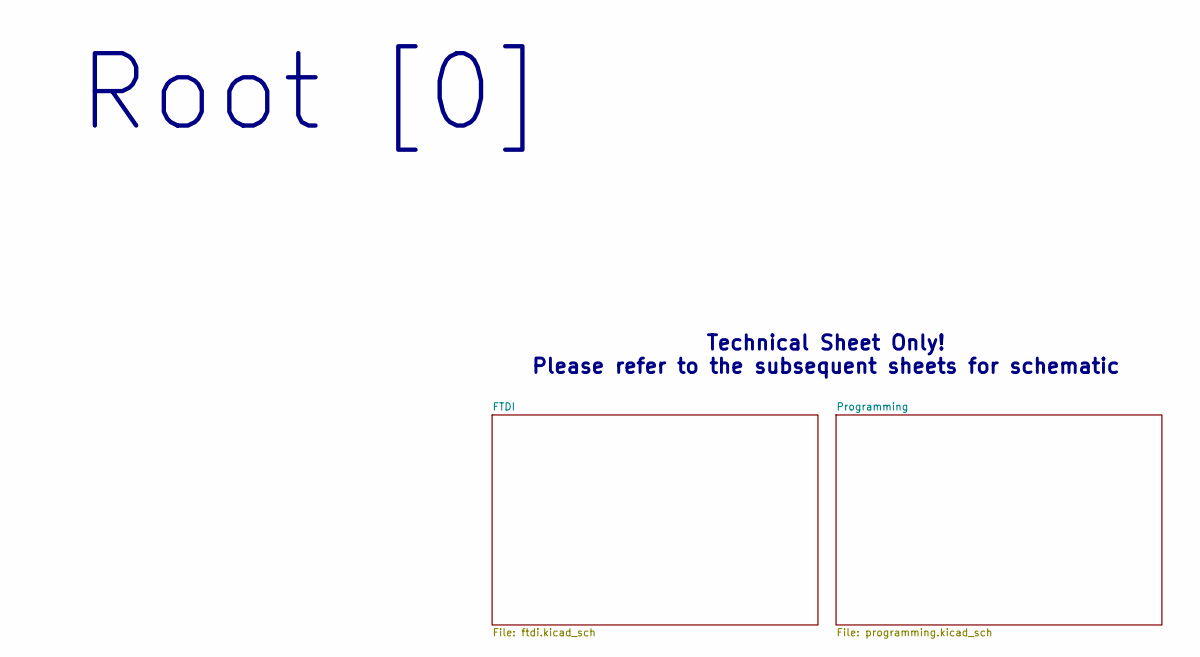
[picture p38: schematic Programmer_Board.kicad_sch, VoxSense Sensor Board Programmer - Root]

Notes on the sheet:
Technical Sheet Only! Please refer to the subsequent sheets for schematic
Root [0]

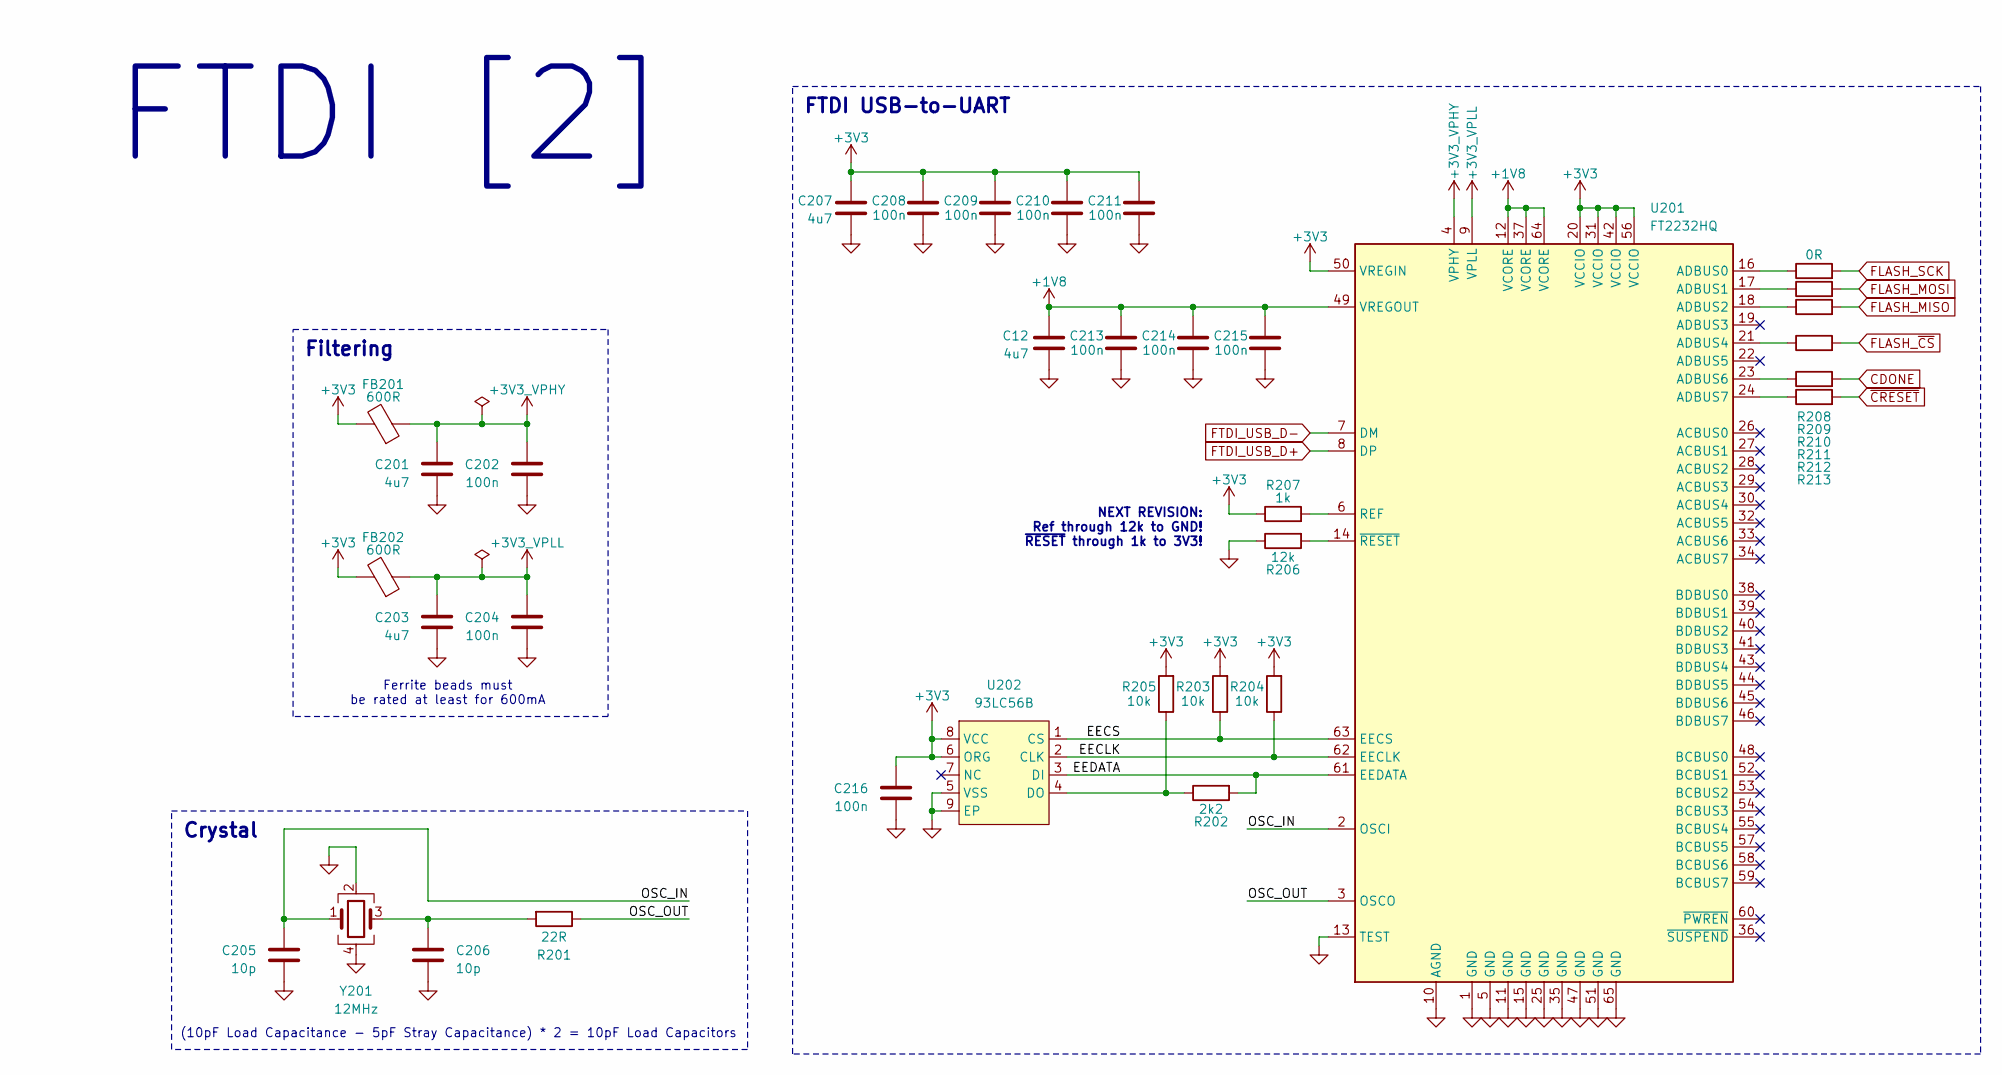
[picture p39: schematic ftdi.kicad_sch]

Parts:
C12, C201, C203, C207: 4u7; C_0402_1005Metric
C202, C204, C208, C209, C210, C211, C213, C214, C215, C216: 100n; C_0402_1005Metric
C205, C206: 10p; C_0402_1005Metric
FB201, FB202: 600R; L_0402_1005Metric
R201: 22R; R_0402_1005Metric
R202: 2k2; R_0402_1005Metric
R203, R204, R205: 10k; R_0402_1005Metric
R206: 12k; R_0402_1005Metric
R207: 1k; R_0402_1005Metric
R208: 0R; R_0402_1005Metric
R209, R210, R211, R212, R213: R; R_0402_1005Metric
U201: FT2232HQ; QFN-64-1EP_9x9mm_P0.5mm_EP4.35x4.35mm
U202: 93LC56B; TDFN-8-1EP_3x2mm_P0.5mm_EP1.3x1.4mm
Y201: 12MHz; Crystal_SMD_2520-4Pin_2.5x2.0mm

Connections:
+1V8: C12.1, C213.1, C214.1, C215.1, U201.12 (VCORE), U201.37 (VCORE), U201.49 (VREGOUT), U201.64 (VCORE)
+3V3: C207.1, C208.1, C209.1, C210.1, C211.1, C216.1, FB201.2, FB202.2, R203.2, R204.2, R205.2, R207.1, U201.20 (VCCIO), U201.31 (VCCIO), U201.42 (VCCIO), U201.50 (VREGIN), U201.56 (VCCIO), U202.6 (ORG), U202.8 (VCC); also elsewhere on the board
+3V3_VPHY: C201.1, C202.1, FB201.1, U201.4 (VPHY)
+3V3_VPLL: C203.1, C204.1, FB202.1, U201.9 (VPLL)
/FTDI/EECLK: R204.1, U201.62 (EECLK), U202.2 (CLK)
/FTDI/EECS: R203.1, U201.63 (EECS), U202.1 (CS)
/FTDI/EEDATA: R202.2, U201.61 (EEDATA), U202.3 (DI)
/FTDI/OSC_IN: C205.1, U201.2 (OSCI), Y201.1
/FTDI/OSC_OUT: R201.1, U201.3 (OSCO)
CDONE: R212.2; also elsewhere on the board
FLASH_MISO: R210.2; also elsewhere on the board
FLASH_MOSI: R209.2; also elsewhere on the board
FLASH_SCK: R208.2; also elsewhere on the board
FLASH_~CS: R211.2; also elsewhere on the board
FTDI_USB_D+: U201.8 (DP); also elsewhere on the board
FTDI_USB_D-: U201.7 (DM); also elsewhere on the board
GND: C12.2, C201.2, C202.2, C203.2, C204.2, C205.2, C206.2, C207.2, C208.2, C209.2, C210.2, C211.2, C213.2, C214.2, C215.2, C216.2, R206.1, U201.1 (GND), U201.5 (GND), U201.10 (AGND), U201.11 (GND), U201.13 (TEST), U201.15 (GND), U201.25 (GND), U201.35 (GND), U201.47 (GND), U201.51 (GND), U201.65 (GND), U202.5 (VSS), U202.9 (EP), Y201.2, Y201.4; also elsewhere on the board
unnamed: C206.1, R201.2, Y201.3
unnamed: R208.1, U201.16 (ADBUS0)
unnamed: R209.1, U201.17 (ADBUS1)
unnamed: R210.1, U201.18 (ADBUS2)
unnamed: R211.1, U201.21 (ADBUS4)
unnamed: R212.1, U201.23 (ADBUS6)
unnamed: R213.1, U201.24 (ADBUS7)
unnamed: R207.2, U201.6 (REF)
unnamed: R206.2, U201.14 (~RESET)
unnamed: R202.1, R205.1, U202.4 (DO)
~CRESET: R213.2; also elsewhere on the board

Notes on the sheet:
NEXT REVISION: Ref through 12k to GND! ~{RESET} through 1k to 3V3!
(10pF Load Capacitance - 5pF Stray Capacitance) * 2 = 10pF Load Capacitors
FTDI [2]
Ferrite beads must be rated at least for 600mA
Crystal
Filtering
FTDI USB-to-UART

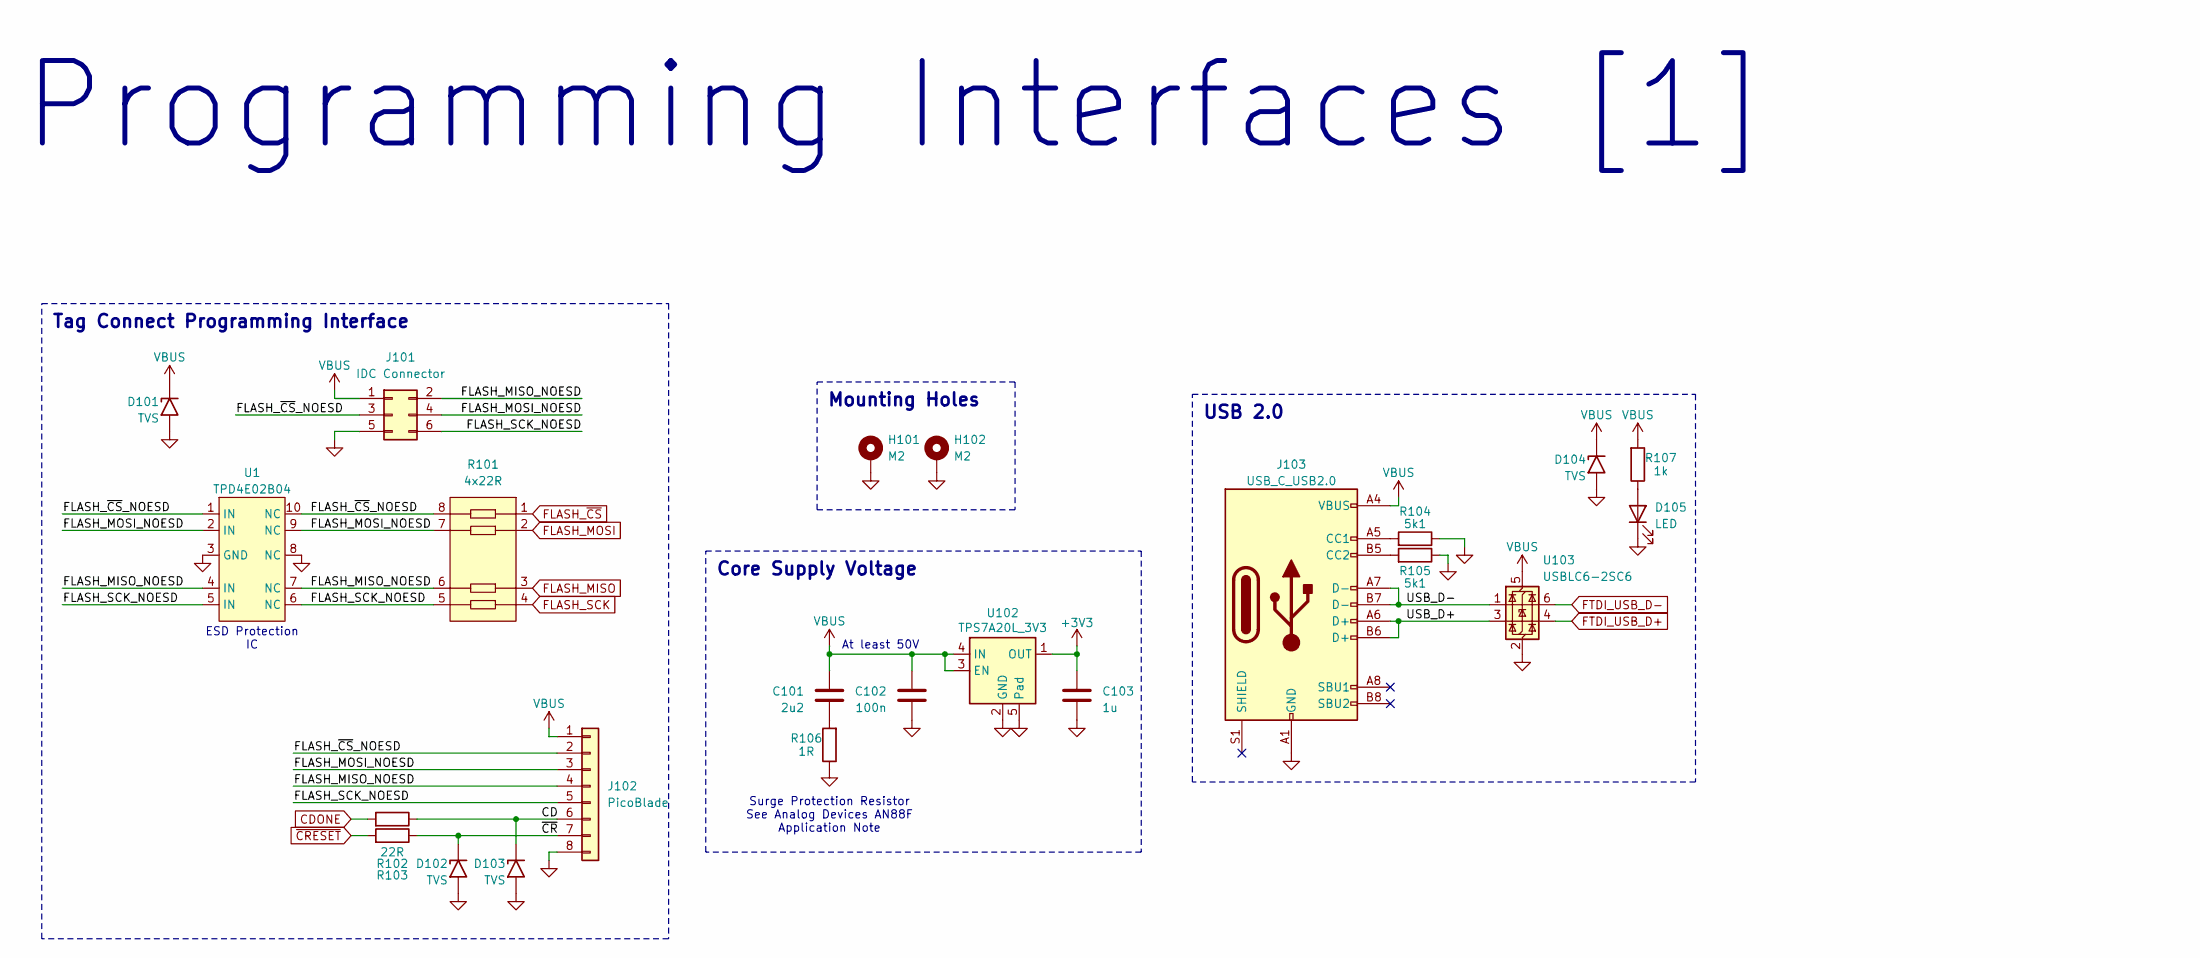
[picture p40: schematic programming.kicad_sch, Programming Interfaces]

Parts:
C101: 2u2; C_0603_1608Metric
C102: 100n; C_0402_1005Metric
C103: 1u; C_0402_1005Metric
D101, D102, D103, D104: TVS; D_0402_1005Metric
D105: LED; LED_0603_1608Metric
H101, H102: M2; MountingHole_2.2mm_M2_Pad_Via
J101: IDC Connector; IDC-Header_2x03_P2.54mm_Horizontal
J102: PicoBlade; Molex_PicoBlade_53048-0810_1x08_P1.25mm_Horizontal
J103: USB_C_USB2.0; USB_C_Receptacle_GCT_USB4105-xx-A_16P_TopMnt_Horizontal
R101: 4x22R; EXBN8V101JX
R102, R103: 22R; R_0402_1005Metric
R104, R105: 5k1; R_0402_1005Metric
R106: 1R; R_0402_1005Metric
R107: 1k; R_0402_1005Metric
U1: TPD4E02B04; USON-10_2.5x1.0mm_P0.5mm__Reduced_Paste
U102: TPS7A20L_3V3; Texas_X2SON-4_1x1mm_P0.65mm
U103: USBLC6-2SC6; SOT-23-6

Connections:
+3V3: C103.1, U102.1 (OUT); also elsewhere on the board
/Programming/CD: D103.1 (A1), J102.6, R102.1
/Programming/FLASH_MISO_NOESD: J101.2, J102.4, R101.6, U1.4 (IN), U1.7 (NC)
/Programming/FLASH_MOSI_NOESD: J101.4, J102.3, R101.7, U1.2 (IN), U1.9 (NC)
/Programming/FLASH_SCK_NOESD: J101.6, J102.5, R101.5, U1.5 (IN), U1.6 (NC)
/Programming/FLASH_~CS_NOESD: J101.3, J102.2, R101.8, U1.1 (IN), U1.10 (NC)
/Programming/USB_D+: J103.A6 (D+), J103.B6 (D+), U103.3 (I/O2)
/Programming/USB_D-: J103.A7 (D-), J103.B7 (D-), U103.1 (I/O1)
/Programming/~CR: D102.1 (A1), J102.7, R103.1
CDONE: R102.2; also elsewhere on the board
FLASH_MISO: R101.3; also elsewhere on the board
FLASH_MOSI: R101.2; also elsewhere on the board
FLASH_SCK: R101.4; also elsewhere on the board
FLASH_~CS: R101.1; also elsewhere on the board
FTDI_USB_D+: U103.4 (I/O2); also elsewhere on the board
FTDI_USB_D-: U103.6 (I/O1); also elsewhere on the board
GND: C102.2, C103.2, D101.2 (A2), D102.2 (A2), D103.2 (A2), D104.2 (A2), D105.1 (K), H101.1, H102.1, J101.5, J102.8, J103.A1 (GND), J103.A12 (GND), J103.B1 (GND), J103.B12 (GND), R104.1, R105.1, R106.1, U1.3 (GND), U1.8 (NC), U102.2 (GND), U102.5 (Pad), U103.2 (GND); also elsewhere on the board
unnamed: C101.2, R106.2
unnamed: D105.2 (A), R107.1
unnamed: J103.A5 (CC1), R104.2
unnamed: J103.B5 (CC2), R105.2
VBUS: C101.1, C102.1, D101.1 (A1), D104.1 (A1), J101.1, J102.1, J103.A4 (VBUS), J103.A9 (VBUS), J103.B4 (VBUS), J103.B9 (VBUS), R107.2, U102.3 (EN), U102.4 (IN), U103.5 (VBUS)
~CRESET: R103.2; also elsewhere on the board

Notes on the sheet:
ESD Protection IC
Surge Protection Resistor See Analog Devices AN88F Application Note
At least 50V
Programming Interfaces [1]
Core Supply Voltage
Mounting Holes
Tag Connect Programming Interface
USB 2.0

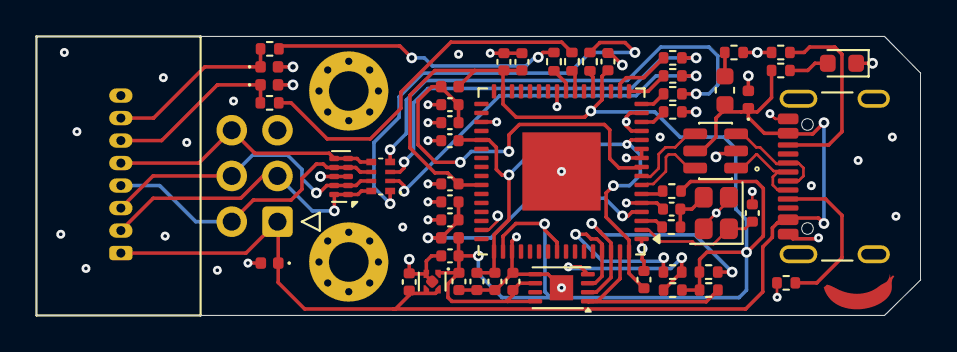
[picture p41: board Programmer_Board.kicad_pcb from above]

Board: 4 copper layers, 49.1 x 15.5 mm, 57 parts (1 on the bottom side), 41 nets.

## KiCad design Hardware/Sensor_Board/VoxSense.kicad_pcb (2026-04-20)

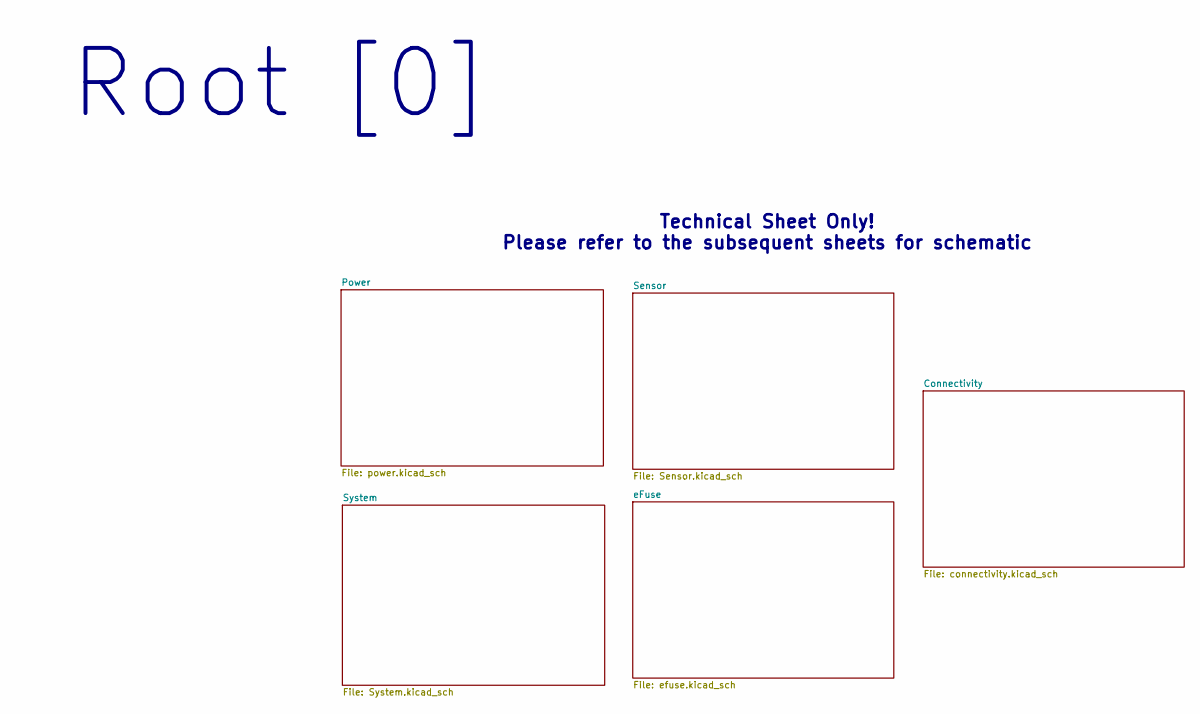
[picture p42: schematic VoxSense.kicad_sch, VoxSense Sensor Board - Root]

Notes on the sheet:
Root [0]
Technical Sheet Only! Please refer to the subsequent sheets for schematic

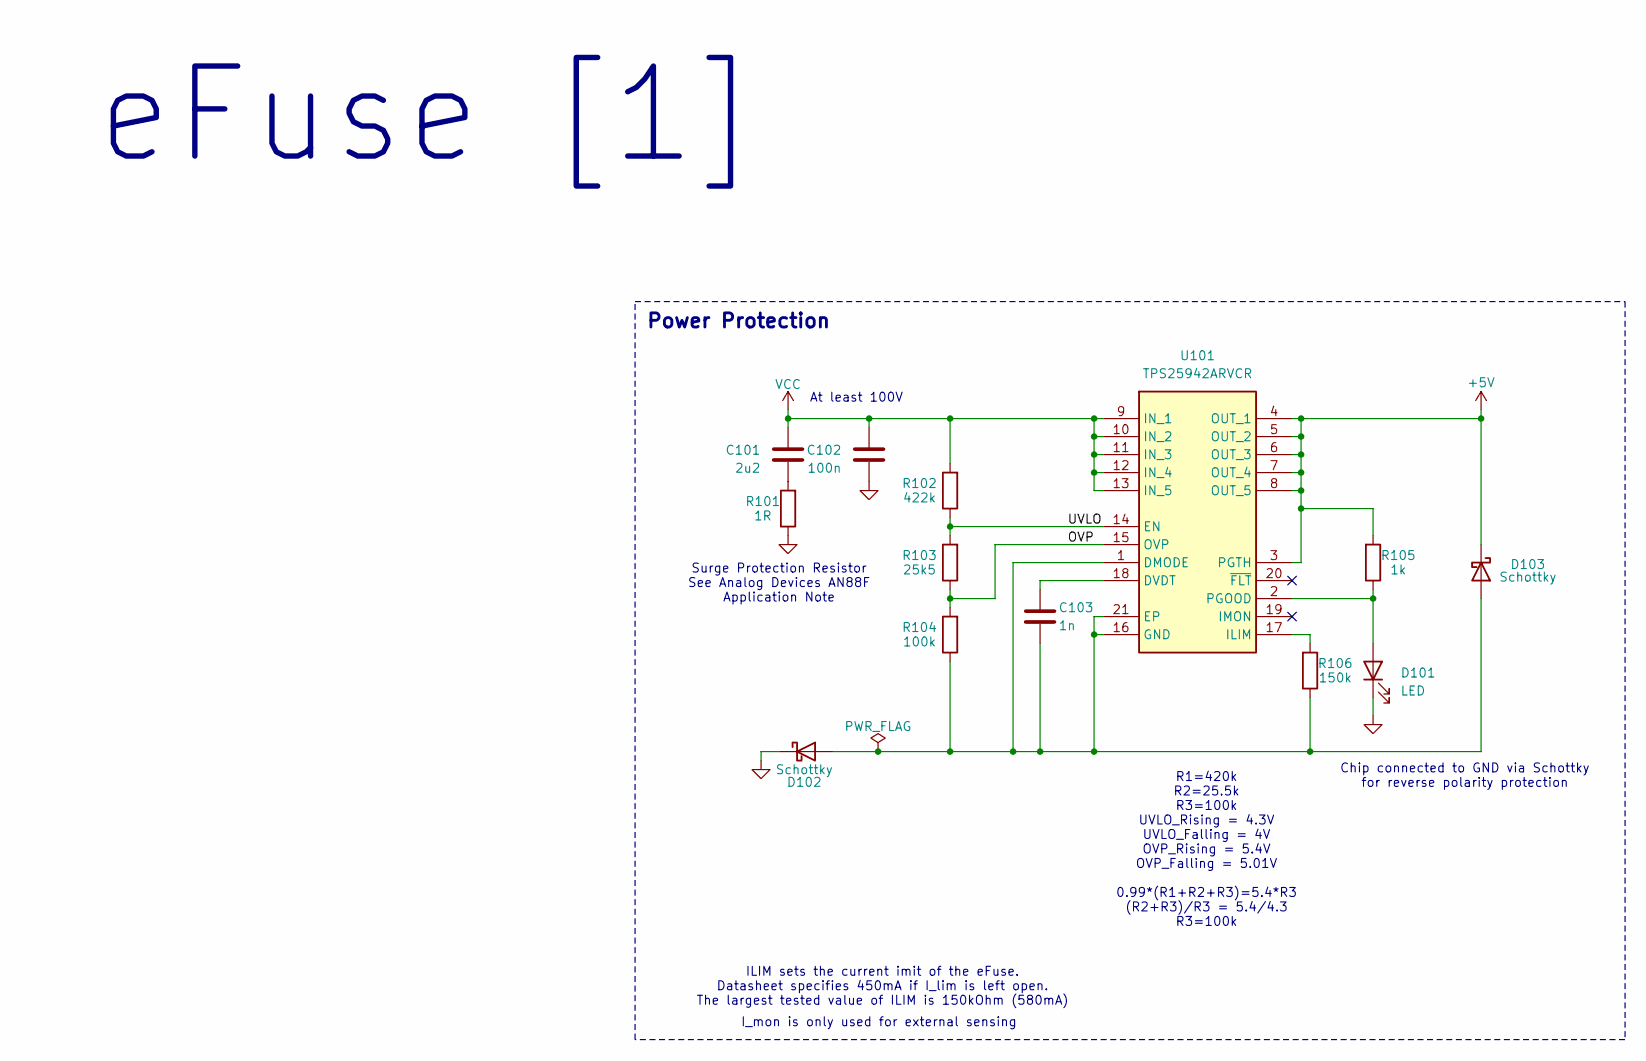
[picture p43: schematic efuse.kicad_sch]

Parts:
C101: 2u2; C_1210_3225Metric
C102: 100n; C_0603_1608Metric
C103: 1n; C_0402_1005Metric
D101: LED; LED_0603_1608Metric
D102, D103: Schottky; D_0402_1005Metric
R101: 1R; R_0603_1608Metric
R102: 422k; R_0402_1005Metric
R103: 25k5; R_0402_1005Metric
R104: 100k; R_0402_1005Metric
R105: 1k; R_0402_1005Metric
R106: 150k; R_0402_1005Metric
U101: TPS25942ARVCR; QFN50P300X400X80-21N

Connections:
+5V: D103.1 (K), R105.2, U101.3 (PGTH), U101.4 (OUT_1), U101.5 (OUT_2), U101.6 (OUT_3), U101.7 (OUT_4), U101.8 (OUT_5); also elsewhere on the board
/eFuse/OVP: R103.1, R104.2, U101.15 (OVP)
/eFuse/UVLO: R102.1, R103.2, U101.14 (EN)
GND: C102.2, D101.1 (K), D102.1 (K), R101.1; also elsewhere on the board
unnamed: C101.2, R101.2
unnamed: D101.2 (A), R105.1, U101.2 (PGOOD)
unnamed: C103.2, D102.2 (A), D103.2 (A), R104.1, R106.1, U101.1 (DMODE), U101.16 (GND), U101.21 (EP)
unnamed: C103.1, U101.18 (DVDT)
unnamed: R106.2, U101.17 (ILIM)
VCC: C101.1, C102.1, R102.2, U101.9 (IN_1), U101.10 (IN_2), U101.11 (IN_3), U101.12 (IN_4), U101.13 (IN_5); also elsewhere on the board

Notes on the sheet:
I_mon is only used for external sensing
ILIM sets the current imit of the eFuse. Datasheet specifies 450mA if I_lim is left open. The largest tested value of ILIM is 150kOhm (580mA)
Chip connected to GND via Schottky for reverse polarity protection
R1=420k R2=25.5k R3=100k UVLO_Rising = 4.3V UVLO_Falling = 4V OVP_Rising = 5.4V OVP_Falling = 5.01V 0.99*(R1+R2+R3)=5.4*R3 (R2+R3)/R3 = 5.4/4.3 R3=100k
eFuse [1]
At least 100V
Surge Protection Resistor See Analog Devices AN88F Application Note
Power Protection

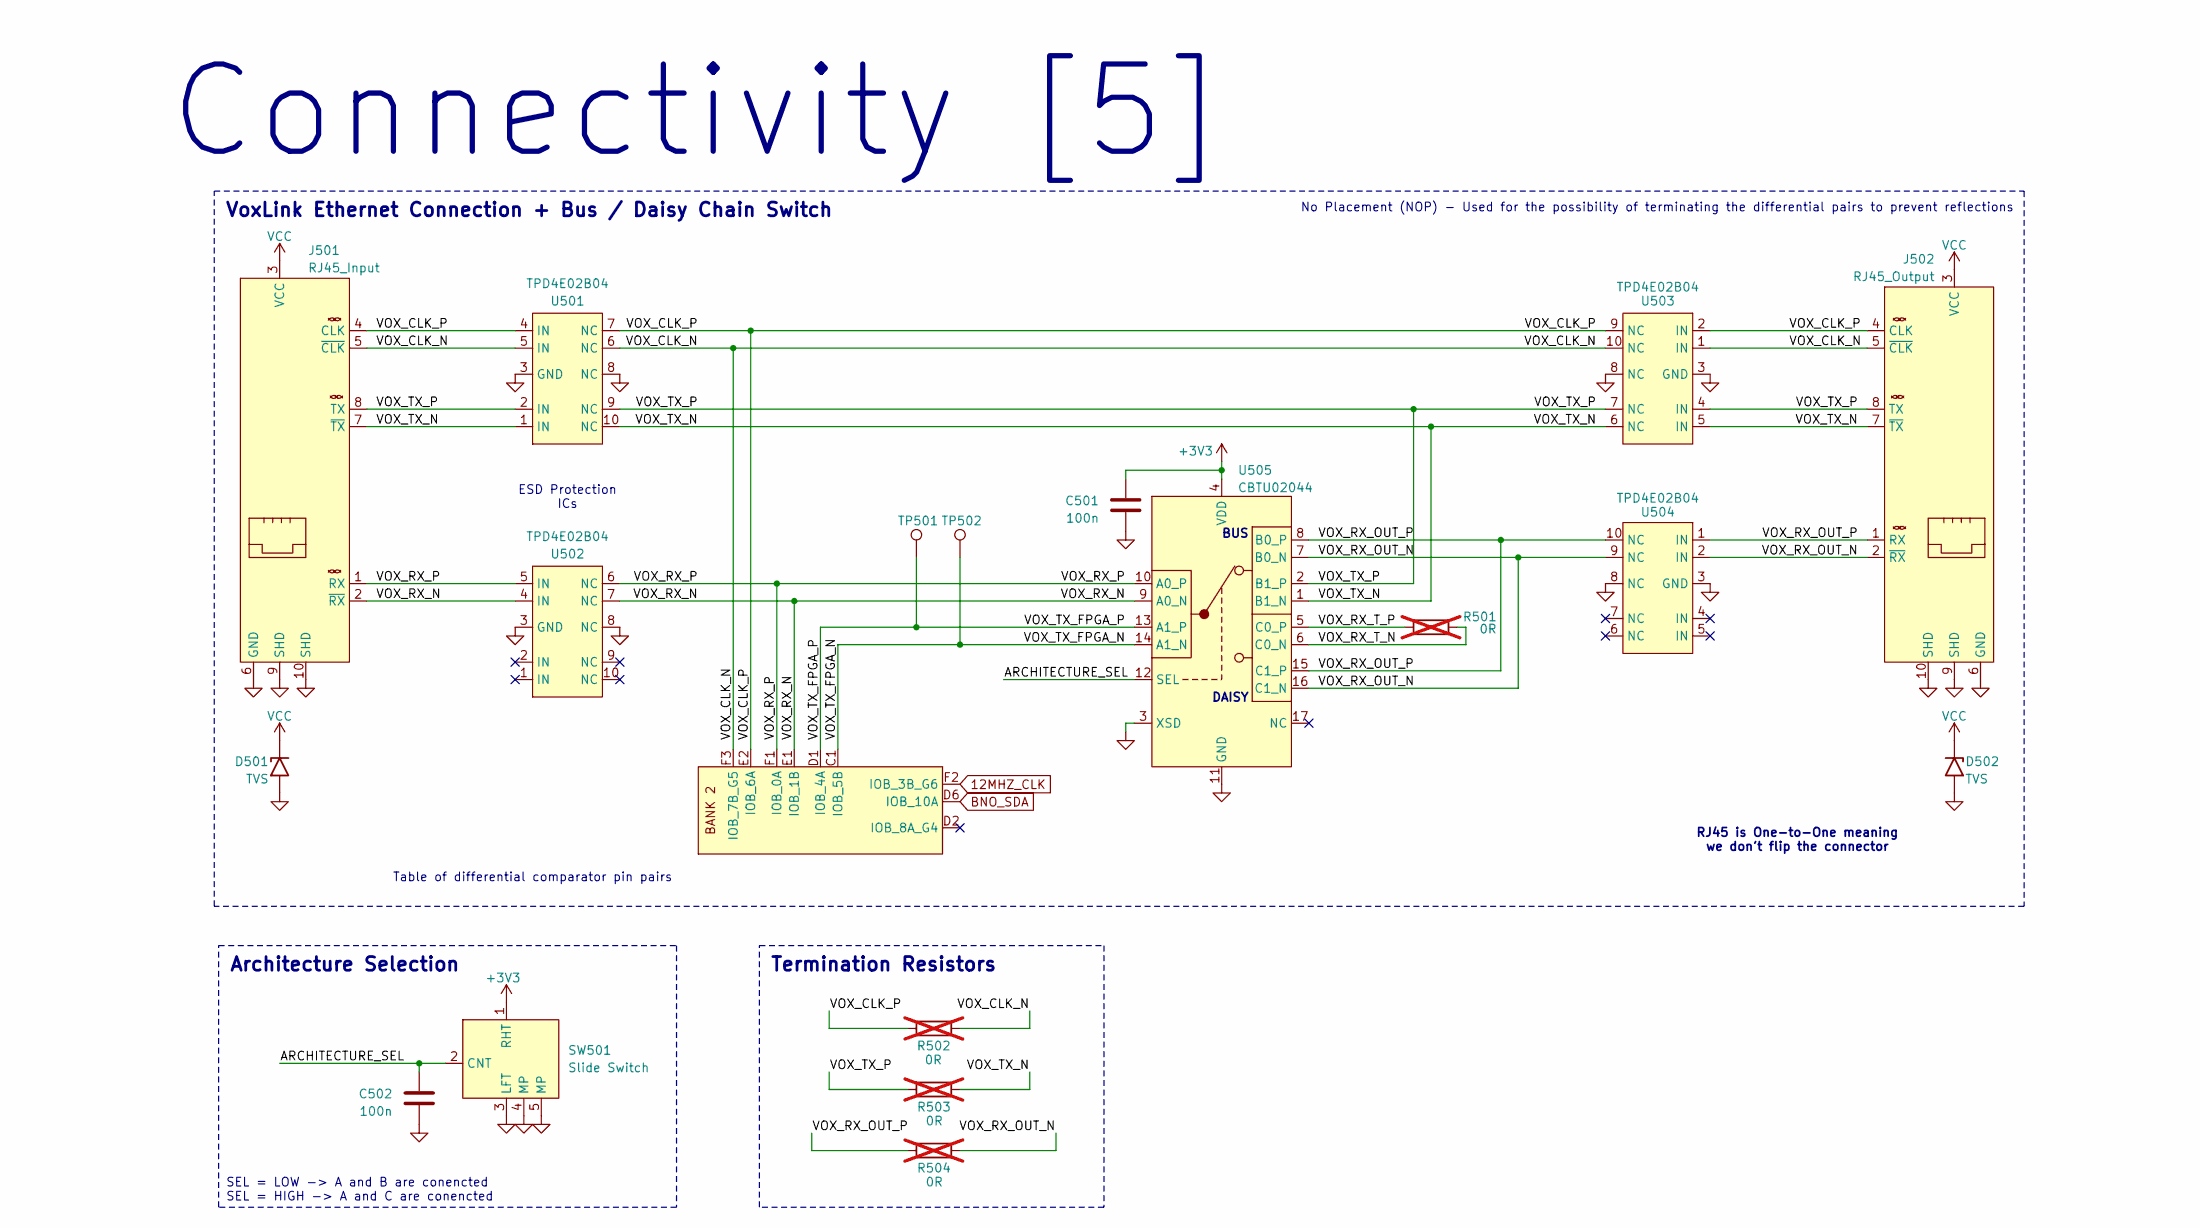
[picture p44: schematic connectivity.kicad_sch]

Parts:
C501, C502: 100n; C_0402_1005Metric
D501, D502: TVS; D_0402_1005Metric
J501: RJ45_Input; CONN_855035-101_MOL
J502: RJ45_Output; CONN_855035-101_MOL
R501, R502, R503, R504: 0R; R_0402_1005Metric; not fitted
SW501: Slide Switch; SSAJ110100_1
TP501, TP502: TestPoint; Vox_Testpoint
U301: ICE40UL1K-CM36AI; UCBGA-36_2.5x2.5mm_Layout6x6_P0.4mm
U501, U502, U503, U504: TPD4E02B04; USON-10_2.5x1.0mm_P0.5mm__Reduced_Paste
U505: CBTU02044; HUQFN-16

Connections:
12MHZ_CLK: U301.F2 (IOB_3B_G6); also elsewhere on the board
+3V3: C501.1, SW501.1 (RHT), U505.4 (VDD); also elsewhere on the board
/Connectivity/ARCHITECTURE_SEL: C502.1, SW501.2 (CNT), U505.12 (SEL)
/Connectivity/VOX_CLK_N: J501.5 (~CLK), J502.5 (~CLK), R502.2, U301.F3 (IOB_7B_G5), U501.5 (IN), U501.6 (NC), U503.1 (IN), U503.10 (NC)
/Connectivity/VOX_CLK_P: J501.4 (CLK), J502.4 (CLK), R502.1, U301.E2 (IOB_6A), U501.4 (IN), U501.7 (NC), U503.2 (IN), U503.9 (NC)
/Connectivity/VOX_RX_N: J501.2 (~RX), U301.E1 (IOB_1B), U502.4 (IN), U502.7 (NC), U505.9 (A0_N)
/Connectivity/VOX_RX_OUT_N: J502.2 (~RX), R504.1, U504.2 (IN), U504.9 (NC), U505.7 (B0_N), U505.16 (C1_N)
/Connectivity/VOX_RX_OUT_P: J502.1 (RX), R504.2, U504.1 (IN), U504.10 (NC), U505.8 (B0_P), U505.15 (C1_P)
/Connectivity/VOX_RX_P: J501.1 (RX), U301.F1 (IOB_0A), U502.5 (IN), U502.6 (NC), U505.10 (A0_P)
/Connectivity/VOX_RX_T_N: R501.2, U505.6 (C0_N)
/Connectivity/VOX_RX_T_P: R501.1, U505.5 (C0_P)
/Connectivity/VOX_TX_FPGA_N: TP502.1, U301.C1 (IOB_5B), U505.14 (A1_N)
/Connectivity/VOX_TX_FPGA_P: TP501.1, U301.D1 (IOB_4A), U505.13 (A1_P)
/Connectivity/VOX_TX_N: J501.7 (~TX), J502.7 (~TX), R503.1, U501.1 (IN), U501.10 (NC), U503.5 (IN), U503.6 (NC), U505.1 (B1_N)
/Connectivity/VOX_TX_P: J501.8 (TX), J502.8 (TX), R503.2, U501.2 (IN), U501.9 (NC), U503.4 (IN), U503.7 (NC), U505.2 (B1_P)
BNO_SDA: U301.D6 (IOB_10A); also elsewhere on the board
GND: C501.2, C502.2, D501.2 (A2), D502.2 (A2), J501.6 (GND), J501.9 (SHD), J501.10 (SHD), J502.6 (GND), J502.9 (SHD), J502.10 (SHD), SW501.3 (LFT), SW501.4 (MP), SW501.5 (MP), U501.3 (GND), U501.8 (NC), U502.3 (GND), U502.8 (NC), U503.3 (GND), U503.8 (NC), U504.3 (GND), U504.8 (NC), U505.3 (XSD), U505.11 (GND); also elsewhere on the board
VCC: D501.1 (A1), D502.1 (A1), J501.3 (VCC), J502.3 (VCC); also elsewhere on the board

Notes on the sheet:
Table of differential comparator pin pairs
ESD Protection ICs
DAISY
No Placement (NOP) - Used for the possibility of terminating the differential pairs to prevent reflections
RJ45 is One-to-One meaning we don't flip the connector
BUS
Connectivity [5]
SEL = LOW -> A and B are conencted SEL = HIGH -> A and C are conencted
Architecture Selection
Termination Resistors
VoxLink Ethernet Connection + Bus / Daisy Chain Switch

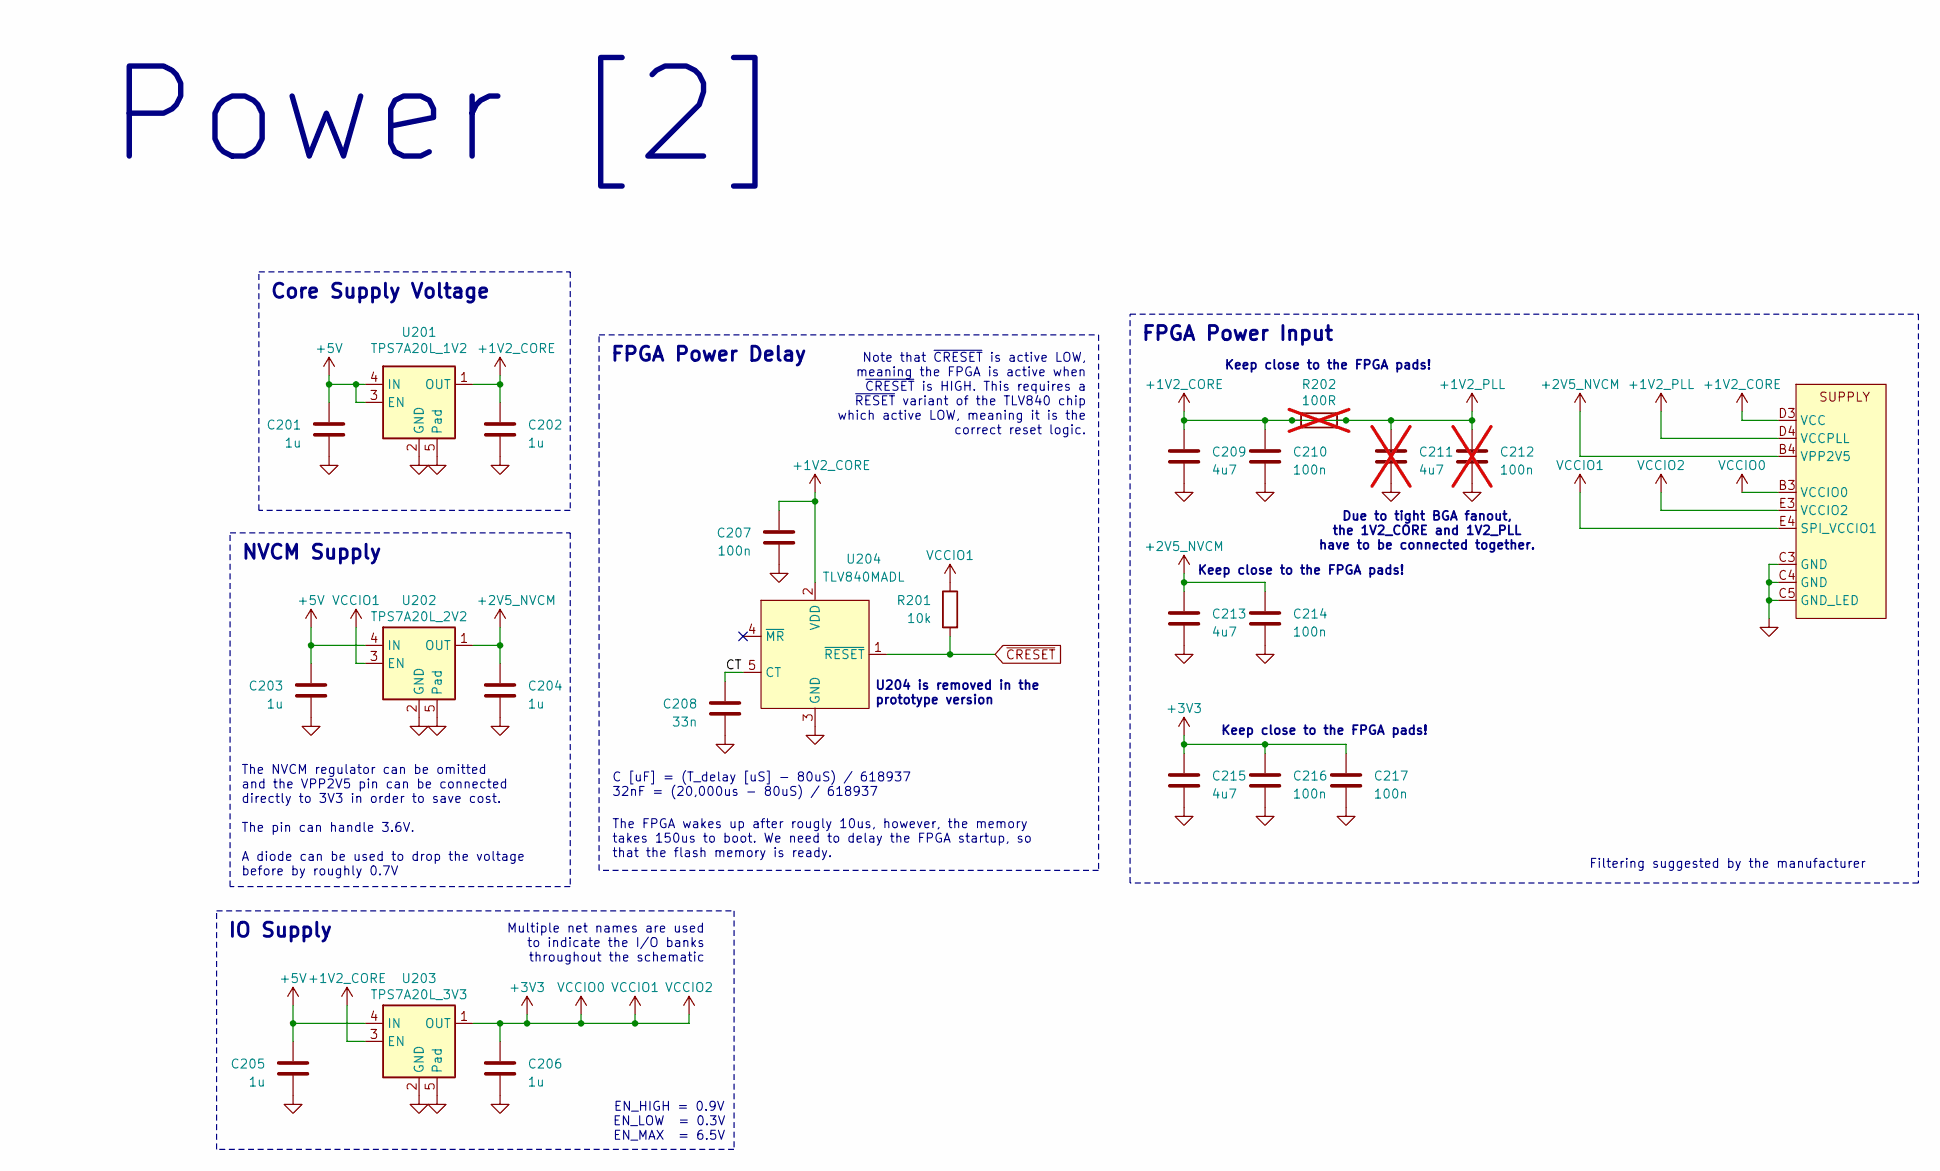
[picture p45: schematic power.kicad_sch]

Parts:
C201, C202, C203, C204, C205, C206: 1u; C_0402_1005Metric
C207, C210, C214, C216, C217: 100n; C_0402_1005Metric
C208: 33n; C_0402_1005Metric
C209, C213, C215: 4u7; C_0603_1608Metric
C211: 4u7; C_0805_2012Metric; not fitted
C212: 100n; C_0402_1005Metric; not fitted
R201: 10k; R_0402_1005Metric
R202: 100R; R_0402_1005Metric; not fitted
U201: TPS7A20L_1V2; Texas_X2SON-4_1x1mm_P0.65mm
U202: TPS7A20L_2V2; Texas_X2SON-4_1x1mm_P0.65mm
U203: TPS7A20L_3V3; Texas_X2SON-4_1x1mm_P0.65mm
U204: TLV840MADL; SOT-23-5
U301: ICE40UL1K-CM36AI; UCBGA-36_2.5x2.5mm_Layout6x6_P0.4mm

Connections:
+1V2_CORE: C202.1, C207.1, C209.1, C210.1, C211.1, C212.1, R202.1, R202.2, U201.1 (OUT), U203.3 (EN), U204.2 (VDD), U301.D3 (VCC), U301.D4 (VCCPLL)
+2V5_NVCM: C204.1, C213.1, C214.1, U202.1 (OUT), U301.B4 (VPP2V5)
+3V3: C206.1, C215.1, C216.1, C217.1, R201.1, U202.3 (EN), U203.1 (OUT), U301.B3 (VCCIO0), U301.E3 (VCCIO2), U301.E4 (SPI_VCCIO1); also elsewhere on the board
+5V: C201.1, C203.1, C205.1, U201.3 (EN), U201.4 (IN), U202.4 (IN), U203.4 (IN); also elsewhere on the board
/Power/CT: C208.1, U204.5 (CT)
GND: C201.2, C202.2, C203.2, C204.2, C205.2, C206.2, C207.2, C208.2, C209.2, C210.2, C211.2, C212.2, C213.2, C214.2, C215.2, C216.2, C217.2, U201.2 (GND), U201.5 (Pad), U202.2 (GND), U202.5 (Pad), U203.2 (GND), U203.5 (Pad), U204.3 (GND), U301.C3 (GND), U301.C4 (GND), U301.C5 (GND_LED); also elsewhere on the board
~CRESET: R201.2, U204.1 (~RESET); also elsewhere on the board

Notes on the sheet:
Power [2]
C [uF] = (T_delay [uS] - 80uS) / 618937 32nF = (20,000us - 80uS) / 618937
Note that ~{CRESET} is active LOW, meaning the FPGA is active when ~{CRESET} is HIGH. This requires a ~{RESET} variant of the TLV840 chip which active LOW, meaning it is the correct reset logic.
Keep close to the FPGA pads!
The NVCM regulator can be omitted and the VPP2V5 pin can be connected directly to 3V3 in order to save cost. The pin can handle 3.6V. A diode can be used to drop the voltage before by roughly 0.7V
The FPGA wakes up after rougly 10us, however, the memory takes 150us to boot. We need to delay the FPGA startup, so that the flash memory is ready.
Filtering suggested by the manufacturer
Multiple net names are used to indicate the I/O banks throughout the schematic
Due to tight BGA fanout, the 1V2_CORE and 1V2_PLL have to be connected together.
EN_HIGH = 0.9V EN_LOW = 0.3V EN_MAX = 6.5V
U204 is removed in the prototype version
FPGA Power Input
IO Supply
Core Supply Voltage
NVCM Supply
FPGA Power Delay

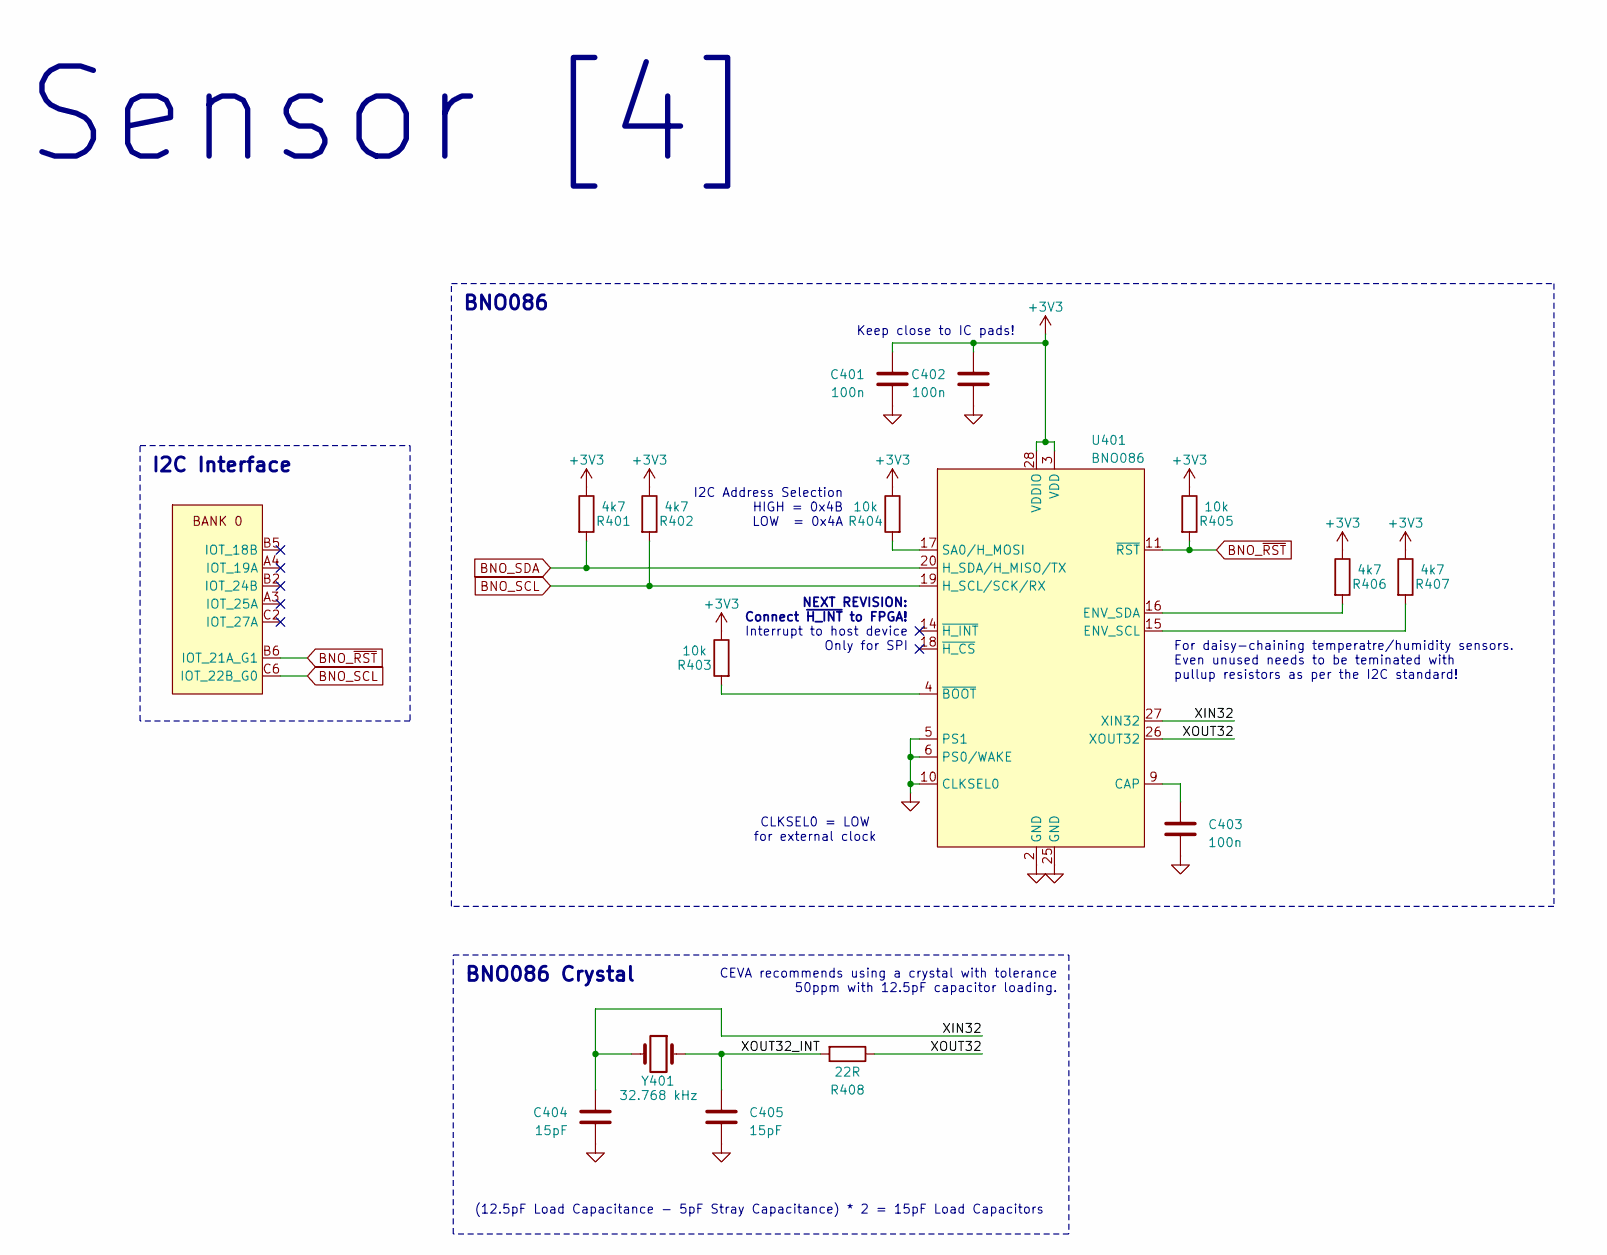
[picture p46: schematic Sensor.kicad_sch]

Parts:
C401, C402, C403: 100n; C_0402_1005Metric
C404, C405: 15pF; C_0402_1005Metric
R401, R402, R406, R407: 4k7; R_0402_1005Metric
R403, R404, R405: 10k; R_0402_1005Metric
R408: 22R; R_0402_1005Metric
U301: ICE40UL1K-CM36AI; UCBGA-36_2.5x2.5mm_Layout6x6_P0.4mm
U401: BNO086; LGA-28_5.2x3.8mm_P0.5mm
Y401: 32.768 kHz; Crystal_SMD_MicroCrystal_CC8V-T1A-2Pin_2.0x1.2mm

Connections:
+3V3: C401.1, C402.1, R401.1, R402.1, R403.1, R404.1, R405.1, R406.1, R407.1, U401.3 (VDD), U401.28 (VDDIO); also elsewhere on the board
/Sensor/XIN32: C404.1, U401.27 (XIN32), Y401.2
/Sensor/XOUT32: R408.1, U401.26 (XOUT32)
/Sensor/XOUT32_INT: C405.1, R408.2, Y401.1
BNO_SCL: R402.2, U301.C6 (IOT_22B_G0), U401.19 (H_SCL/SCK/RX)
BNO_SDA: R401.2, U401.20 (H_SDA/H_MISO/TX); also elsewhere on the board
BNO_~RST: R405.2, U301.B6 (IOT_21A_G1), U401.11 (~RST)
GND: C401.2, C402.2, C403.2, C404.2, C405.2, U401.2 (GND), U401.5 (PS1), U401.6 (PS0/WAKE), U401.10 (CLKSEL0), U401.25 (GND); also elsewhere on the board
unnamed: C403.1, U401.9 (CAP)
unnamed: R407.2, U401.15 (ENV_SCL)
unnamed: R406.2, U401.16 (ENV_SDA)
unnamed: R404.2, U401.17 (SA0/H_MOSI)
unnamed: R403.2, U401.4 (~BOOT)

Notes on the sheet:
CLKSEL0 = LOW for external clock
I2C Address Selection HIGH = 0x4B LOW = 0x4A
Keep close to IC pads!
For daisy-chaining temperatre/humidity sensors. Even unused needs to be teminated with pullup resistors as per the I2C standard!
CEVA recommends using a crystal with tolerance 50ppm with 12.5pF capacitor loading.
Sensor [4]
Interrupt to host device Only for SPI
NEXT REVISION: Connect ~{H_INT} to FPGA!
(12.5pF Load Capacitance - 5pF Stray Capacitance) * 2 = 15pF Load Capacitors
I2C Interface
BNO086 Crystal
BNO086

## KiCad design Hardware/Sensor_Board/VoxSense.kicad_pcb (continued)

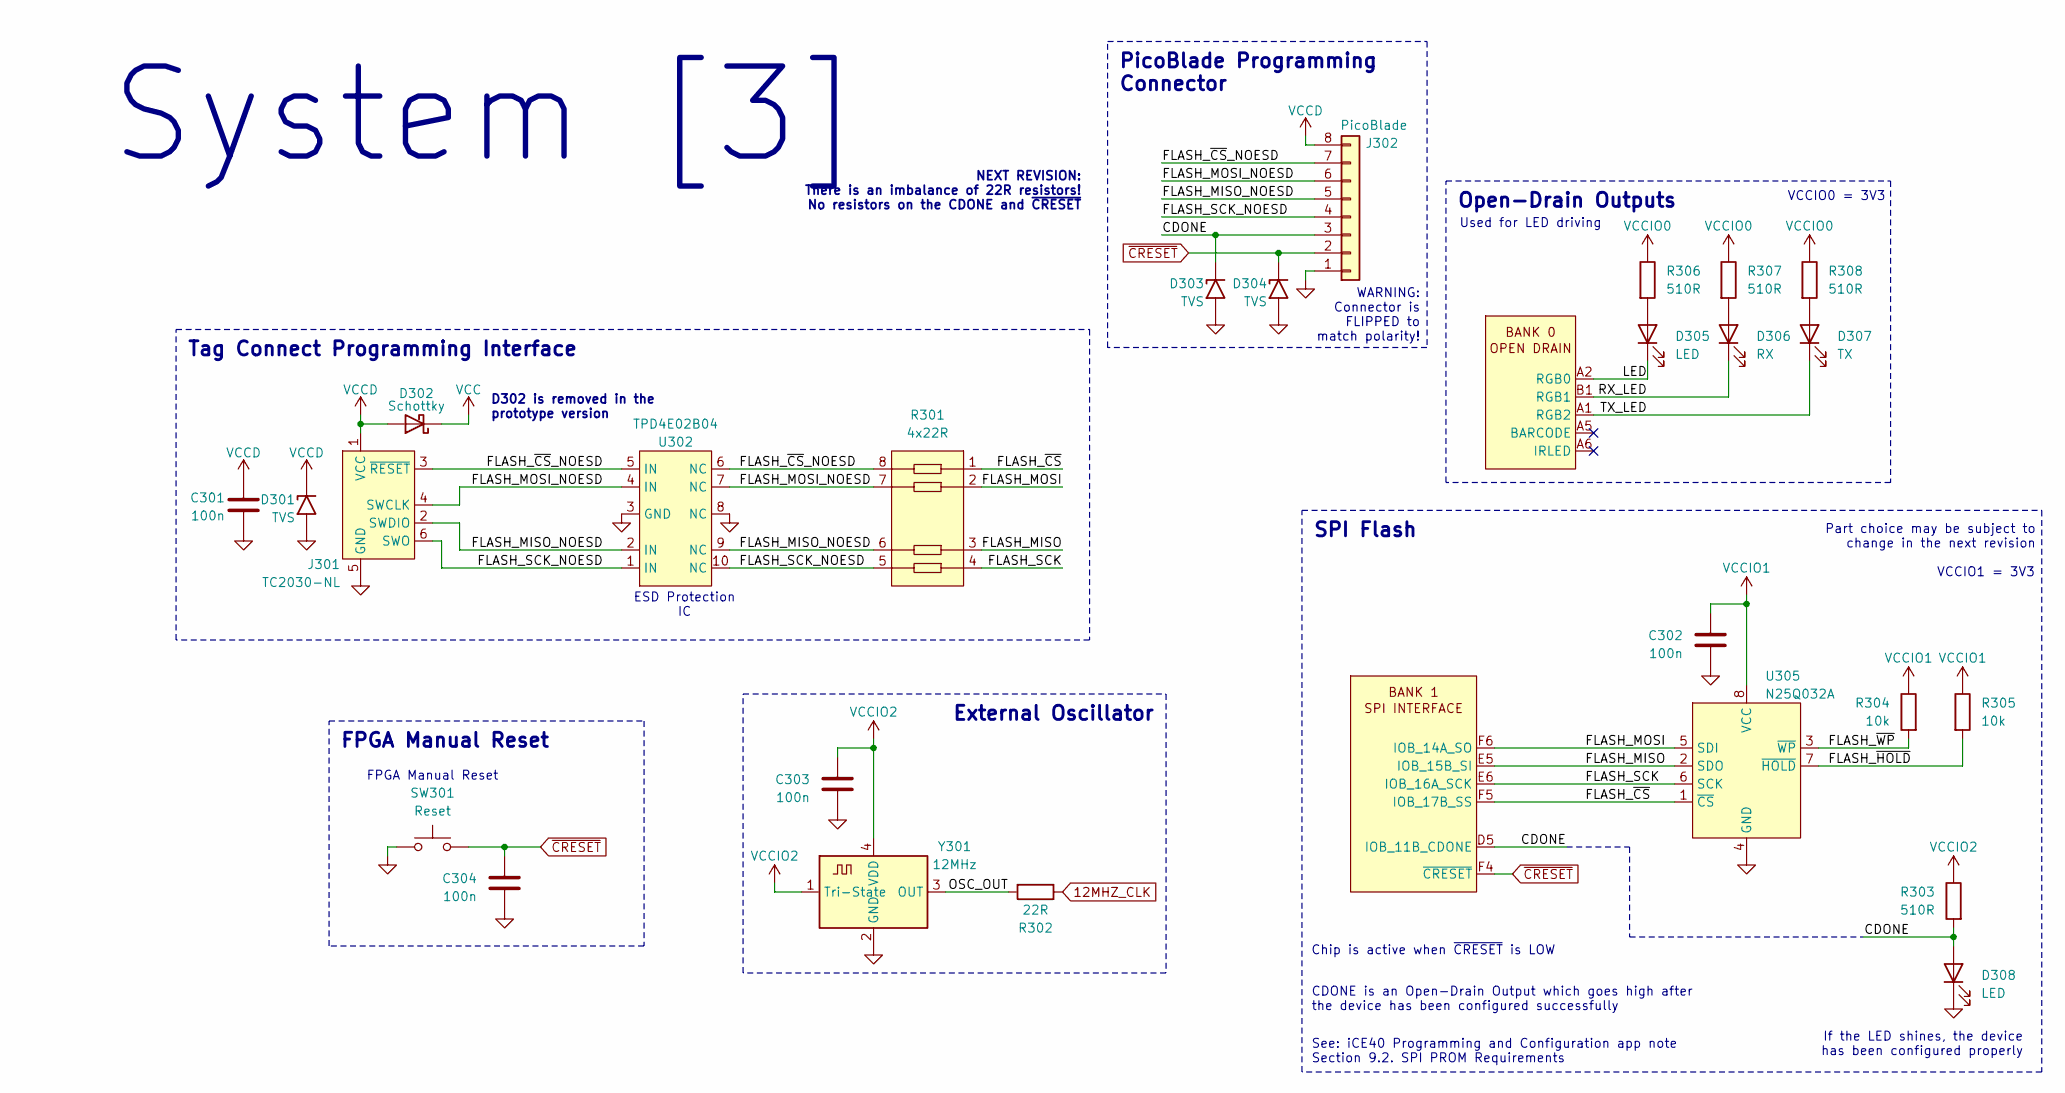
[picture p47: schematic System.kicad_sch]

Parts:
C301, C302, C303, C304: 100n; C_0402_1005Metric
D301, D303, D304: TVS; D_0402_1005Metric
D302: Schottky; D_0402_1005Metric
D305, D308: LED; LED_0603_1608Metric
D306: RX; LED_0603_1608Metric
D307: TX; LED_0603_1608Metric
J301: TC2030-NL; Tag-Connect_TC2030-IDC-NL_2x03_P1.27mm_Vertical
J302: PicoBlade; Molex_PicoBlade_53048-0810_1x08_P1.25mm_Horizontal
R301: 4x22R; EXBN8V101JX
R302: 22R; R_0402_1005Metric
R303, R306, R307, R308: 510R; R_0402_1005Metric
R304, R305: 10k; R_0402_1005Metric
SW301: Reset; SW_Push_SPST_NO_Alps_SKRK
U301: ICE40UL1K-CM36AI; UCBGA-36_2.5x2.5mm_Layout6x6_P0.4mm
U302: TPD4E02B04; USON-10_2.5x1.0mm_P0.5mm__Reduced_Paste
U305: N25Q032A; U-PDFN-8
Y301: 12MHz; Oscillator_SMD_Abracon_ASCO-4Pin_1.6x1.2mm

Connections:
12MHZ_CLK: R302.1; also elsewhere on the board
+3V3: C302.1, C303.1, R303.1, R304.1, R305.1, R306.1, R307.1, R308.1, U305.8 (VCC), Y301.1 (Tri-State), Y301.4 (VDD); also elsewhere on the board
/System/CDONE: D303.1 (A1), D308.2 (A), J302.3, R303.2, U301.D5 (IOB_11B_CDONE)
/System/FLASH_MISO: R301.3, U301.E5 (IOB_15B_SI), U305.2 (SDO)
/System/FLASH_MISO_NOESD: J301.2 (SWDIO), J302.5, R301.6, U302.2 (IN), U302.9 (NC)
/System/FLASH_MOSI: R301.2, U301.F6 (IOB_14A_SO), U305.5 (SDI)
/System/FLASH_MOSI_NOESD: J301.4 (SWCLK), J302.6, R301.7, U302.4 (IN), U302.7 (NC)
/System/FLASH_SCK: R301.4, U301.E6 (IOB_16A_SCK), U305.6 (SCK)
/System/FLASH_SCK_NOESD: J301.6 (SWO), J302.4, R301.5, U302.1 (IN), U302.10 (NC)
/System/FLASH_~CS: R301.1, U301.F5 (IOB_17B_SS), U305.1 (~CS)
/System/FLASH_~CS_NOESD: J301.3 (~RESET), J302.7, R301.8, U302.5 (IN), U302.6 (NC)
/System/FLASH_~HOLD: R305.2, U305.7 (~HOLD)
/System/FLASH_~WP: R304.2, U305.3 (~WP)
/System/LED: D305.1 (K), U301.A2 (RGB0)
/System/OSC_OUT: R302.2, Y301.3 (OUT)
/System/RX_LED: D306.1 (K), U301.B1 (RGB1)
/System/TX_LED: D307.1 (K), U301.A1 (RGB2)
GND: C301.2, C302.2, C303.2, C304.2, D301.2 (A2), D303.2 (A2), D304.2 (A2), D308.1 (K), J301.5 (GND), J302.1, SW301.2, U302.3 (GND), U302.8 (NC), U305.4 (GND), Y301.2 (GND); also elsewhere on the board
unnamed: D305.2 (A), R306.2
unnamed: D306.2 (A), R307.2
unnamed: D307.2 (A), R308.2
VCC: D302.1 (K); also elsewhere on the board
VCCD: C301.1, D301.1 (A1), D302.2 (A), J301.1 (VCC), J302.8
~CRESET: C304.1, D304.1 (A1), J302.2, SW301.1, U301.F4 (~CRESET); also elsewhere on the board

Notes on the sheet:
D302 is removed in the prototype version
Used for LED driving
Part choice may be subject to change in the next revision
If the LED shines, the device has been configured properly
See: iCE40 Programming and Configuration app note Section 9.2. SPI PROM Requirements
VCCIO1 = 3V3
CDONE is an Open-Drain Output which goes high after the device has been configured successfully
NEXT REVISION: There is an imbalance of 22R resistors! No resistors on the CDONE and ~{CRESET}
System [3]
FPGA Manual Reset
Chip is active when ~{CRESET} is LOW
VCCIO0 = 3V3
WARNING: Connector is FLIPPED to match polarity!
ESD Protection IC
Open-Drain Outputs
SPI Flash
External Oscillator
Tag Connect Programming Interface
PicoBlade Programming Connector

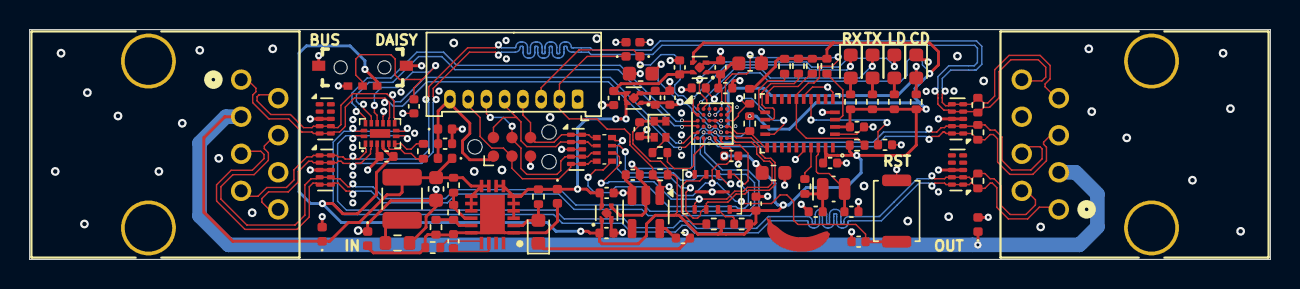
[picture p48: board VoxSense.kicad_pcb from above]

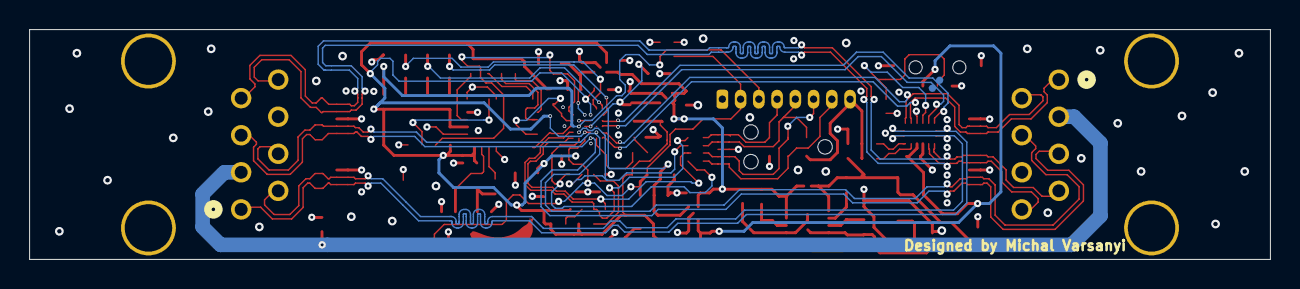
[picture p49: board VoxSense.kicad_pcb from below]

Board: 4 copper layers, 85.0 x 15.7 mm, 93 parts (2 on the bottom side), 59 nets.

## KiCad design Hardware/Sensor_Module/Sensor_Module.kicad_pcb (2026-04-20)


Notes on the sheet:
Technical Sheet Only! Please refer to the subsequent sheets for schematic
Root [0]


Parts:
D2, D3, D4, D5, D6, D7, D8, D9, D10, D11, D12, D13: TVS; WLL-2-3; LCSC C2939949
J1: Connector_Left; 7-Pin_Casselated_Edge
J2: Connector_Right; 7-Pin_Casselated_Edge

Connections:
+3V3: D11.2 (A2), J2.2; also elsewhere on the board
+5V: D2.2 (A2), J1.6; also elsewhere on the board
BNO_ADDR: D10.2 (A2), J2.3; also elsewhere on the board
BNO_SCL: D3.2 (A2), J1.5; also elsewhere on the board
BNO_SDA: D4.2 (A2), J1.4; also elsewhere on the board
BNO_~RST: D5.2 (A2), J1.3; also elsewhere on the board
ENV_SCL: D9.2 (A2), J2.4; also elsewhere on the board
ENV_SDA: D8.2 (A2), J2.5; also elsewhere on the board
GND: D2.1 (A1), D3.1 (A1), D4.1 (A1), D5.1 (A1), D6.1 (A1), D7.1 (A1), D8.1 (A1), D9.1 (A1), D10.1 (A1), D11.1 (A1), D12.1 (A1), D13.1 (A1), J1.7, J2.1; also elsewhere on the board
NC1: D13.2 (A2), J2.6
NC2: D12.2 (A2), J2.7
~H_CS: D7.2 (A2), J1.1; also elsewhere on the board
~H_INT: D6.2 (A2), J1.2; also elsewhere on the board

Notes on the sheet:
Connectivity [2]
ESD Protection
Edge Connectors


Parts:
C1, C2, C5: 100n; C_0402_1005Metric; LCSC C77020
C3, C4: 4.7u; C_0402_1005Metric; LCSC C2858031
C6, C7: 15pF; C_0402_1005Metric; LCSC C2169087
D1: LED; LED_0402_1005Metric; LCSC C7466700
R1, R2, R5, R6: 4k7; R_0402_1005Metric; LCSC C482193
R3, R4, R8: 10k; R_0402_1005Metric; LCSC C71617
R7: 510R; R_0402_1005Metric; LCSC C482201
R9: 22R; R_0402_1005Metric; LCSC C482106
U1: BNO086; LGA-28_5.2x3.8mm_P0.5mm; LCSC C5264422
U2: TPS7A20L_3V3; Texas_X2SON-4_1x1mm_P0.65mm; LCSC C22445532
Y1: 32.768 kHz; Crystal_SMD_MicroCrystal_CM9V-T1A-2Pin_1.6x1.0mm; LCSC C5154201

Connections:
+3V3: C1.1, C2.1, C4.1, R1.1, R2.1, R3.1, R4.1, R5.1, R6.1, R7.1, R8.1, U1.3 (VDD), U1.28 (VDDIO), U2.1 (OUT); also elsewhere on the board
+5V: C3.1, U2.3 (EN), U2.4 (IN); also elsewhere on the board
/Sensor/XIN32: C6.1, U1.27 (XIN32), Y1.2
/Sensor/XOUT32: R9.1, U1.26 (XOUT32)
/Sensor/XOUT32_INT: C7.1, R9.2, Y1.1
BNO_ADDR: R3.2, U1.17 (SA0/H_MOSI); also elsewhere on the board
BNO_SCL: R2.2, U1.19 (H_SCL/SCK/RX); also elsewhere on the board
BNO_SDA: R1.2, U1.20 (H_SDA/H_MISO/TX); also elsewhere on the board
BNO_~RST: R4.2, U1.11 (~RST); also elsewhere on the board
ENV_SCL: R6.2, U1.15 (ENV_SCL); also elsewhere on the board
ENV_SDA: R5.2, U1.16 (ENV_SDA); also elsewhere on the board
GND: C1.2, C2.2, C3.2, C4.2, C5.2, C6.2, C7.2, D1.1 (K), U1.2 (GND), U1.5 (PS1), U1.6 (PS0/WAKE), U1.10 (CLKSEL0), U1.25 (GND), U2.2 (GND), U2.5 (Pad); also elsewhere on the board
unnamed: D1.2 (A), R7.2
unnamed: C5.1, U1.9 (CAP)
unnamed: R8.2, U1.4 (~BOOT)
~H_CS: U1.18 (~H_CS); also elsewhere on the board
~H_INT: U1.14 (~H_INT); also elsewhere on the board

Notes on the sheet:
CEVA recommends using a crystal with tolerance 50ppm with 12.5pF capacitor loading.
Sensor [1]
For daisy-chaining temperatre/humidity sensors. Even unused needs to be teminated with pullup resistors as per the I2C standard!
(12.5pF Load Capacitance - 5pF Stray Capacitance) * 2 = 15pF Load Capacitors
I2C Address Selection HIGH = 0x4B LOW = 0x4A
CLKSEL0 = LOW for external clock
Keep close to IC pads!
BNO086 Crystal
BNO086
IO Supply


Board: 4 copper layers, 13.0 x 13.0 mm, 34 parts (0 on the bottom side), 19 nets.

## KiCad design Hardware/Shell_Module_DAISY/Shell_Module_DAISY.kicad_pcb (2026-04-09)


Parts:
C1: 10u; C_1206_3216Metric
C304: 1u; C_0805_2012Metric
H1, H2: M3; MountingHole_3.2mm_M3_DIN965
J1: PicoBlade; Molex_PicoBlade_53048-0810_1x08_P1.25mm_Horizontal
J2: RJ45_Output; CONN_855035-101_MOL
R1: 1R; R_0603_1608Metric
R2: 10k; R_0603_1608Metric
SW301: Reset; SW_TH_Tactile_Omron_B3F-102x
U1: VoxLink_Core_Module
U2: VoxLink_BNO086_Module

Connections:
+3.3V: R2.1, U2.9 (+3V3)
+5V: C1.1, J1.5, J2.3 (VCC), U1.26 (5V), U2.2 (5V)
/BNO_NINT: U1.20 (IOB_1B), U2.6 (H_NINT)
/BNO_NRST: U1.21 (IOT_18B), U2.5 (BNO_NRST)
/BNO_SCL: U1.23 (IOT_5B), U2.3 (BNO_SCL)
/BNO_SDA: U1.22 (IOT_4A), U2.4 (BNO_SDA)
/IN_CLK_N: J1.1, U1.12 (IOT_24B)
/IN_CLK_P: J1.2, U1.13 (IOT_21A_G1)
/IN_RX_N: J1.8, U1.7 (IOT_25A)
/IN_RX_P: J1.7, U1.8 (IOT_19A)
/NRESET: C304.1, R2.2, SW301.1, U1.1 (NRESET)
/OUT_CLK_N: J2.5 (~CLK), U1.15 (IO_10A)
/OUT_CLK_P: J2.4 (CLK), U1.14 (IOT_22B_G0)
/OUT_RX_N: J2.2 (~RX), U1.18 (IOB_3B_G6)
/OUT_RX_P: J2.1 (RX), U1.17 (IOB_7B_G5)
/TX_N: J1.3, J2.7 (~TX)
/TX_P: J1.4, J2.8 (TX)
GND: C304.2, J1.6, J2.6 (GND), J2.9 (SHD), J2.10 (SHD), R1.2, SW301.2, U1.27 (GND), U2.1 (GND), U2.8 (GND)
unnamed: C1.2, R1.1

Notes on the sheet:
OUTPUT
INPUT
FPGA Manual Reset
Shell Module Daisy
VoxLink color coding with the BotBlox 8-way cable
Connector is Facing Left
Lattice Core Module
Mounting Holes
BNO086 Sensor Module
VoxLink Connectors



Board: 4 copper layers, 54.0 x 29.5 mm, 11 parts (5 on the bottom side), 19 nets.

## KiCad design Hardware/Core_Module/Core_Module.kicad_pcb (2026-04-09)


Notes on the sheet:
Technical Sheet Only! Please refer to the subsequent sheets for schematic
Root [0]


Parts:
C101, C103, C107, C112, C113, C116: 100n; C_0201_0603Metric; LCSC C668346
C104, C105, C108, C109, C114, C115: 1u; C_0201_0603Metric; LCSC C335102
C110: 2.2u; C_0201_0603Metric; LCSC C335106
D101: LED; LED_0201_0603Metric; LCSC C5846955
D102: LED; LED_0201_0603Metric; LCSC C4153580
R101: 22R; R_0201_0603Metric; LCSC C3009113
R103, R106: 499R; R_0201_0603Metric; LCSC C2094902
R104, R105: 10k; R_0201_0603Metric; LCSC C844303
U101: TPS7A20L_1V2; Texas_X2SON-4_1x1mm_P0.65mm; LCSC C30875939
U102: ICE40UL1K-CM36AI; UCBGA-36_2.5x2.5mm_Layout6x6_P0.4mm; LCSC C1519040
U103: TPS7A20L_2V5; Texas_X2SON-4_1x1mm_P0.65mm; LCSC C41487851
U104: TPS7A20L_3V3; Texas_X2SON-4_1x1mm_P0.65mm; LCSC C22445532
U105: W25Q32JV; U-PDFN-8; LCSC C2999380
Y101: 12MHz; Oscillator_SMD_Abracon_ASCO-4Pin_1.6x1.2mm; LCSC SMD1612-4P

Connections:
12MHZ_CLK: R101.1, U102.D2 (IOB_8A_G4)
+1V2_CORE: C103.1, C105.1, U101.1 (OUT), U102.D3 (VCC), U102.D4 (VCCPLL), U104.3 (EN)
+2V5_NVCM: C107.1, C109.1, U102.B4 (VPP2V5), U103.1 (OUT)
+3V3: C101.1, C112.1, C113.1, C115.1, C116.1, R103.1, R104.1, R105.1, R106.1, U102.B3 (VCCIO0), U102.E3 (VCCIO2), U102.E4 (SPI_VCCIO1), U103.3 (EN), U104.1 (OUT), U105.8 (VCC), Y101.1 (Tri-State), Y101.4 (VDD)
+5V: C104.1, C108.1, C110.1, C114.1, U101.3 (EN), U101.4 (IN), U103.4 (IN), U104.4 (IN); also elsewhere on the board
/FPGA/FLASH_~HOLD: R105.2, U105.7 (~HOLD)
/FPGA/FLASH_~WP: R104.2, U105.3 (~WP)
/FPGA/LED: D101.1 (K), U102.A2 (RGB0)
/FPGA/OSC_OUT: R101.2, Y101.3 (OUT)
BARCODE: U102.A5 (BARCODE); also elsewhere on the board
CDONE: D102.2 (A), R106.2, U102.D5 (IOB_11B_CDONE); also elsewhere on the board
FLASH_MISO: U102.E5 (IOB_15B_SI), U105.2 (SDO); also elsewhere on the board
FLASH_MOSI: U102.F6 (IOB_14A_SO), U105.5 (SDI); also elsewhere on the board
FLASH_SCK: U102.E6 (IOB_16A_SCK), U105.6 (SCK); also elsewhere on the board
FLASH_~CS: U102.F5 (IOB_17B_SS), U105.1 (~CS); also elsewhere on the board
GND: C101.2, C103.2, C104.2, C105.2, C107.2, C108.2, C109.2, C110.2, C112.2, C113.2, C114.2, C115.2, C116.2, D102.1 (K), U101.2 (GND), U101.5 (Pad), U102.C3 (GND), U102.C4 (GND), U102.C5 (GND_LED), U103.2 (GND), U103.5 (Pad), U104.2 (GND), U104.5 (Pad), U105.4 (GND), Y101.2 (GND); also elsewhere on the board
IOB_0A: U102.F1 (IOB_0A); also elsewhere on the board
IOB_1B: U102.E1 (IOB_1B); also elsewhere on the board
IOB_3B_G6: U102.F2 (IOB_3B_G6); also elsewhere on the board
IOB_4A: U102.D1 (IOB_4A); also elsewhere on the board
IOB_5B: U102.C1 (IOB_5B); also elsewhere on the board
IOB_6A: U102.E2 (IOB_6A); also elsewhere on the board
IOB_7B_G5: U102.F3 (IOB_7B_G5); also elsewhere on the board
IOB_10A: U102.D6 (IOB_10A); also elsewhere on the board
IOT_18B: U102.B5 (IOT_18B); also elsewhere on the board
IOT_19A: U102.A4 (IOT_19A); also elsewhere on the board
IOT_21A_G1: U102.B6 (IOT_21A_G1); also elsewhere on the board
IOT_22B_G0: U102.C6 (IOT_22B_G0); also elsewhere on the board
IOT_24B: U102.B2 (IOT_24B); also elsewhere on the board
IOT_25A: U102.A3 (IOT_25A); also elsewhere on the board
IOT_27A: U102.C2 (IOT_27A); also elsewhere on the board
IRLED: U102.A6 (IRLED); also elsewhere on the board
unnamed: D101.2 (A), R103.2
RGB1: U102.B1 (RGB1); also elsewhere on the board
RGB2: U102.A1 (RGB2); also elsewhere on the board
~CRESET: U102.F4 (~CRESET); also elsewhere on the board

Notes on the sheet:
If the LED shines, the device has been configured properly
Filtering suggested by the manufacturer
Multiple net names are used to indicate the I/O banks throughout the schematic
FPGA [1]
Keep close to the FPGA pads!
EN_HIGH = 0.9V EN_LOW = 0.3V EN_MAX = 6.5V
No room for larger bulk capacitors
INCLUDE A PULLUP ON ~{CRESET} IN NEXT REVISION!
VCCIO0 = 3V3
CDONE is an Open-Drain Output which goes high after the device has been configured successfully
Used for LED driving
The NVCM regulator can be omitted and the VPP2V5 pin can be connected directly to 3V3 in order to save cost. The pin can handle 3.6V. A diode can be used to drop the voltage before by roughly 0.7V
VCCIO1 = 3V3
Part choice may be subject to change in the next revision
See: iCE40 Programming and Configuration app note Section 9.2. SPI PROM Requirements
Chip is active when ~{CRESET} is LOW
IO Supply
FPGA Power Input
Bank 0 I/O
NVCM Supply
Core Supply Voltage
Bank 2 I/O
Open-Drain Outputs
External Oscillator
SPI Flash
Input Bulk

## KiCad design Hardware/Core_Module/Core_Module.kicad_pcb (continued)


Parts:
D201, D202, D203, D204, D205, D206, D207, D209, D210, D211, D212, D213, D214, D215, D216, D217, D218, D219, D220, D221, D222, D223, D224, D225, D226: TVS; WLL-2-3; LCSC C2939949
D208: TSV; WLL-2-3; LCSC C2939949
J201: Connector_Left; 7-Pin_Casselated_Edge
J202: Connector_Bottom; 7-Pin_Casselated_Edge
J203: Connector_Right; 7-Pin_Casselated_Edge
J205: Connector_Top; 6-Pin_Casselated_Edge

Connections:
+5V: D215.2 (A2), J201.6; also elsewhere on the board
BARCODE: D218.2 (A2), J203.3; also elsewhere on the board
CDONE: D221.2 (A2), J205.5; also elsewhere on the board
FLASH_MISO: D223.2 (A2), J205.2; also elsewhere on the board
FLASH_MOSI: D225.2 (A2), J205.4; also elsewhere on the board
FLASH_SCK: D224.2 (A2), J205.3; also elsewhere on the board
FLASH_~CS: D222.2 (A2), J205.1; also elsewhere on the board
GND: D201.1 (A1), D202.1 (A1), D203.1 (A1), D204.1 (A1), D205.1 (A1), D206.1 (A1), D207.1 (A1), D208.1 (A1), D209.1 (A1), D210.1 (A1), D211.1 (A1), D212.1 (A1), D213.1 (A1), D214.1 (A1), D215.1 (A1), D216.1 (A1), D217.1 (A1), D218.1 (A1), D219.1 (A1), D220.1 (A1), D221.1 (A1), D222.1 (A1), D223.1 (A1), D224.1 (A1), D225.1 (A1), D226.1 (A1), J201.7; also elsewhere on the board
IOB_0A: D210.2 (A2), J202.6; also elsewhere on the board
IOB_1B: D209.2 (A2), J202.7; also elsewhere on the board
IOB_3B_G6: D208.2 (A2), J202.5; also elsewhere on the board
IOB_4A: D214.2 (A2), J201.2; also elsewhere on the board
IOB_5B: D213.2 (A2), J201.3; also elsewhere on the board
IOB_6A: D206.2 (A2), J202.3; also elsewhere on the board
IOB_7B_G5: D207.2 (A2), J202.4; also elsewhere on the board
IOB_10A: D205.2 (A2), J202.2; also elsewhere on the board
IOT_18B: D220.2 (A2), J201.1; also elsewhere on the board
IOT_19A: D217.2 (A2), J203.2; also elsewhere on the board
IOT_21A_G1: D203.2 (A2), J203.7; also elsewhere on the board
IOT_22B_G0: D204.2 (A2), J202.1; also elsewhere on the board
IOT_24B: D202.2 (A2), J203.6; also elsewhere on the board
IOT_25A: D216.2 (A2), J203.1; also elsewhere on the board
IOT_27A: D201.2 (A2), J203.5; also elsewhere on the board
IRLED: D219.2 (A2), J203.4; also elsewhere on the board
RGB1: D212.2 (A2), J201.4; also elsewhere on the board
RGB2: D211.2 (A2), J201.5; also elsewhere on the board
~CRESET: D226.2 (A2), J205.6; also elsewhere on the board

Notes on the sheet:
Connectivity [2]
ESD Protection
Edge Connectors


Board: 6 copper layers, 13.0 x 13.0 mm, 56 parts (0 on the bottom side), 36 nets.

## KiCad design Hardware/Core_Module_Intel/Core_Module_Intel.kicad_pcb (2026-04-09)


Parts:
C104, C105, C108, C109: 1u; C_0402_1005Metric
C110, C111, C112, C113, C116, C117: 100n; C_0402_1005Metric
D101, D102: LED; LED_0201_0603Metric
J201: Connector_Left; 7-Pin_Casselated_Edge
J202: Connector_Bottom; 7-Pin_Casselated_Edge
J203: Connector_Right; 7-Pin_Casselated_Edge
J205: Connector_Top; 6-Pin_Casselated_Edge
R2, R3, R4, R5: 10k; R_0402_1005Metric
R6, R7: 100R; R_0402_1005Metric
R103, R106: 510R; R_0201_0603Metric
U1: 10M02DCV36C8G
U101: TPS7A20L_1V2; Texas_X2SON-4_1x1mm_P0.65mm
U103: TPS7A20L_2V5; Texas_X2SON-4_1x1mm_P0.65mm

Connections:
+1V2_CORE: C105.1, C110.1, C111.1, U1.B1 (VCC), U1.F5 (VCC), U101.1 (OUT)
+2V5: C109.1, C112.1, C113.1, C116.1, C117.1, R2.1, R3.1, R4.1, R5.1, R106.1, U1.A1 (VCCA3), U1.A6 (VCCA2), U1.C4 (VCCIO_1_2_8), U1.D4 (VCCIO_3_5_6), U103.1 (OUT)
+5V: C104.1, C108.1, J201.6, U101.3 (EN), U101.4 (IN), U103.4 (IN)
/IN_CLK_N: J202.5, R6.2, U1.E6 (DIFFOUT_R10n)
/IN_CLK_P: J202.4, R6.1, U1.D6 (DIFFOUT_R10p)
/IN_DATA_N: J201.3, R7.2, U1.C6 (DIFFOUT_R12n)
/IN_DATA_P: J201.2, R7.1, U1.D5 (DIFFOUT_R12p)
/LED: R103.1
/NRST: U1.A5 (DEV_CLRN)
/OUT_CLK_N: J202.2, U1.F2 (DIFFOUT_B1n)
/OUT_CLK_P: J202.1, U1.F3 (DIFFOUT_B1p)
/OUT_DATA_N: J202.7, U1.E3 (DIFFOUT_B7n)
/OUT_DATA_P: J202.6, U1.F4 (DIFFOUT_B7p)
CDONE: J205.5
GND: C104.2, C105.2, C108.2, C109.2, C110.2, C111.2, C112.2, C113.2, C116.2, C117.2, D101.1 (K), D102.1 (K), J201.1, J201.7, J202.3, U1.B3 (GND), U1.F1 (GND), U1.F6 (GND), U101.2 (GND), U101.5 (Pad), U103.2 (GND), U103.5 (Pad)
unnamed: D101.2 (A), R103.2
unnamed: D102.2 (A), R106.2
unnamed: R3.2, U1.A2 (CONFIG_DONE)
unnamed: R2.2, U1.C2 (JTAGEN)
unnamed: R4.2, U1.A4 (NCONFIG)
unnamed: R5.2, U1.B2 (NSTATUS)
TCK: J205.3, U1.D3 (TCK)
TDI: J205.4, U1.C1 (TDI)
TDO: J205.2, U1.D2 (TDO)
TMS: J205.1, U1.C3 (TMS)
VCCIO1: U103.3 (EN)
~CRESET: J205.6

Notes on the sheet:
Input from transmit of the master
Output to receive of the master
Core Supply Voltage
NVCM Supply
Edge Connectors

Board: 6 copper layers, 27 parts (0 on the bottom side), 22 nets, no tracks yet.

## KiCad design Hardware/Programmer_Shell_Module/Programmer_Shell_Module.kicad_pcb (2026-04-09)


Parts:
C1: 1u; C_0603_1608Metric
C2: 10u; C_1206_3216Metric
H801, H802, H803, H804: M3; MountingHole_3.2mm_M3_Pad_Via
J2: RJ45_Output; CONN_855035-101_MOL
R1: 10k; R_0603_1608Metric
R2: 20k; R_0603_1608Metric
R3: 1R; R_0603_1608Metric
U1: VoxLink_Core_Module

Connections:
+5V: C2.1, J2.5 (~CLK), R1.1, U1.26 (5V)
/DONE: J2.6 (GND), U1.2 (DONE)
/FLASH_MISO: J2.8 (TX), U1.5 (FLASH_MISO)
/FLASH_MOSI: J2.7 (~TX), U1.3 (FLASH_MOSI)
/FLASH_NCS: J2.4 (CLK), U1.6 (FLASH_NSC)
/FLASH_SCK: J2.3 (VCC), U1.4 (FLASH_SCK)
/NRESET: C1.1, J2.1 (RX), R1.2, R2.1, U1.1 (NRESET)
GND: C1.2, H801.1 (1_1), H802.1 (1_1), H803.1 (1_1), H804.1 (1_1), J2.2 (~RX), J2.9 (SHD), J2.10 (SHD), R2.2, R3.2, U1.27 (GND)
unnamed: C2.2, R3.1

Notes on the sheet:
Programmer color coding conversion to VoxLink with the BotBlox 8-way cable
VoxLink Programmer Shell
M3 Mounting Holes
Lattice Core Module


Board: 4 copper layers, 70.0 x 70.0 mm, 11 parts (0 on the bottom side), 9 nets.

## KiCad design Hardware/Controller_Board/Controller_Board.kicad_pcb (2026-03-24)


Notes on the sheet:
Technical Sheet Only! Please refer to the subsequent sheets for schematic
Root [0]


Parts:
C301: 1u; C_0402_1005Metric
C302, C303: 100n; C_0402_1005Metric
D301: LED; LED_0603_1608Metric
R301: 200R; R_0402_1005Metric
R302: 100R; R_0402_1005Metric
R303, R304, R305, R306: 4.7k; R_0201_0603Metric
R307, R308, R309, R310: 4.7k; R_0402_1005Metric
R311: 22R; R_0402_1005Metric
Re301, Re302: 4.7k; R_0201_0603Metric
SW301: Reset; SW_Push_SPST_NO_Alps_SKRK
TP301: N3; TestPoint_Pad_D1.0mm
TP302: M2; TestPoint_Pad_D1.0mm
TP303: M3; TestPoint_Pad_D1.0mm
TP304: L3; TestPoint_Pad_D1.0mm
TP305: K3; TestPoint_Pad_D1.0mm
U201: XC7A35T-CSG324; Xilinx_CSG324
U301: IS25LP256D; WSON-8-1EP_8.0x6.0mm_P1.27mm_EP4.7x4.6mm
Y301: 12MHz; Oscillator_SMD_Abracon_ASCO-4Pin_1.6x1.2mm

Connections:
12MHZ_CLK: R311.1, U201.C10 (IO_L13N_T2_MRCC_16)
+3V3: C302.1, C303.1, R301.1, R303.1, R304.1, R305.2, R306.1, R307.1, R308.1, R309.1, R310.1, U301.8 (VCC), Y301.1 (Tri-State), Y301.4 (VDD); also elsewhere on the board
/FPGA_Config/FPGA_DONE: R301.2, R302.1, U201.P10 (DONE_0)
/FPGA_Config/FPGA_INIT: R306.2, U201.P7 (INIT_B_0)
/FPGA_Config/FPGA_RST: C301.1, R307.2, SW301.1, U201.P9 (PROGRAM_B_0)
/FPGA_Config/MODE0: R305.1, U201.P12 (M0_0)
/FPGA_Config/MODE1: Re301.1, U201.P13 (M1_0)
/FPGA_Config/MODE2: Re302.1, U201.P11 (M2_0)
/FPGA_Config/NCS_FPGA: R310.2, U201.L13 (IO_L6P_T0_FCS_B_14), U301.1 (NCS)
/FPGA_Config/NHL_FPGA: R308.2, U201.M14 (IO_L2N_T0_D03_14), U301.7 (NHOLD)
/FPGA_Config/NWP_FPGA: R309.2, U201.L14 (IO_L2P_T0_D02_14), U301.3 (NWP)
/FPGA_Config/OSC_OUT: R311.2, Y301.3 (OUT)
/FPGA_Config/SCK_FPGA: U201.E9 (CCLK_0), U201.L16 (IO_L3N_T0_DQS_EMCCLK_14), U301.6 (SCK)
/FPGA_Config/SDI_FPGA: U201.K17 (IO_L1P_T0_D00_MOSI_14), U301.5 (SDI)
/FPGA_Config/SDO_FPGA: U201.K18 (IO_L1N_T0_D01_DIN_14), U301.2 (SDO)
GND: C301.2, C302.2, C303.2, D301.1 (K), Re301.2, Re302.2, SW301.2, U201.J9 (VREFN_0), U201.J10 (VP_0), U201.K9 (VN_0), U201.K10 (VREFP_0), U201.L9 (DXN_0), U201.L10 (DXP_0), U301.4 (GND), U301.9 (GND), Y301.2 (GND); also elsewhere on the board
unnamed: D301.2 (A), R302.2
unnamed: R303.2, U201.P8 (CFGBVS_0)
unnamed: R304.2, U201.L15 (IO_L3P_T0_DQS_PUDC_B_14)
unnamed: TP305.1 (1_1), U201.D9 (IO_L6N_T0_VREF_16)
unnamed: TP303.1 (1_1), U201.B9 (IO_L11N_T1_SRCC_16)
unnamed: TP304.1 (1_1), U201.C9 (IO_L11P_T1_SRCC_16)
unnamed: TP301.1 (1_1), U201.A8 (IO_L12N_T1_MRCC_16)
unnamed: TP302.1 (1_1), U201.B8 (IO_L12P_T1_MRCC_16)
TCK: U201.E10 (TCK_0); also elsewhere on the board
TDI: U201.E11 (TDI_0); also elsewhere on the board
TDO: U201.E13 (TDO_0); also elsewhere on the board
TMS: U201.E12 (TMS_0); also elsewhere on the board

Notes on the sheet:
Thermal diode Connect to GND id not used
Connect to ground for on-chip XADC reference (UG480)
UG470 Datasheet
Maximum power-up time delay for Flash instruction readiness is 10ms. According to the DS181 AMD datasheet, the minimum FPGA Power-On Reset TPOR is also 10ms. By implementing a capacitor on the PROGRAM_B pin of the FPGA, the startup sequence is intentionally delayed to ensure a safe margin where the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
For FLASH config outside bootloader mode
If the LED shines, the device has been configured properly!
FPGA Manual Reset
HIGH to set JTAG to 3.3V/2.5V operation (UG470)
HIGH to disable internal pullups during startup
This configuration makes the FPGA boot from SPI
Capacitor charge time is 4.7ms
Dedicated analog input. Connect to GND if not used (UG480)
FPGA Config [3]
Test Points
Additionally, there is a delay to even start the spi communication after booting the FPGA up, so we're in the clear.
Since we're not using XADC, we tie ADCGND to GND (for VP_0 and VN_0)
FPGA Configuration
External Oscillator
FPGA IOs
Configuration DONE


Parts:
C501: 10u; C_0805_2012Metric
C502, C503, C504, C505, C507, C508, C510, C511, C513, C514: 100n; C_0402_1005Metric
C509, C512: 10u; C_0603_1608Metric
C515, C516: 10p; C_0402_1005Metric
FB501, FB502: 600R; L_0402_1005Metric
R501: 1k; R_0402_1005Metric
R502, R503, R504, R505: 12k; R_0402_1005Metric
R506: 2k2; R_0402_1005Metric
R507: 22R; R_0402_1005Metric
U501: FT232H; QFN-48-1EP_8x8mm_P0.5mm_EP6.2x6.2mm
U502: 93LC56B; TDFN-8-1EP_3x2mm_P0.5mm_EP1.3x1.4mm
Y2: 12MHz; Crystal_SMD_2520-4Pin_2.5x2.0mm

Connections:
+3V3: C501.1, C502.1, C503.1, C504.1, C505.1, C514.1, FB501.2, FB502.2, R501.1, R503.2, R504.2, R505.2, U501.12 (VCCIO), U501.24 (VCCIO), U501.39 (VCCD), U501.40 (VREGIN), U501.46 (VCCIO), U502.6 (ORG), U502.8 (VCC); also elsewhere on the board
+3V3_VPHY_SER: C509.1, C510.1, FB501.1, U501.3 (VPHY)
+3V3_VPLL_SER: C512.1, C513.1, FB502.1, U501.8 (VPLL)
/Serial/EECLK: R505.1, U501.44 (EECLK), U502.2 (CLK)
/Serial/EECS: R504.1, U501.45 (EECS), U502.1 (CS)
/Serial/EEDATA: R506.2, U501.43 (EEDATA), U502.3 (DI)
/Serial/OSC_IN: C515.1, U501.1 (XCSI), Y2.1
/Serial/OSC_OUT: R507.1, U501.2 (XCSO)
GND: C501.2, C502.2, C503.2, C504.2, C505.2, C507.2, C508.2, C509.2, C510.2, C511.2, C512.2, C513.2, C514.2, C515.2, C516.2, R502.1, U501.4 (AGND), U501.9 (AGND), U501.10 (GND), U501.11 (GND), U501.22 (GND), U501.23 (GND), U501.35 (GND), U501.36 (GND), U501.41 (AGND), U501.42 (TEST), U501.47 (GND), U501.48 (GND), U501.49 (EP), U502.5 (VSS), U502.9 (EP), Y2.2 (G), Y2.4 (G); also elsewhere on the board
unnamed: C516.1, R507.2, Y2.3
unnamed: R502.2, U501.5 (REF)
unnamed: C508.1, U501.37 (VCCA)
unnamed: C507.1, U501.38 (VCCCORE)
unnamed: C511.1, R501.2, U501.34 (~RESET)
unnamed: R503.1, R506.1, U502.4 (DO)
SERIAL_CLK: U501.29 (ACBUS5); also elsewhere on the board
SERIAL_D1: U501.13 (ADBUS0); also elsewhere on the board
SERIAL_D2: U501.14 (ADBUS1); also elsewhere on the board
SERIAL_D3: U501.15 (ADBUS2); also elsewhere on the board
SERIAL_D4: U501.16 (ADBUS3); also elsewhere on the board
SERIAL_D5: U501.17 (ADBUS4); also elsewhere on the board
SERIAL_D6: U501.18 (ADBUS5); also elsewhere on the board
SERIAL_D7: U501.19 (ADBUS6); also elsewhere on the board
SERIAL_D8: U501.20 (ADBUS7); also elsewhere on the board
SERIAL_D+: U501.7 (DP); also elsewhere on the board
SERIAL_D-: U501.6 (DM); also elsewhere on the board
SERIAL_OE#: U501.30 (ACBUS6); also elsewhere on the board
SERIAL_PWR#: U501.31 (ACBUS7); also elsewhere on the board
SERIAL_RD#: U501.26 (ACBUS2); also elsewhere on the board
SERIAL_RXF#: U501.21 (ACBUS0); also elsewhere on the board
SERIAL_SIWU#: U501.28 (ACBUS4); also elsewhere on the board
SERIAL_TXE#: U501.25 (ACBUS1); also elsewhere on the board
SERIAL_WR#: U501.27 (ACBUS3); also elsewhere on the board

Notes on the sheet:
Ferrite beads must be rated at least for 600mA
Serial [5]
(10pF Load Capacitance - 5pF Stray Capacitance) * 2 = 10pF Load Capacitors
Crystal
FTDI USB-to-UART/SYNC FIFO
Filtering

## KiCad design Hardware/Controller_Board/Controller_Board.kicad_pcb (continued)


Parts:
C101, C112, C115: 10u; C_0805_2012Metric
C102, C108, C113, C116: 22u; C_1210_3225Metric
C103, C109, C114, C117: 100u; CP_Elec_5x5.9
C104, C105: 10u; C_1210_3225Metric
C106, C107: 100n; C_0805_2012Metric
C110: 2.2p; C_0402_1005Metric
C111: 10n; C_0402_1005Metric
D101: TVS/Zener; D_0603_1608Metric; not fitted
D102: LED; LED_0603_1608Metric
D103: TVS; D_0402_1005Metric
L101: 2u2; L_Coilcraft_XAL6030-XXX
Q101: DMN2400UFB-7; Diodes_DFN1006-3
R101, R108, R112: 499k; R_0402_1005Metric
R102: 12.5k; R_0402_1005Metric
R103, R110, R114: 50k; R_0402_1005Metric
R104: 1Meg; R_0402_1005Metric
R105: 1R; R_0603_1608Metric
R106: 243k; R_0402_1005Metric
R107: 41.2k; R_0402_1005Metric
R109: 62.5k; R_0402_1005Metric
R111: 280R; R_0402_1005Metric
R113: 156.3k; R_0402_1005Metric
U101, U104, U105: TPS82084; Texas_SIL0008C_MicroSiP-8-1EP_2.8x3mm_P0.65mm_EP1.1x1.9mm
U102: LT8645S; LQFN-32-6EP_6x4mm_P0.5mm_EP1.355x1.125mm
U103: TDS5311P; DFN-6-1EP_2x2mm_P0.65mm_EP1x1.6mm
U106: XT30; AMASS_XT30PW-M_1x02_P2.50mm_Horizontal

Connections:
+1V0: C102.1, C103.1, R102.1, U101.8 (VOUT); also elsewhere on the board
+1V8: C113.1, C114.1, R109.1, U104.8 (VOUT); also elsewhere on the board
+3V3: C116.1, C117.1, R113.1, U105.8 (VOUT); also elsewhere on the board
+5V: C101.1, C108.1, C109.1, C110.1, C112.1, C115.1, L101.2, R101.1, R104.1, R108.1, R111.1, R112.1, U101.1 (EN), U101.3 (VIN), U101.4 (VIN), U102.1 (BIAS), U104.3 (VIN), U104.4 (VIN), U105.3 (VIN), U105.4 (VIN); also elsewhere on the board
/Power/FB_1V0: R102.2, R103.1, U101.7 (FB)
/Power/FB_1V8: R109.2, R110.1, U104.7 (FB)
/Power/FB_3V3: R113.2, R114.1, U105.7 (FB)
/Power/FB_5V0: C110.2, R104.2, R106.1, U102.32 (FB)
/Power/PG_1V0: R101.2, U101.2 (PG), U104.1 (EN)
/Power/PG_1V8: R108.2, U104.2 (PG), U105.1 (EN)
/Power/PG_3V3: Q101.1 (G), R112.2, U105.2 (PG)
/Power/SW_5V0: L101.1, U102.12 (SW), U102.13 (SW), U102.14 (SW), U102.15 (SW), U102.16 (SW)
/Power/TR/SS: C111.1, U102.29 (TR/SS)
GND: C101.2, C102.2, C103.2, C105.2, C106.2, C107.2, C108.2, C109.2, C111.2, C112.2, C113.2, C114.2, C115.2, C116.2, C117.2, D101.2 (A), D103.1 (A1), Q101.2 (S), R103.2, R105.2, R106.2, R107.2, R110.2, R114.2, U101.5 (GND), U101.6 (GND), U101.9 (GND), U102.8 (GND), U102.9 (GND), U102.10 (GND), U102.17 (GND), U102.18 (GND), U102.19 (GND), U102.33 (GND), U102.34 (GND), U102.35 (GND), U102.36 (GND), U102.37 (GND), U102.38 (GND), U102.39 (GND), U102.40 (GND), U102.41 (GND), U102.42 (GND), U103.4 (GND), U103.5 (GND), U103.6 (GND), U103.7 (GND), U104.5 (GND), U104.6 (GND), U104.9 (GND), U105.5 (GND), U105.6 (GND), U105.9 (GND), U106.1 (GND); also elsewhere on the board
unnamed: C104.2, R105.1
unnamed: D102.2 (A), R111.2
unnamed: D102.1 (K), Q101.3 (D)
unnamed: R107.1, U102.26 (RT)
VIN: C104.1, C105.1, C106.1, C107.1, D101.1 (K), D103.2 (A2), U102.4 (VIN), U102.5 (VIN), U102.6 (VIN), U102.21 (VIN), U102.22 (VIN), U102.23 (VIN), U102.25 (EN/UV), U103.1 (VIN), U103.2 (VIN), U103.3 (VIN), U106.2 (VIN)

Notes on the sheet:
5ms soft-start
Power [1]
MAX VIN is 48V!
10mA through the LED
IO Bank Supply
Power Rail Supply
AUX Cupply
PG Indicator
Input Connector
Core Cupply


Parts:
C601: 10u; C_0805_2012Metric
C602, C603, C604, C605, C606, C607, C608, C610, C612: 100n; C_0402_1005Metric
C609, C611: 10n; C_0402_1005Metric
C613, C614: 10p; C_0402_1005Metric
D601: Schottky; D_SOD-323F
D602, D604: TVS; D_0402_1005Metric
D603: LED; LED_0603_1608Metric
J601: USB-C; USB_C_Receptacle_GCT_USB4105-xx-A_16P_TopMnt_Horizontal
R601, R604: 1k; R_0402_1005Metric
R602, R603: 5k1; R_0402_1005Metric
R605: 12k; R_0402_1005Metric
R606, R607, R608, R609, R610, R612: 100k; R_0402_1005Metric
R611: 22R; R_0402_1005Metric
U601: ESD122; X2SON-3
U602: USB2512B; QFN-36-1EP_6x6mm_P0.5mm_EP3.7x3.7mm
Y1: 24MHz; Crystal_SMD_2520-4Pin_2.5x2.0mm

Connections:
+3V3: C601.1, C602.1, C603.1, C604.1, C605.1, C606.1, C607.1, R604.1, R606.2, U602.5 (VDDA33), U602.10 (VDDA33), U602.15 (VDD33), U602.23 (VDD33), U602.29 (VDDA33), U602.36 (VDDA33); also elsewhere on the board
+5V: D601.1 (K); also elsewhere on the board
/USB/OSC_IN: C613.1, U602.33 (XTALIN), Y1.1
/USB/OSC_OUT: R611.1, U602.32 (XTALOUT)
GND: C601.2, C602.2, C603.2, C604.2, C605.2, C606.2, C607.2, C608.2, C609.2, C610.2, C611.2, C612.2, C613.2, C614.2, D602.1 (A1), D603.1 (K), D604.1 (A1), J601.A1 (GND), J601.A12 (GND), J601.B1 (GND), J601.B12 (GND), R602.1, R603.1, R605.1, R607.1, R608.1, R609.1, R612.1, U601.1 (G), U602.11 (TEST), U602.37 (EP), Y1.2 (G), Y1.4 (G); also elsewhere on the board
JTAG_D+: U602.4 (USBDP_D2+); also elsewhere on the board
JTAG_D-: U602.3 (USBDP_D2-); also elsewhere on the board
unnamed: C614.1, R611.2, Y1.3
unnamed: D603.2 (A), R601.1
unnamed: J601.A5 (CC1), R602.2
unnamed: J601.B5 (CC2), R603.2
unnamed: R607.2, U602.24 (CFG_SEL0)
unnamed: R608.2, U602.25 (CFG_SEL1)
unnamed: C611.1, C612.1, U602.14 (CRFILT)
unnamed: R609.2, U602.28 (NON_REM0)
unnamed: R606.1, U602.22 (NON_REM1)
unnamed: C608.1, R604.2, U602.26 (NRESET)
unnamed: C609.1, C610.1, U602.34 (PLLFILT)
unnamed: R605.2, U602.35 (RBIAS)
unnamed: R610.1, R612.2, U602.27 (VBUS_DET)
SERIAL_D+: U602.2 (USBDP_D1+); also elsewhere on the board
SERIAL_D-: U602.1 (USBDP_D1-); also elsewhere on the board
USB_UP_D+: J601.A6 (D+), J601.B6 (D+), U601.3 (2), U602.31 (USBUP_D+)
USB_UP_D-: J601.A7 (D-), J601.B7 (D-), U601.2 (1), U602.30 (USBUP_D-)
VBUS: D601.2 (A), D602.2 (A2), D604.2 (A2), J601.A4 (VBUS), J601.A9 (VBUS), J601.B4 (VBUS), J601.B9 (VBUS), R601.2, R610.2

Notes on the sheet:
USB [6]
NON_REM[1:0] = 10 : ports 1 and 2 are non-removable
(10pF Load Capacitance - 5pF Stray Capacitance) * 2 = 10pF Load Capacitors
OCS have internal pullup resistors Since we have non-removable devices we won't check the over-current
Crystal
USB 2.0 Connector
USB 2.0 Hub


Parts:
C201, C203, C204, C207, C208, C209, C210, C211, C212, C213, C214, C215, C216, C217, C218, C220, C221, C222, C223, C224, C225, C226, C227, C229, C230, C231, C232, C233, C235, C238, C239, C240, C241, C242, C243, C244, C245, C246, C247, C250, C251, C252, C253, C254, C255, C256, C257: 100n; C_0201_0603Metric
C205, C206, C219, C234, C237, C248, C249, C258: 10u; C_0603_1608Metric
C236: 10u; C_0805_2012Metric
FB201: 600R/100MHz; L_0201_0603Metric
U201: XC7A35T-CSG324; Xilinx_CSG324

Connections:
+1V0: C206.1, C207.1, C208.1, C209.1, C210.1, C211.1, C212.1, C220.1, C221.1, C222.1, C223.1, C224.1, C225.1, C226.1, C227.1, C249.1, C250.1, C251.1, U201.F8 (VCCINT), U201.F10 (VCCBRAM), U201.G7 (VCCINT), U201.G9 (VCCINT), U201.G11 (VCCBRAM), U201.H8 (VCCINT), U201.J7 (VCCINT), U201.J11 (VCCINT), U201.K8 (VCCINT), U201.L7 (VCCINT), U201.L11 (VCCINT), U201.M8 (VCCINT), U201.M10 (VCCINT), U201.N7 (VCCINT), U201.N9 (VCCINT), U201.N11 (VCCINT); also elsewhere on the board
+1V8: C237.1, C238.1, C239.1, C240.1, C241.1, FB201.1, U201.E8 (VCCBATT_0), U201.F12 (VCCAUX), U201.H12 (VCCAUX), U201.K12 (VCCAUX), U201.M12 (VCCAUX); also elsewhere on the board
+3V3: C203.1, C204.1, C205.1, C213.1, C214.1, C215.1, C216.1, C217.1, C218.1, C219.1, C229.1, C230.1, C231.1, C232.1, C233.1, C234.1, C235.1, C236.1, C242.1, C243.1, C244.1, C245.1, C246.1, C247.1, C248.1, C252.1, C253.1, C254.1, C255.1, C256.1, C257.1, C258.1, U201.A7 (VCCO_35), U201.A17 (VCCO_15), U201.B10 (VCCO_16), U201.C3 (VCCO_35), U201.C13 (VCCO_15), U201.D6 (VCCO_35), U201.D16 (VCCO_15), U201.F2 (VCCO_35), U201.G5 (VCCO_35), U201.G15 (VCCO_15), U201.H18 (VCCO_15), U201.J1 (VCCO_35), U201.K4 (VCCO_34), U201.K14 (VCCO_15), U201.L17 (VCCO_14), U201.N3 (VCCO_34), U201.N13 (VCCO_14), U201.P6 (VCCO_34), U201.P16 (VCCO_14), U201.R9 (VCCO_0), U201.T2 (VCCO_34), U201.T12 (VCCO_14), U201.U5 (VCCO_34), U201.U15 (VCCO_14), U201.V8 (VCCO_34), U201.V18 (VCCO_14); also elsewhere on the board
GND: C201.2, C203.2, C204.2, C205.2, C206.2, C207.2, C208.2, C209.2, C210.2, C211.2, C212.2, C213.2, C214.2, C215.2, C216.2, C217.2, C218.2, C219.2, C220.2, C221.2, C222.2, C223.2, C224.2, C225.2, C226.2, C227.2, C229.2, C230.2, C231.2, C232.2, C233.2, C234.2, C235.2, C236.2, C237.2, C238.2, C239.2, C240.2, C241.2, C242.2, C243.2, C244.2, C245.2, C246.2, C247.2, C248.2, C249.2, C250.2, C251.2, C252.2, C253.2, C254.2, C255.2, C256.2, C257.2, C258.2, U201.A2 (GND), U201.A12 (GND), U201.B5 (GND), U201.B15 (GND), U201.C8 (GND), U201.C18 (GND), U201.D1 (GND), U201.D11 (GND), U201.E4 (GND), U201.E14 (GND), U201.F7 (GND), U201.F9 (GND), U201.F11 (GND), U201.F17 (GND), U201.G8 (GND), U201.G10 (GND), U201.G12 (GND), U201.H3 (GND), U201.H7 (GND), U201.H9 (GNDADC_0), U201.H11 (GND), U201.H13 (GND), U201.J6 (GND), U201.J8 (GND), U201.J12 (GND), U201.J16 (GND), U201.K7 (GND), U201.K11 (GND), U201.L2 (GND), U201.L8 (GND), U201.L12 (GND), U201.M5 (GND), U201.M7 (GND), U201.M9 (GND), U201.M11 (GND), U201.M15 (GND), U201.N8 (GND), U201.N10 (GND), U201.N12 (GND), U201.N18 (GND), U201.P1 (GND), U201.R4 (GND), U201.R14 (GND), U201.T7 (GND), U201.T17 (GND), U201.U10 (GND), U201.V3 (GND), U201.V13 (GND); also elsewhere on the board
unnamed: C201.1, FB201.2, U201.H10 (VCCADC_0)

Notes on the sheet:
FPGA Power [2]
FPGA Power



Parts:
H1, H2, H3, H4: M3; MountingHole_3.2mm_M3_Pad_Via
R701, R702, R703, R704, R705, R706, R707, R708, R709, R710, R711, R712, R713, R714, R715, R716, R717, R718: 1k; R_0402_1005Metric
U201: XC7A35T-CSG324; Xilinx_CSG324
U701, U702, U703, U710, U711, U712, U716, U717, U718: RJ45; TE_RJ45
U704, U705, U706, U713, U714, U715, U719, U720, U721, U722, U723, U724, U725, U726, U727, U728, U729, U730: TPD4E02B04; USON-10_2.5x1.0mm_P0.5mm

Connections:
+5V: U701.3 (VCC), U702.3 (VCC), U703.3 (VCC), U710.3 (VCC), U711.3 (VCC), U712.3 (VCC), U716.3 (VCC), U717.3 (VCC), U718.3 (VCC); also elsewhere on the board
/Connectivity/P1_CLK_N: U201.R2 (IO_L15N_T2_DQS_34), U701.5 (~CLK), U704.4 (IN), U704.7 (NC)
/Connectivity/P1_CLK_P: U201.P2 (IO_L15P_T2_DQS_34), U701.4 (CLK), U704.5 (IN), U704.6 (NC)
/Connectivity/P1_RX_N: U201.V1 (IO_L7N_T1_34), U701.2 (~RX), U725.1 (IN), U725.10 (NC)
/Connectivity/P1_RX_P: U201.U1 (IO_L7P_T1_34), U701.1 (RX), U725.2 (IN), U725.9 (NC)
/Connectivity/P1_TX_N: U201.N1 (IO_L3N_T0_DQS_34), U701.7 (~TX), U704.1 (IN), U704.10 (NC)
/Connectivity/P1_TX_P: U201.N2 (IO_L3P_T0_DQS_34), U701.8 (TX), U704.2 (IN), U704.9 (NC)
/Connectivity/P2_CLK_N: U201.J18 (IO_L23N_T3_FWE_B_15), U710.5 (~CLK), U713.2 (IN), U713.9 (NC)
/Connectivity/P2_CLK_P: U201.J17 (IO_L23P_T3_FOE_B_15), U710.4 (CLK), U713.1 (IN), U713.10 (NC)
/Connectivity/P2_RX_N: U201.G17 (IO_L18N_T2_A23_15), U710.2 (~RX), U726.5 (IN), U726.6 (NC)
/Connectivity/P2_RX_P: U201.H17 (IO_L18P_T2_A24_15), U710.1 (RX), U726.4 (IN), U726.7 (NC)
/Connectivity/P2_TX_N: U201.M18 (IO_L4N_T0_D05_14), U710.7 (~TX), U713.5 (IN), U713.6 (NC)
/Connectivity/P2_TX_P: U201.L18 (IO_L4P_T0_D04_14), U710.8 (TX), U713.4 (IN), U713.7 (NC)
/Connectivity/P3_CLK_N: U201.T18 (IO_L7N_T1_D10_14), U716.5 (~CLK), U719.2 (IN), U719.9 (NC)
/Connectivity/P3_CLK_P: U201.R18 (IO_L7P_T1_D09_14), U716.4 (CLK), U719.1 (IN), U719.10 (NC)
/Connectivity/P3_RX_N: U201.P18 (IO_L9N_T1_DQS_D13_14), U716.2 (~RX), U722.5 (IN), U722.6 (NC)
/Connectivity/P3_RX_P: U201.N17 (IO_L9P_T1_DQS_14), U716.1 (RX), U722.4 (IN), U722.7 (NC)
/Connectivity/P3_TX_N: U201.U18 (IO_L17N_T2_A13_D29_14), U716.7 (~TX), U719.5 (IN), U719.6 (NC)
/Connectivity/P3_TX_P: U201.U17 (IO_L17P_T2_A14_D30_14), U716.8 (TX), U719.4 (IN), U719.7 (NC)
/Connectivity/P4_CLK_N: U201.U11 (IO_L19N_T3_A09_D25_VREF_14), U702.5 (~CLK), U705.4 (IN), U705.7 (NC)
/Connectivity/P4_CLK_P: U201.T11 (IO_L19P_T3_A10_D26_14), U702.4 (CLK), U705.5 (IN), U705.6 (NC)
/Connectivity/P4_RX_N: U201.V12 (IO_L20N_T3_A07_D23_14), U702.2 (~RX), U727.1 (IN), U727.10 (NC)
/Connectivity/P4_RX_P: U201.U12 (IO_L20P_T3_A08_D24_14), U702.1 (RX), U727.2 (IN), U727.9 (NC)
/Connectivity/P4_TX_N: U201.V9 (IO_L21N_T3_DQS_34), U702.7 (~TX), U705.1 (IN), U705.10 (NC)
/Connectivity/P4_TX_P: U201.U9 (IO_L21P_T3_DQS_34), U702.8 (TX), U705.2 (IN), U705.9 (NC)
/Connectivity/P5_CLK_N: U201.V16 (IO_L16N_T2_A15_D31_14), U711.5 (~CLK), U714.4 (IN), U714.7 (NC)
/Connectivity/P5_CLK_P: U201.V15 (IO_L16P_T2_CSI_B_14), U711.4 (CLK), U714.5 (IN), U714.6 (NC)
/Connectivity/P5_RX_N: U201.V17 (IO_L18N_T2_A11_D27_14), U711.2 (~RX), U728.1 (IN), U728.10 (NC)
/Connectivity/P5_RX_P: U201.U16 (IO_L18P_T2_A12_D28_14), U711.1 (RX), U728.2 (IN), U728.9 (NC)
/Connectivity/P5_TX_N: U201.V14 (IO_L22N_T3_A04_D20_14), U711.7 (~TX), U714.2 (IN), U714.9 (NC)
/Connectivity/P5_TX_P: U201.U14 (IO_L22P_T3_A05_D21_14), U711.8 (TX), U714.1 (IN), U714.10 (NC)
/Connectivity/P6_CLK_N: U201.V4 (IO_L10N_T1_34), U717.5 (~CLK), U720.4 (IN), U720.7 (NC)
/Connectivity/P6_CLK_P: U201.V5 (IO_L10P_T1_34), U717.4 (CLK), U720.5 (IN), U720.6 (NC)
/Connectivity/P6_RX_N: U201.V6 (IO_L20N_T3_34), U717.2 (~RX), U723.1 (IN), U723.10 (NC)
/Connectivity/P6_RX_P: U201.V7 (IO_L20P_T3_34), U717.1 (RX), U723.2 (IN), U723.9 (NC)
/Connectivity/P6_TX_N: U201.V2 (IO_L9N_T1_DQS_34), U717.7 (~TX), U720.1 (IN), U720.10 (NC)
/Connectivity/P6_TX_P: U201.U2 (IO_L9P_T1_DQS_34), U717.8 (TX), U720.2 (IN), U720.9 (NC)
/Connectivity/P7_CLK_N: U201.E1 (IO_L18N_T2_35), U703.5 (~CLK), U706.4 (IN), U706.7 (NC)
/Connectivity/P7_CLK_P: U201.F1 (IO_L18P_T2_35), U703.4 (CLK), U706.5 (IN), U706.6 (NC)
/Connectivity/P7_RX_N: U201.G1 (IO_L17N_T2_35), U703.2 (~RX), U729.1 (IN), U729.10 (NC)
/Connectivity/P7_RX_P: U201.H1 (IO_L17P_T2_35), U703.1 (RX), U729.2 (IN), U729.9 (NC)
/Connectivity/P7_TX_N: U201.C1 (IO_L16N_T2_35), U703.7 (~TX), U706.1 (IN), U706.10 (NC)
/Connectivity/P7_TX_P: U201.C2 (IO_L16P_T2_35), U703.8 (TX), U706.2 (IN), U706.9 (NC)
/Connectivity/P8_CLK_N: U201.K1 (IO_L23N_T3_35), U712.5 (~CLK), U730.4 (IN), U730.7 (NC)
/Connectivity/P8_CLK_P: U201.K2 (IO_L23P_T3_35), U712.4 (CLK), U730.5 (IN), U730.6 (NC)
/Connectivity/P8_RX_N: U201.M2 (IO_L4N_T0_34), U712.2 (~RX), U715.1 (IN), U715.10 (NC)
/Connectivity/P8_RX_P: U201.M3 (IO_L4P_T0_34), U712.1 (RX), U715.2 (IN), U715.9 (NC)
/Connectivity/P8_TX_N: U201.J2 (IO_L22N_T3_35), U712.7 (~TX), U730.1 (IN), U730.10 (NC)
/Connectivity/P8_TX_P: U201.J3 (IO_L22P_T3_35), U712.8 (TX), U730.2 (IN), U730.9 (NC)
/Connectivity/P9_CLK_N: U201.C17 (IO_L20N_T3_A19_15), U718.5 (~CLK), U724.5 (IN), U724.6 (NC)
/Connectivity/P9_CLK_P: U201.C16 (IO_L20P_T3_A20_15), U718.4 (CLK), U724.4 (IN), U724.7 (NC)
/Connectivity/P9_RX_N: U201.A18 (IO_L10N_T1_AD11N_15), U718.2 (~RX), U724.2 (IN), U724.9 (NC)
/Connectivity/P9_RX_P: U201.B18 (IO_L10P_T1_AD11P_15), U718.1 (RX), U724.1 (IN), U724.10 (NC)
/Connectivity/P9_TX_N: U201.D18 (IO_L21N_T3_DQS_A18_15), U718.7 (~TX), U721.1 (IN), U721.10 (NC)
/Connectivity/P9_TX_P: U201.E18 (IO_L21P_T3_DQS_15), U718.8 (TX), U721.2 (IN), U721.9 (NC)
GND: H1.1 (1_1), H2.1 (1_1), H3.1 (1_1), H4.1 (1_1), U701.6 (GND), U701.10 (LED2), U701.12 (LED4), U701.13 (SHD), U701.14 (SHD), U702.6 (GND), U702.10 (LED2), U702.12 (LED4), U702.13 (SHD), U702.14 (SHD), U703.6 (GND), U703.10 (LED2), U703.12 (LED4), U703.13 (SHD), U703.14 (SHD), U704.3 (GND), U704.8 (NC), U705.3 (GND), U705.8 (NC), U706.3 (GND), U706.8 (NC), U710.6 (GND), U710.10 (LED2), U710.12 (LED4), U710.13 (SHD), U710.14 (SHD), U711.6 (GND), U711.10 (LED2), U711.12 (LED4), U711.13 (SHD), U711.14 (SHD), U712.6 (GND), U712.10 (LED2), U712.12 (LED4), U712.13 (SHD), U712.14 (SHD), U713.3 (GND), U713.8 (NC), U714.3 (GND), U714.8 (NC), U715.3 (GND), U715.8 (NC), U716.6 (GND), U716.10 (LED2), U716.12 (LED4), U716.13 (SHD), U716.14 (SHD), U717.6 (GND), U717.10 (LED2), U717.12 (LED4), U717.13 (SHD), U717.14 (SHD), U718.6 (GND), U718.10 (LED2), U718.12 (LED4), U718.13 (SHD), U718.14 (SHD), U719.3 (GND), U719.8 (NC), U720.3 (GND), U720.8 (NC), U721.3 (GND), U721.8 (NC), U722.3 (GND), U722.8 (NC), U723.3 (GND), U723.8 (NC), U724.3 (GND), U724.8 (NC), U725.3 (GND), U725.8 (NC), U726.3 (GND), U726.8 (NC), U727.3 (GND), U727.8 (NC), U728.3 (GND), U728.8 (NC), U729.3 (GND), U729.8 (NC), U730.3 (GND), U730.8 (NC); also elsewhere on the board
unnamed: R701.2, U701.9 (LED1)
unnamed: R704.2, U701.11 (LED3)
unnamed: R702.2, U702.9 (LED1)
unnamed: R705.2, U702.11 (LED3)
unnamed: R703.2, U703.9 (LED1)
unnamed: R706.2, U703.11 (LED3)
unnamed: R707.2, U710.9 (LED1)
unnamed: R710.2, U710.11 (LED3)
unnamed: R708.2, U711.9 (LED1)
unnamed: R711.2, U711.11 (LED3)
unnamed: R709.2, U712.9 (LED1)
unnamed: R712.2, U712.11 (LED3)
unnamed: R713.2, U716.9 (LED1)
unnamed: R716.2, U716.11 (LED3)
unnamed: R714.2, U717.9 (LED1)
unnamed: R717.2, U717.11 (LED3)
unnamed: R715.2, U718.9 (LED1)
unnamed: R718.2, U718.11 (LED3)
P1_L1: R701.1, U201.U3 (IO_L8N_T1_34)
P1_L2: R704.1, U201.U4 (IO_L8P_T1_34)
P2_L1: R707.1, U201.R17 (IO_L12N_T1_MRCC_14)
P2_L2: R710.1, U201.P17 (IO_L12P_T1_MRCC_14)
P3_L1: R713.1, U201.R15 (IO_L13N_T2_MRCC_14)
P3_L2: R716.1, U201.R16 (IO_L15P_T2_DQS_RDWR_B_14)
P4_L1: R702.1, U201.T9 (IO_L24P_T3_A01_D17_14)
P4_L2: R705.1, U201.T10 (IO_L24N_T3_A00_D16_14)
P5_L1: R708.1, U201.T14 (IO_L14P_T2_SRCC_14)
P5_L2: R711.1, U201.T15 (IO_L14N_T2_SRCC_14)
P6_L1: R714.1, U201.U6 (IO_L22N_T3_34)
P6_L2: R717.1, U201.U7 (IO_L22P_T3_34)
P7_L1: R703.1, U201.L3 (IO_L2N_T0_34)
P7_L2: R706.1, U201.K3 (IO_L2P_T0_34)
P8_L1: R709.1, U201.P4 (IO_L14P_T2_SRCC_34)
P8_L2: R712.1, U201.P5 (IO_L13N_T2_MRCC_34)
P9_L1: R715.1, U201.A16 (IO_L8N_T1_AD10N_15)
P9_L2: R718.1, U201.A15 (IO_L8P_T1_AD10P_15)
SERIAL_CLK: U201.E3 (IO_L12P_T1_MRCC_35); also elsewhere on the board
SERIAL_D1: U201.B1 (IO_L9P_T1_DQS_AD7P_35); also elsewhere on the board
SERIAL_D2: U201.A1 (IO_L9N_T1_DQS_AD7N_35); also elsewhere on the board
SERIAL_D3: U201.B2 (IO_L10N_T1_AD15N_35); also elsewhere on the board
SERIAL_D4: U201.B3 (IO_L10P_T1_AD15P_35); also elsewhere on the board
SERIAL_D5: U201.A3 (IO_L8N_T1_AD14N_35); also elsewhere on the board
SERIAL_D6: U201.B4 (IO_L7N_T1_AD6N_35); also elsewhere on the board
SERIAL_D7: U201.A4 (IO_L8P_T1_AD14P_35); also elsewhere on the board
SERIAL_D8: U201.A5 (IO_L3N_T0_DQS_AD5N_35); also elsewhere on the board
SERIAL_OE#: U201.B7 (IO_L2P_T0_AD12P_35); also elsewhere on the board
SERIAL_PWR#: U201.A6 (IO_L3P_T0_DQS_AD5P_35); also elsewhere on the board
SERIAL_RD#: U201.E2 (IO_L14P_T2_SRCC_35); also elsewhere on the board
SERIAL_RXF#: U201.D3 (IO_L12N_T1_MRCC_35); also elsewhere on the board
SERIAL_SIWU#: U201.C4 (IO_L7P_T1_AD6P_35); also elsewhere on the board
SERIAL_TXE#: U201.D2 (IO_L14N_T2_SRCC_35); also elsewhere on the board
SERIAL_WR#: U201.D5 (IO_L11P_T1_SRCC_35); also elsewhere on the board

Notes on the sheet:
Connectivity [7]
Ethernet Connectors
FPGA IOs

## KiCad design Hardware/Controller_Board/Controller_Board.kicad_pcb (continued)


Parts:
C401: 10u; C_0805_2012Metric
C402, C403, C404, C405, C407, C408, C410, C411, C413, C414: 100n; C_0402_1005Metric
C409, C412: 10u; C_0603_1608Metric
C415, C416: 10p; C_0402_1005Metric
FB401, FB402: 600R; L_0402_1005Metric
R401: 1k; R_0402_1005Metric
R402, R403, R404, R405: 12k; R_0402_1005Metric
R406: 2k2; R_0402_1005Metric
R407: 22R; R_0402_1005Metric
U401: FT232H; QFN-48-1EP_8x8mm_P0.5mm_EP6.2x6.2mm
U402: 93LC56B; TDFN-8-1EP_3x2mm_P0.5mm_EP1.3x1.4mm
Y3: 12MHz; Crystal_SMD_2520-4Pin_2.5x2.0mm

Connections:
+3V3: C401.1, C402.1, C403.1, C404.1, C405.1, C414.1, FB401.2, FB402.2, R401.1, R403.2, R404.2, R405.2, U401.12 (VCCIO), U401.24 (VCCIO), U401.39 (VCCD), U401.40 (VREGIN), U401.46 (VCCIO), U402.6 (ORG), U402.8 (VCC); also elsewhere on the board
+3V3_VPHY_JTAG: C409.1, C410.1, FB401.1, U401.3 (VPHY)
+3V3_VPLL_JTAG: C412.1, C413.1, FB402.1, U401.8 (VPLL)
/JTAG/EECLK: R405.1, U401.44 (EECLK), U402.2 (CLK)
/JTAG/EECS: R404.1, U401.45 (EECS), U402.1 (CS)
/JTAG/EEDATA: R406.2, U401.43 (EEDATA), U402.3 (DI)
/JTAG/OSC_IN: C415.1, U401.1 (XCSI), Y3.1
/JTAG/OSC_OUT: R407.1, U401.2 (XCSO)
GND: C401.2, C402.2, C403.2, C404.2, C405.2, C407.2, C408.2, C409.2, C410.2, C411.2, C412.2, C413.2, C414.2, C415.2, C416.2, R402.1, U401.4 (AGND), U401.9 (AGND), U401.10 (GND), U401.11 (GND), U401.22 (GND), U401.23 (GND), U401.35 (GND), U401.36 (GND), U401.41 (AGND), U401.42 (TEST), U401.47 (GND), U401.48 (GND), U401.49 (EP), U402.5 (VSS), U402.9 (EP), Y3.2 (G), Y3.4 (G); also elsewhere on the board
JTAG_D+: U401.7 (DP); also elsewhere on the board
JTAG_D-: U401.6 (DM); also elsewhere on the board
unnamed: C416.1, R407.2, Y3.3
unnamed: R402.2, U401.5 (REF)
unnamed: C408.1, U401.37 (VCCA)
unnamed: C407.1, U401.38 (VCCCORE)
unnamed: C411.1, R401.2, U401.34 (~RESET)
unnamed: R403.1, R406.1, U402.4 (DO)
TCK: U401.13 (ADBUS0); also elsewhere on the board
TDI: U401.14 (ADBUS1); also elsewhere on the board
TDO: U401.15 (ADBUS2); also elsewhere on the board
TMS: U401.16 (ADBUS3); also elsewhere on the board

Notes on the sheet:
Ferrite beads must be rated at least for 600mA
JTAG [4]
(10pF Load Capacitance - 5pF Stray Capacitance) * 2 = 10pF Load Capacitors
VREGIN = 5V -> VCCD = 3.3V OUTPUT VREGIN = 3.3V -> VCCD = 3.3V INPUT
FTDI USB-to-JTAG
Filtering
Crystal



Board: 6 copper layers, 85.0 x 85.0 mm, 262 parts (120 on the bottom side), 200 nets.

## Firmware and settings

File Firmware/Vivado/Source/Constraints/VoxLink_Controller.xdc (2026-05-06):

###################################################################
#  Configuration
###################################################################

set_property CFGBVS VCCO [current_design]

set_property CONFIG_VOLTAGE 3.3 [current_design]

###################################################################
#  General Signals
###################################################################

# Clock Input
set_property PACKAGE_PIN C11 [get_ports clk_12mhz]
set_property IOSTANDARD LVCMOS33 [get_ports clk_12mhz]

# !!! WARNING ALL ETHERNET PINS ARE REFERENCED TO BOARD SILKSCREEN, NOT THE SCHEMATIC NAMING !!!
# !!! WARNING ALL ETHERNET PINS ARE REFERENCED TO BOARD SILKSCREEN, NOT THE SCHEMATIC NAMING !!!
# !!! WARNING ALL ETHERNET PINS ARE REFERENCED TO BOARD SILKSCREEN, NOT THE SCHEMATIC NAMING !!!

###################################################################
#  BANK 14
###################################################################

# set_property PACKAGE_PIN L18 [get_ports P8_TX_P]
# set_property IOSTANDARD LVCMOS33 [get_ports P8_TX_P]
# set_property PACKAGE_PIN M18 [get_ports P8_TX_N]
# set_property IOSTANDARD LVCMOS33 [get_ports P8_TX_N]

# set_property PACKAGE_PIN R18 [get_ports P7_CLK_P]
# set_property IOSTANDARD LVCMOS33 [get_ports P7_CLK_P]
# set_property PACKAGE_PIN T18 [get_ports P7_CLK_N]
# set_property IOSTANDARD LVCMOS33 [get_ports P7_CLK_N]

# set_property PACKAGE_PIN N17 [get_ports P7_RX_P]
# set_property IOSTANDARD LVCMOS33 [get_ports P7_RX_P]
# set_property PACKAGE_PIN P18 [get_ports P7_RX_N]
# set_property IOSTANDARD LVCMOS33 [get_ports P7_RX_N]

# set_property PACKAGE_PIN V15 [get_ports P6_CLK_P]
# set_property IOSTANDARD LVCMOS33 [get_ports P6_CLK_P]
# set_property PACKAGE_PIN V16 [get_ports P6_CLK_N]
# set_property IOSTANDARD LVCMOS33 [get_ports P6_CLK_N]

# set_property PACKAGE_PIN U17 [get_ports P7_TX_P]
# set_property IOSTANDARD LVCMOS33 [get_ports P7_TX_P]
# set_property PACKAGE_PIN U18 [get_ports P7_TX_N]
# set_property IOSTANDARD LVCMOS33 [get_ports P7_TX_N]

# set_property PACKAGE_PIN U16 [get_ports P6_RX_P]
# set_property IOSTANDARD LVCMOS33 [get_ports P6_RX_P]
# set_property PACKAGE_PIN V17 [get_ports P6_RX_N]
# set_property IOSTANDARD LVCMOS33 [get_ports P6_RX_N]

# set_property PACKAGE_PIN T11 [get_ports P5_CLK_P]
# set_property IOSTANDARD LVCMOS33 [get_ports P5_CLK_P]
# set_property PACKAGE_PIN U11 [get_ports P5_CLK_N]
# set_property IOSTANDARD LVCMOS33 [get_ports P5_CLK_N]

# set_property PACKAGE_PIN U12 [get_ports P5_RX_P]
# set_property IOSTANDARD LVCMOS33 [get_ports P5_RX_P]
# set_property PACKAGE_PIN V12 [get_ports P5_RX_N]
# set_property IOSTANDARD LVCMOS33 [get_ports P5_RX_N]

# set_property PACKAGE_PIN U14 [get_ports P6_TX_P]
# set_property IOSTANDARD LVCMOS33 [get_ports P6_TX_P]
# set_property PACKAGE_PIN V14 [get_ports P6_TX_N]
# set_property IOSTANDARD LVCMOS33 [get_ports P6_TX_N]

# LED Pins (Bank 14)
# set_property PACKAGE_PIN R17 [get_ports P8_L1]
# set_property IOSTANDARD LVCMOS33 [get_ports P8_L1]
# set_property PACKAGE_PIN P17 [get_ports P8_L2]
# set_property IOSTANDARD LVCMOS33 [get_ports P8_L2]

# set_property PACKAGE_PIN R15 [get_ports P7_L1]
# set_property IOSTANDARD LVCMOS33 [get_ports P7_L1]
# set_property PACKAGE_PIN R16 [get_ports P7_L2]
# set_property IOSTANDARD LVCMOS33 [get_ports P7_L2]

# set_property PACKAGE_PIN T9 [get_ports P5_L1]
# set_property IOSTANDARD LVCMOS33 [get_ports P5_L1]
# set_property PACKAGE_PIN T10 [get_ports P5_L2]
# set_property IOSTANDARD LVCMOS33 [get_ports P5_L2]

# set_property PACKAGE_PIN T14 [get_ports P6_L1]
# set_property IOSTANDARD LVCMOS33 [get_ports P6_L1]
# set_property PACKAGE_PIN T15 [get_ports P6_L2]
# set_property IOSTANDARD LVCMOS33 [get_ports P6_L2]

# !!! WARNING ALL ETHERNET PINS ARE REFERENCED TO BOARD SILKSCREEN, NOT THE SCHEMATIC NAMING !!!
# !!! WARNING ALL ETHERNET PINS ARE REFERENCED TO BOARD SILKSCREEN, NOT THE SCHEMATIC NAMING !!!
# !!! WARNING ALL ETHERNET PINS ARE REFERENCED TO BOARD SILKSCREEN, NOT THE SCHEMATIC NAMING !!!

###################################################################
#  BANK 15
###################################################################

# set_property PACKAGE_PIN B18 [get_ports P9_RX_P]
# set_property IOSTANDARD LVCMOS33 [get_ports P9_RX_P]
# set_property PACKAGE_PIN A18 [get_ports P9_RX_N]
# set_property IOSTANDARD LVCMOS33 [get_ports P9_RX_N]

# set_property PACKAGE_PIN H17 [get_ports P8_RX_P]
# set_property IOSTANDARD LVCMOS33 [get_ports P8_RX_P]
# set_property PACKAGE_PIN G17 [get_ports P8_RX_N]
# set_property IOSTANDARD LVCMOS33 [get_ports P8_RX_N]

# set_property PACKAGE_PIN C16 [get_ports P9_CLK_P]
# set_property IOSTANDARD LVCMOS33 [get_ports P9_CLK_P]
# set_property PACKAGE_PIN C17 [get_ports P9_CLK_N]
# set_property IOSTANDARD LVCMOS33 [get_ports P9_CLK_N]
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

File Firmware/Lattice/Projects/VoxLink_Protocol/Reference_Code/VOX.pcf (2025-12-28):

# ##############################################################################

# iCEcube PCF

# Version:            2020.12.27943

# File Generated:     Dec 26 2025 18:03:53

# Family & Device:    iCE40UL1K

# Package:            CM36A

# ##############################################################################

# General
set_io clk          C2

# SPI Flash
set_io flash_mosi   F6
set_io flash_miso   E5
set_io flash_sck    E6
set_io flash_cs_n   F5

# LED
set_io led_io       A2
set_io led_rx       B1
set_io led_tx       A1

# Sensor
set_io bno_sda      D6
set_io bno_scl      C6
set_io bno_rst_n    B6

# VoxLink
set_io vox_clk_p    E2
set_io vox_clk_n    F3

set_io vox_rx_p     F1
set_io vox_rx_n     E1

set_io vox_tx_p     D1
set_io vox_tx_n     C1

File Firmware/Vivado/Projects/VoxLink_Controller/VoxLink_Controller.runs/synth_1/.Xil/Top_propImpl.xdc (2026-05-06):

set_property SRC_FILE_INFO {cfile:C:/BachelorProject/VoxLink/Firmware/Vivado/Source/Constraints/VoxLink_Controller.xdc rfile:../../../../../Source/Constraints/VoxLink_Controller.xdc id:1} [current_design]
set_property src_info {type:XDC file:1 line:14 export:INPUT save:INPUT read:READ} [current_design]
set_property PACKAGE_PIN C11 [get_ports clk_12mhz]
set_property src_info {type:XDC file:1 line:145 export:INPUT save:INPUT read:READ} [current_design]
set_property PACKAGE_PIN U1 [get_ports P3_RX_P]
set_property src_info {type:XDC file:1 line:149 export:INPUT save:INPUT read:READ} [current_design]
set_property PACKAGE_PIN V1 [get_ports P3_RX_N]
set_property src_info {type:XDC file:1 line:154 export:INPUT save:INPUT read:READ} [current_design]
set_property PACKAGE_PIN P2 [get_ports P3_CLK_P]
set_property src_info {type:XDC file:1 line:158 export:INPUT save:INPUT read:READ} [current_design]
set_property PACKAGE_PIN R2 [get_ports P3_CLK_N]
set_property src_info {type:XDC file:1 line:184 export:INPUT save:INPUT read:READ} [current_design]
set_property PACKAGE_PIN U3 [get_ports P3_L1]
set_property src_info {type:XDC file:1 line:186 export:INPUT save:INPUT read:READ} [current_design]
set_property PACKAGE_PIN U4 [get_ports P3_L2]
set_property src_info {type:XDC file:1 line:199 export:INPUT save:INPUT read:READ} [current_design]
set_property PACKAGE_PIN P4 [get_ports P2_L1]
set_property src_info {type:XDC file:1 line:201 export:INPUT save:INPUT read:READ} [current_design]
set_property PACKAGE_PIN P5 [get_ports P2_L2]
set_property src_info {type:XDC file:1 line:239 export:INPUT save:INPUT read:READ} [current_design]
set_property PACKAGE_PIN A1 [get_ports SERIAL_D2]
set_property src_info {type:XDC file:1 line:241 export:INPUT save:INPUT read:READ} [current_design]
set_property PACKAGE_PIN B1 [get_ports SERIAL_D1]
set_property src_info {type:XDC file:1 line:262 export:INPUT save:INPUT read:READ} [current_design]
set_property PACKAGE_PIN J4 [get_ports P2_RX_P]
set_property src_info {type:XDC file:1 line:264 export:INPUT save:INPUT read:READ} [current_design]
set_property PACKAGE_PIN H4 [get_ports P2_RX_N]
set_property src_info {type:XDC file:1 line:272 export:INPUT save:INPUT read:READ} [current_design]
set_property PACKAGE_PIN K2 [get_ports P2_CLK_P]
set_property src_info {type:XDC file:1 line:274 export:INPUT save:INPUT read:READ} [current_design]
set_property PACKAGE_PIN K1 [get_ports P2_CLK_N]

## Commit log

2025-10-24 Introduced KiCad project files for the sensor side FPGA board design
    [VoxLink.kicad_pcb, VoxLink.kicad_sch]
2025-11-06 Created the Hardware Design section outlining the hardware design process. Added section for controlled impedance calculation and included a High Level Overview section with a block diagram of the sy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
    [VoxLink.kicad_sch]
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2025-11-10 Finished the FPGA Pinout in KiCad and started routing the Power section. Created the TinyFPGA_BringUp project in iCEcube2 IDE to test familiarize myself with the Lattice toolchain.
    [VoxLink.kicad_sch, power.kicad_sch]
2025-11-21 Added schematic sections and advanced the design. Advanced the development of Verilog code, for TinyFPGA bringup (however, still not working). Cosmetic changes in README.
    [Sensor.kicad_sch, System.kicad_sch, VoxLink.kicad_sch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]
2025-12-04 Finished the schematic design.
    [Sensor.kicad_sch, System.kicad_sch, VoxLink.kicad_sch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]
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2025-12-05 Cleared ERC errors and improved folder structure
    [Sensor.kicad_sch, System.kicad_sch, VoxSense.kicad_pcb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]
2025-12-09 Fixed minor bugs in the schematic and updated the documentation.
    [Sensor.kicad_sch, System.kicad_sch, power.kicad_sch]
2025-12-13 Added a programmer schematic
    [Programmer_Board.kicad_pcb, Programmer_Board.kicad_sch, System.kicad_sch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]
2025-12-18 Added documantation regarding the programmer board and updated the PDF schematics.
    [System.kicad_sch]
2025-12-21 Pushing before updating KiCad
    [MV_ADC_UART_pin_table.CSV, MV_ADC_UART_sbt.sdf, MV_ADC_UART_sbt_vital.sdf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]
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2025-12-23 Finised the design of the sensor board :)
    [Sensor.kicad_sch, System.kicad_sch, VoxSense.kicad_pcb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]
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2025-12-26 Finished design of both programmer and sensor board PCBs
    [Programmer_Board.kicad_pcb, VoxSense.kicad_pcb, efuse.kicad_sch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]
2025-12-28 Finished final PCB checks before manufacturing and uploaded the fabrication files
    [Programmer_Board-B_Cu.gbr, Programmer_Board-B_Mask.gbr, Programmer_Board-B_Silkscreen.gbr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]
2025-12-29 Updated documentation and finished first iteration of PCB rework based on manufacturer feedback.
    [Programmer_Board-B_Cu.gbr, Programmer_Board-B_Mask.gbr, Programmer_Board-B_Silkscreen.gbr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]
2026-01-03 Commited the final manufacturing files, as well as updated the documentation
    [Programmer_Sensor_Stencil.kicad_pcb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]
2026-01-15 Added comments to the schematic, updated documentation with the board bringup, and wrote the VoxLink Verilog blink sketch.
    [System.kicad_sch, Top_pin_table.CSV, Top_sbt.sdf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]
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2026-02-25 * Created an I2C driver and a basic BNO protocol sequence implementation reading the advertisement message. * Created a Vivado project with simulation for the iCE40UL1K FPGA.
    [MV_ADC_UART_pin_table.CSV, MV_ADC_UART_sbt.sdf, MV_ADC_UART_sbt_vital.sdf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]
2026-02-25 Added the BNO Subscription Stage in the BNO Driver
    [Top_pin_table.CSV, Top_sbt.sdf, Top_sbt_vital.sdf]
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2026-02-28 Updated the data readout logic in the BNO driver.
    [Top_pin_table.CSV, Top_sbt.sdf, Top_sbt_vital.sdf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]
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2026-03-06 Finished testing the readout. Uploaded the correct Vivado Vox Readout files. Please note that the testing Vox files were copied from another directory and may require assigning new paths in Vivado.
    [Top_propImpl.xdc]
2026-03-07 Controller Development Initialization Began designing the power stage for the controller board.
    [Controller_Board.kicad_pcb, Controller_Board.kicad_sch, power.kicad_sch]
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2026-03-12 Updated the schematic design - Fix the XC7A35T-CPG236 outline issue
    [Controller_Board.kicad_pcb, Controller_Board.kicad_sch, connectivity.kicad_sch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]
2026-03-13 Fixed the bug in the FPGA symbol I have unchecked these boxes in the symbol properties and settings for the individual shapes -All units are interchangeable -Common to all units
    [fpga_config.kicad_sch, fpga_power.kicad_sch]
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2026-03-17 Updated the documentation + minor scheme changes - Documented the schematic design - Added zener diode from USB VBUS to 5V
    [connectivity.kicad_sch, power.kicad_sch, usb.kicad_sch]
2026-03-20 Started schematic rework and the PCB design
    [Controller_Board.kicad_pcb, connectivity.kicad_sch, fpga_config.kicad_sch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]
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2026-03-21 Converted to 10.0 KiCad schematic + Began BGA fan
    [Controller_Board.kicad_pcb, Controller_Board.kicad_sch, connectivity.kicad_sch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]
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2026-03-23 Advanced PCB design: Routed FTDIs + SPI Flash
    [Controller_Board.kicad_pcb, connectivity.kicad_sch, fpga_config.kicad_sch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]
2026-03-24 Advanced PCB design - Routed FTDI chips + USB HUB
    [Controller_Board.kicad_pcb, connectivity.kicad_sch, fpga_config.kicad_sch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]
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2026-03-28 Finished PCB Design - WARNING MORE CHANGES NEEDED! The main decision to be made is, whether to increase the layer count to 8 layers, and make the P7 and P8 permamently on 3V3
    [Controller_Board.kicad_sch, connectivity.kicad_sch, fpga_config.kicad_sch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]
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2026-03-31 Commit with restored changes after KiCad crash
    [Connectivity.kicad_sch, Core_Module.kicad_pcb, Core_Module_Intel.kicad_pcb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]
2026-03-31 Wrapping up for today. Almost reworked core module
    [Core_Module.kicad_pcb]
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2026-04-02 Finished All Schemes, Waiting for Design Review !!! CONTROLLER BOARD STILL NEEDS TO HAVE THE POWER SECTION UPDATED !!! + programmer PCB needed
    [Connectivity.kicad_sch, Core_Module.kicad_pcb, Core_Module.kicad_sch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]
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2026-04-05 Finished procuring almost all boards - CHANGED XDC IN XILINX FOR TESTING!! - Programmer needed
    [Core_Module.kicad_pcb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]
2026-04-09 Finished PCB design and Review + Procured Boards
    [Controller_Board-B_Cu.gbr, Controller_Board-B_Mask.gbr, Controller_Board-B_Paste.gbr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]
2026-04-14 Commiting Block 1 progress. Finished CRC and Time
    [Top_pin_table.CSV, Top_sbt.sdf, Top_sbt_vital.sdf]
2026-04-20 Fixed bug in plottying.py + updated KiCad 9 files
    [Programmer_Board.kicad_pcb, Sensor.kicad_sch, Sensor_Module.kicad_pcb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]
2026-04-22 Implemented CRC onto the Xilinx FPGA + bug fixes
    [Top_pin_table.CSV, Top_sbt.sdf, Top_sbt_vital.sdf]
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2026-04-28 Commit before changing Git folder absolute path - Changes in the reg_multiplexer data width not reflected from the current version - Apparently I don't have CRC implemented
    [Top_pin_table.CSV, Top_sbt.sdf, Top_sbt_vital.sdf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]
2026-04-29 Fixed sensor spiking by implementing Core I2C CDC - Latest version of the single VoxNode implementation - Final commit before multinode firmware development
    [Top_pin_table.CSV, Top_sbt.sdf, Top_sbt_vital.sdf]
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2026-05-01 Advanced Multinode Development - Added FIFO - Commiting before FIFO reset addition update
    [Top_pin_table.CSV, Top_sbt.sdf, Top_sbt_vital.sdf]
2026-05-02 Fixed protocol retransmission logic with timeout
    [Top_pin_table.CSV, Top_sbt.sdf, Top_sbt_vital.sdf]
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2026-05-03 Finished initialization sequence integration. - Now, Python can ask the Controller Baord the number of nodes after initialization
    [VoxLink_Protocol_Top_timingviewer.cfg]
2026-05-04 First working iteration of the Multinode Protocol - Debugging and testing still needed - Tested only for 2 board - Currently, the Python code requests each sensor data: make a common readout for all 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
    [Top_pin_table.CSV, Top_sbt.sdf, Top_sbt_vital.sdf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]
2026-05-06 VoxLink was made to run at 21MHz - timing issues
    [Top_pin_table.CSV, Top_sbt.sdf, Top_sbt_vital.sdf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]
2026-05-07 New firmware which is difficult to brick - I don't know what has happened, but the amount of EMI bricks reduced dramatically after I added the NACK sticky connection to the LED - Also connected BNO N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
    [Top_pin_table.CSV, Top_sbt.sdf, Top_sbt_vital.sdf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]
2026-05-07 Added controller timeout and rollbacked Lattice - Added controller timeout - Rollbacked lattice to the last commit but git treats files as new additions - Added plotting software
    [Top_pin_table.CSV, Top_sbt.sdf, Top_sbt_vital.sdf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]
